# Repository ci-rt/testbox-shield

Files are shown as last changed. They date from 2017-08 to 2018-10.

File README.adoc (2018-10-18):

= TESTBOX
:toc:
:toclevels: 3

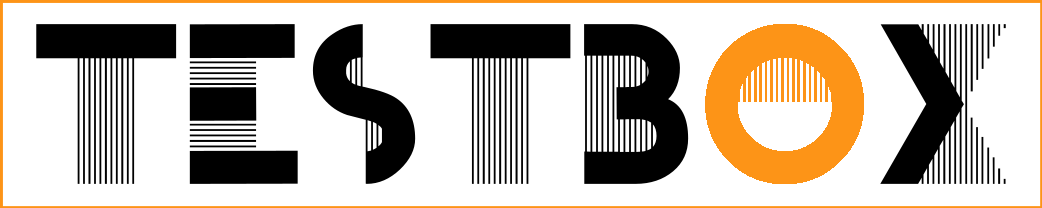
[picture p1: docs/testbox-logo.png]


This git repository hosts all related drawings, layouts and schematics
to build a TESTBOX test system.

But it doesn't include the project specific libraries. However they are
referenced as git submodules. To retrieve them use 'git submodule init' and
'git submodule update' before opening the project in kicad.

The project was verified to work with kicad version 5.

== preliminary remarks
One part of the Real Time Linux collaborative project is the continous
integration project https://ci-rt.linutronix.de/RT-Test/[CI-RT].

One part of the testsuite performs different tests on the devices under test
(DUT). To ease the hardware integration of the DUT to the test infrastructure
the DUT need to comply with some
https://ci-rt.linutronix.de/download/system-requirements.pdf[hardware
requirements].

It turned out that some DUTs need special hardware extensions to meet the
test infrastructure hardware requirements. Furthermore the wish for hardware
assisted tests grow up.

The idea of a standardized adaption system was born: the TESTBOX.

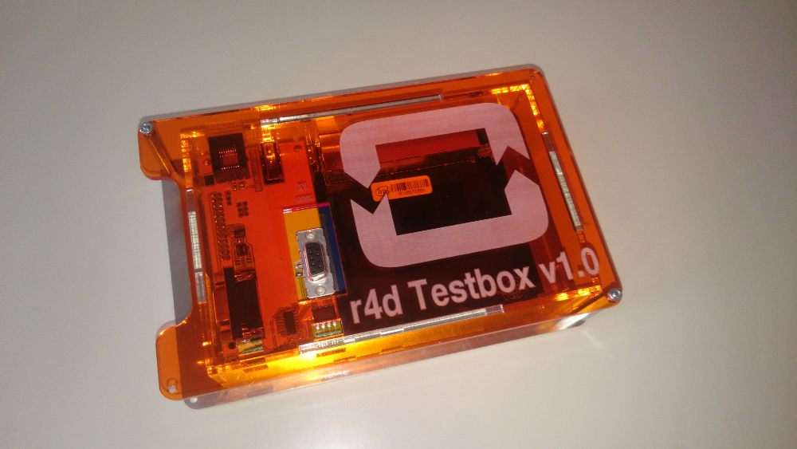
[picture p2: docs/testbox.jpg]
picture of the testbox


== hardware
The TESTBOX is based on the http://www.banana-pi.org/r1.html[Banana Pi R1
router board]. This board includes several physical interfaces:

 * 5-port Ethernet Switch
 * CAN
 * GPIOs
 * I2C
 * RS232
 * SPI
 * USB

The board is supported by the mainline
https://git.kernel.org/pub/scm/linux/kernel/git/stable/linux-stable.git/tree/arch/arm/boot/dts/sun7i-a20-lamobo-r1.dts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[Linux Kernel].
Since most interfaces are routed to pinheaders and lack of a physical adaption
a board shield was developed and is now available in version 2.

http://kicad-pcb.org[KiCAD] is used to create all schematics and the layout.

=== shield
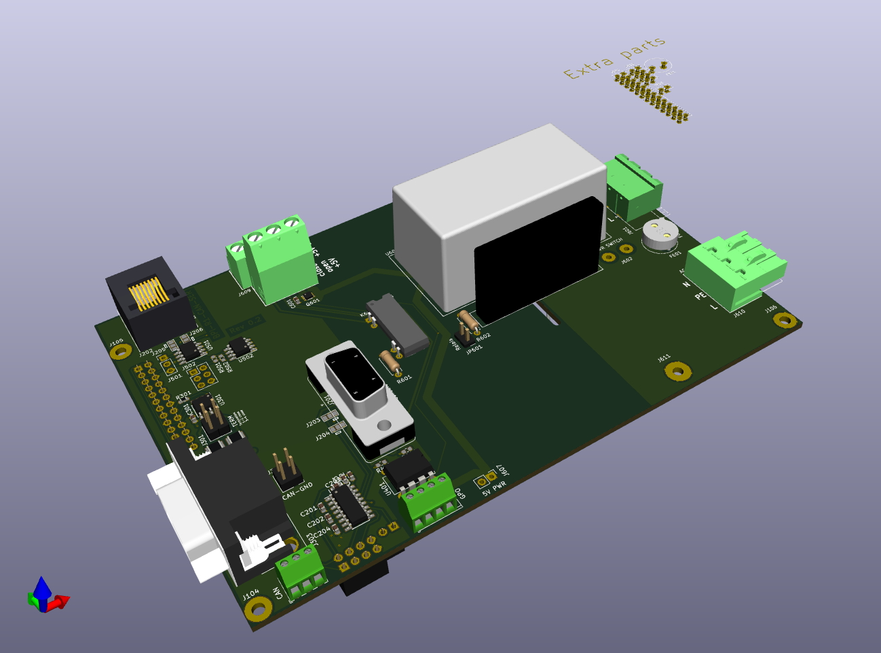
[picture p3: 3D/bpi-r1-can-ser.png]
picture of shield


Changes in version 2 of the shield:

 * 5V DC Powersupply added
 * 240V AC Powerswitch added
 * relay added
 * serial EEPROM added
 * secure store for private keys added (ATECC)
 * minor fixes

==== 3D model
A VRML model of the shield is also link:3D/bpi-r1-can-ser.wrl[available].

==== schematic
The complete schematic is available as
link:schematic/bpi-r1-can-ser.pdf[PDF].

===== overview
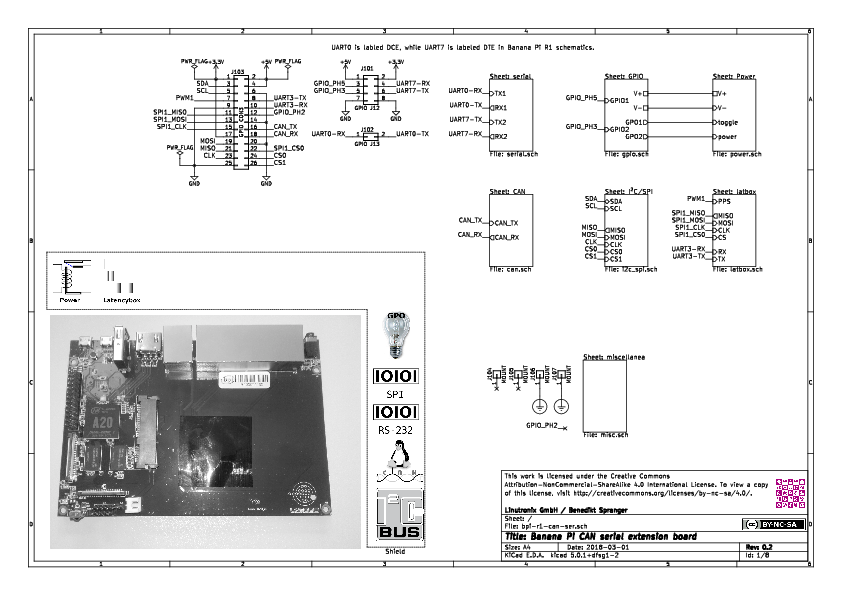
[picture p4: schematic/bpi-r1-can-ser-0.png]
schematic overview


===== serial ports
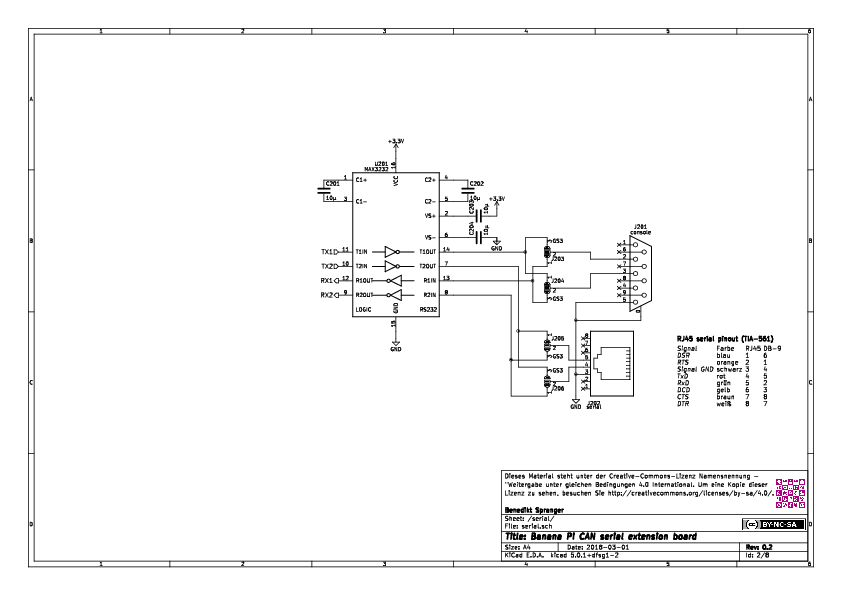
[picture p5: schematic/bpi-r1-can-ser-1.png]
serial port schematic


===== CAN interface
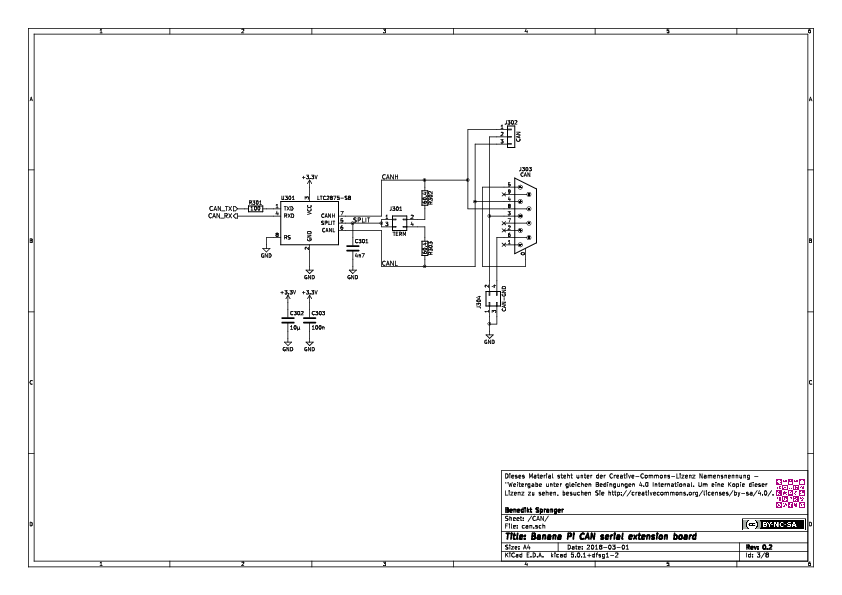
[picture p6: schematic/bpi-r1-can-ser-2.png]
CAN interface schematic


===== general purpose output
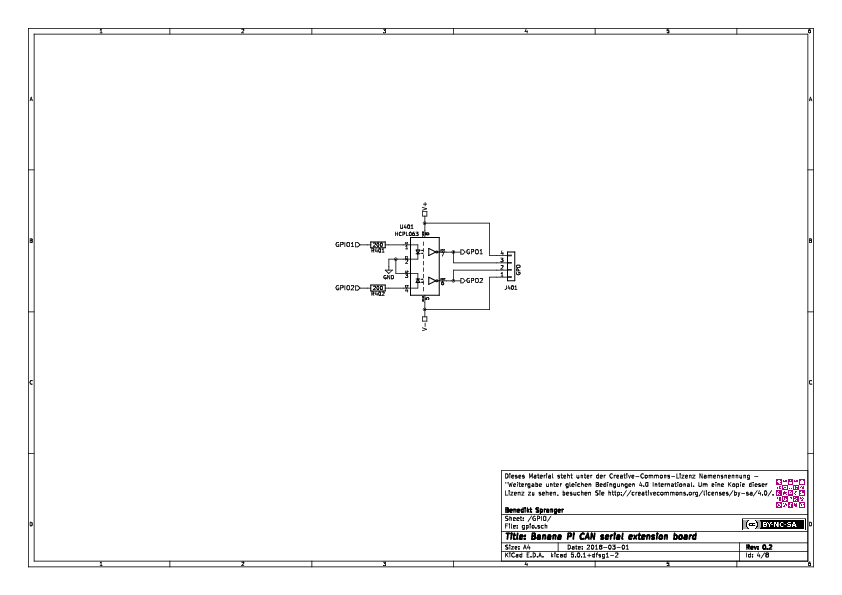
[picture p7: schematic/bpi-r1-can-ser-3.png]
GPO schematic


===== I2C / SPI
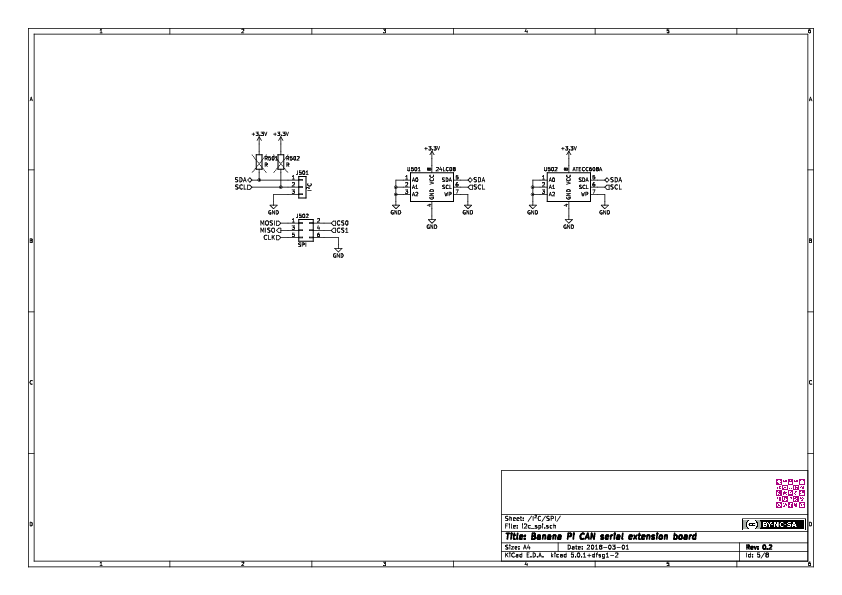
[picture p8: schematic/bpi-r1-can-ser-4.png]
I2C and SPI schematic


===== Power
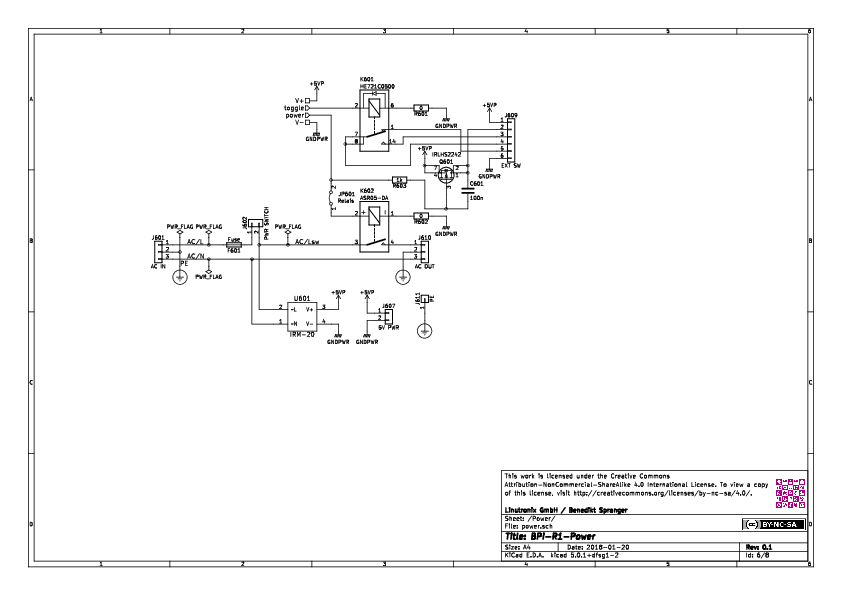
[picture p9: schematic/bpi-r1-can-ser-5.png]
I2C and SPI schematic


===== latbox (not implemented)
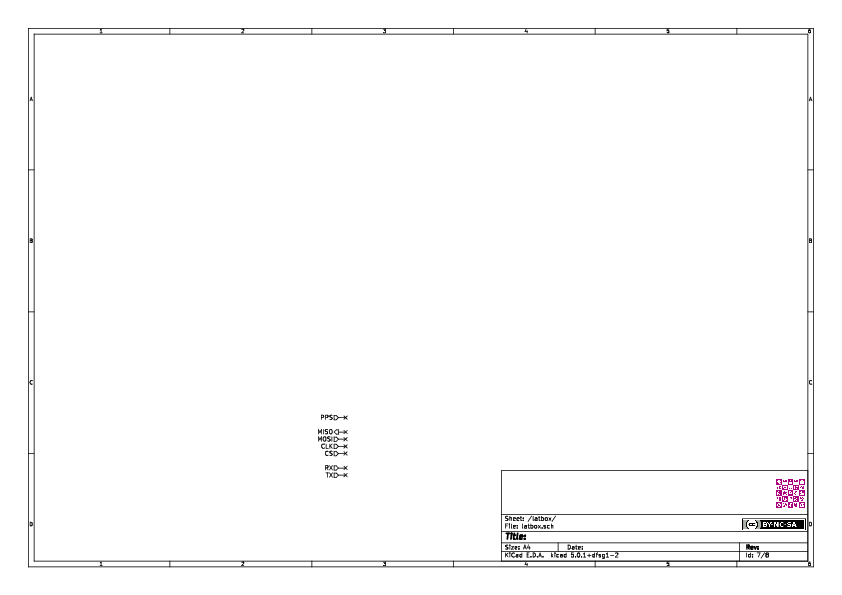
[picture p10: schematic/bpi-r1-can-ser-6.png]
I2C and SPI schematic


===== miscellanea
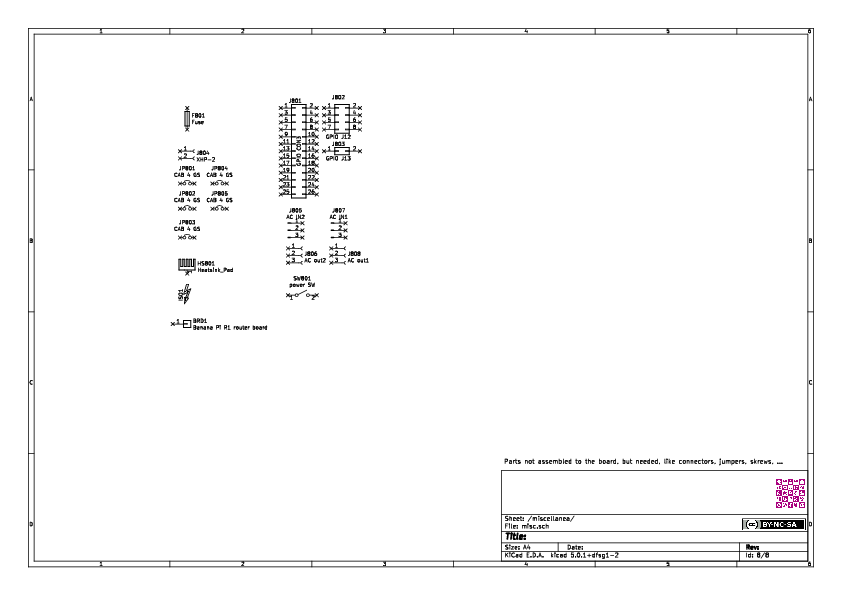
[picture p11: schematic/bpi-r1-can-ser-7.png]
I2C and SPI schematic


==== gerber
===== PCB edges and cuts
edges and cuts

===== top copper layer
PCB top layer

===== top silk screen
PCB top silk screen

===== bottom copper layer
PCB bottom copper layer

===== bottom silk screen
PCB bottom silk screen

==== Errata
===== TIA-561 serial port
The pinout of the RJ-45 connector was mixed up (off by one)

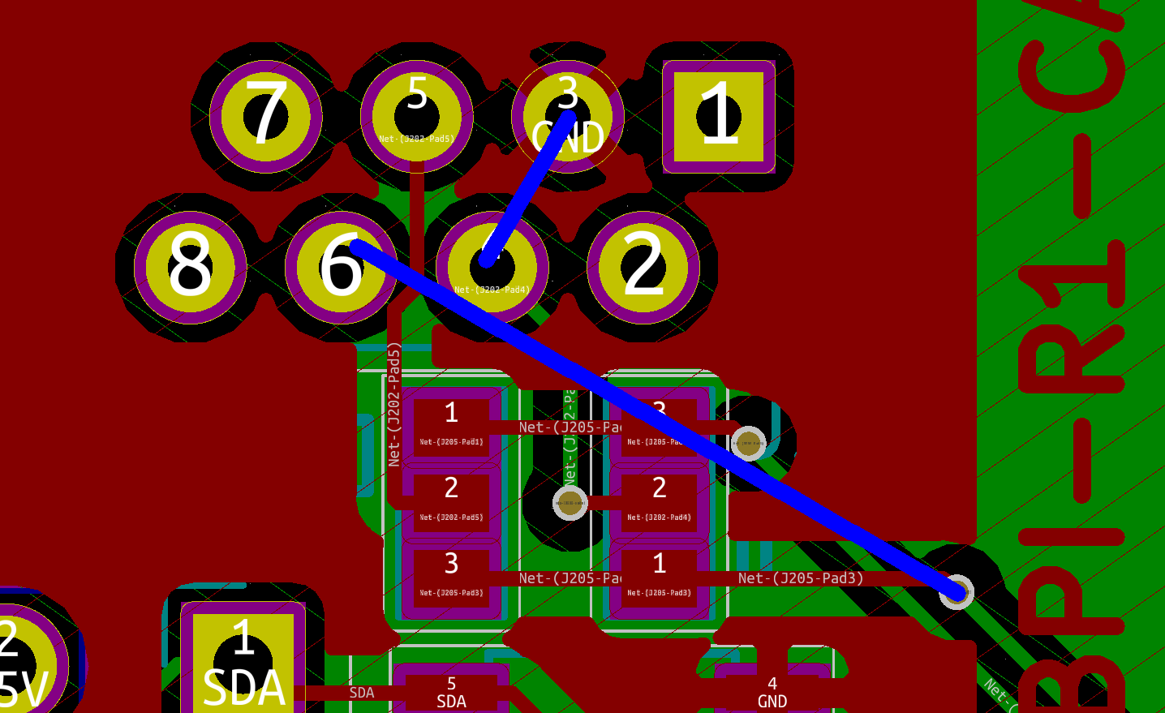
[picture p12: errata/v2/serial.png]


===== GPO
The optocoupler is open collector and not TTL. Add 100 Ohm pullups.

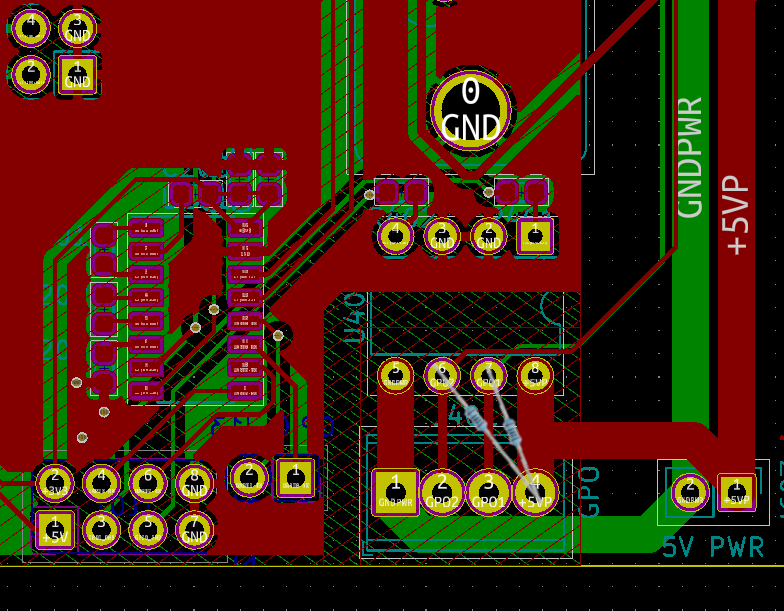
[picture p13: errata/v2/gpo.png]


== software
To create the root file system of the TESTBOX http://elbe-rfs.org/[E.L.B.E.]
is used. E.L.B.E. provides a reproducable way to create
http://debian.org[Debian-based] root file systems.

=== E.L.B.E. root file system
The receipe to build a root file system for the TESTBOX can be found under
https://github.com/ci-rt/testbox-rfs[].

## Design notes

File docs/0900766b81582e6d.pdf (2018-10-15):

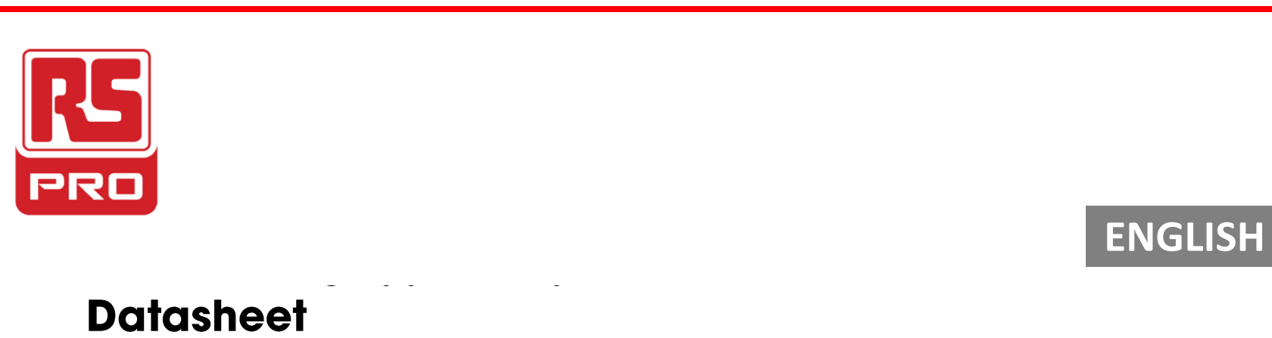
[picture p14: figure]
EN ENGLISH

RS Stock number 785-0827

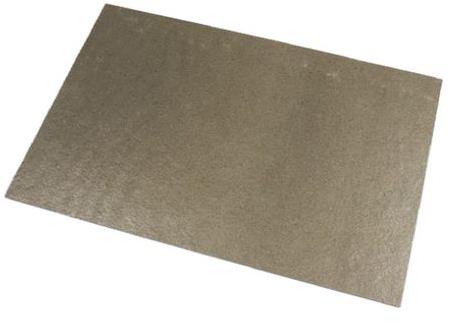
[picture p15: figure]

RS, Professionally Approved Products, gives you professional quality parts across all products categories. Our range has been testified by engineers as giving comparable quality to that of the leading brands without paying a premium price.

Description
Mica is a laminate designed for providing outstanding electrical insulation at high temperatures. It is environmentally safe and non-toxic, certified by UL-94V-0 (E67143M) and conforming to IEC 371-3-3

Applications
A special low smoke and blister free grade. It fully resists the extreme high temperature cycles and can be easily cut or punched.

Availability
Various sheet sizes, 0.1 – 1.5mm thick

Storage
Unlimited shelf life in a dry place at room temperature

RS, Professionally Approved Products, gives you professional quality parts across all products categories. Our range has been testified by engineers as giving comparable quality to that of the leading brands without paying a premium price.

## ENGLISH

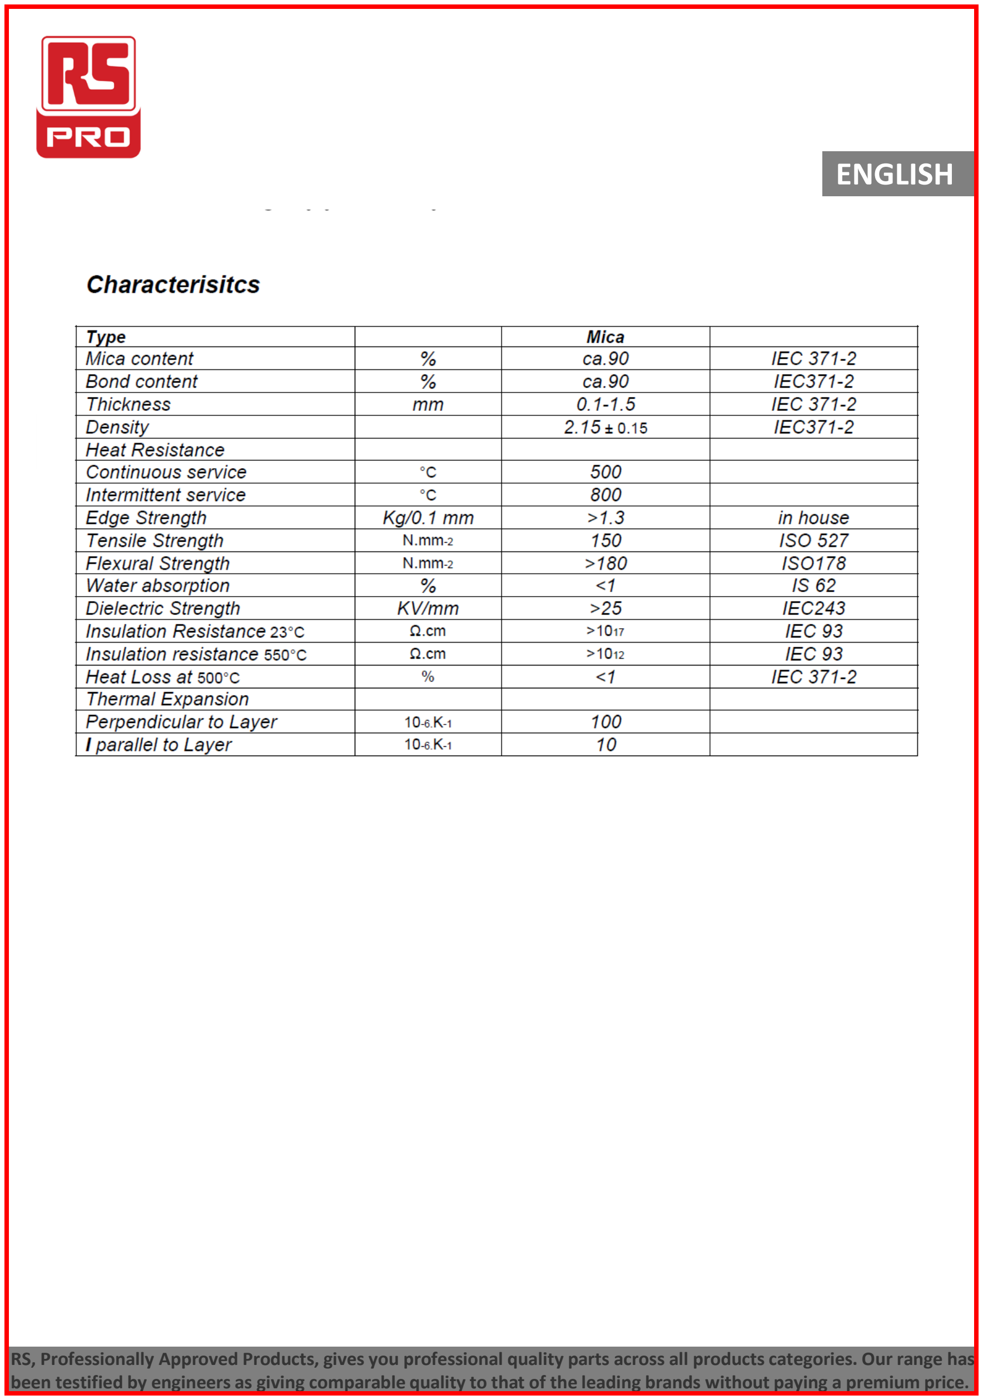
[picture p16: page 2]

EN

RS, Professionally Approved Products, gives you professional quality parts across all products categories. Our range has
been testified by engineers as giving comparable quality to that of the leading brands without paying a premium price.
RS, Professionally Approved Products, gives you professional quality parts across all products categories. Our range has been testified by engineers as giving comparable quality to that of the leading brands without paying a premium price.

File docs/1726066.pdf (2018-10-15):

https://www.phoenixcontact.com/gb/products/1726066

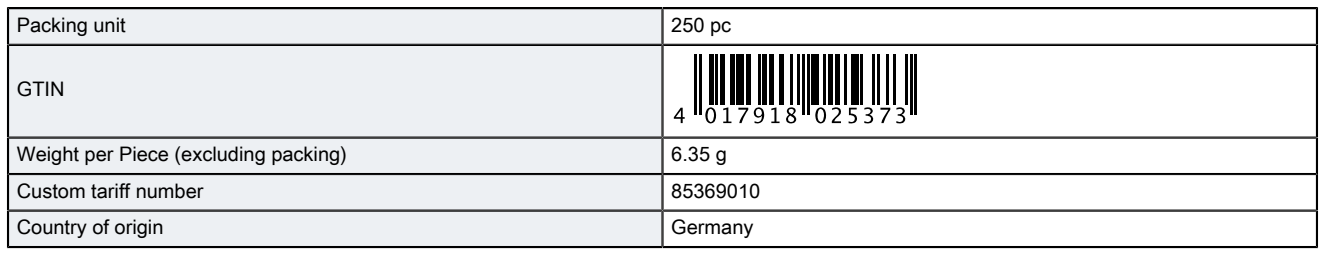
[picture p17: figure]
Packing unit; GTIN; Weight per Piece (excluding packing); Custom tariff number; Country of origin; Germany

19/01/2016 Page 1 / 6

PCB terminal block - MKKDSN 1,5/ 3-5,08 - 1726066 (https://www.phoenixcontact.com/gb/products/1726066)

Please be informed that the data shown in this PDF Document is generated from our Online Catalog. Please find the complete data in the user's documentation. Our General Terms of Use for Downloads are valid
(http://phoenixcontact.com/download)

PCB terminal block, Nominal current: 13.5 A, Nom. voltage: 400 V, Pitch: 5.08 mm, Number of positions: 3, Connection method: Screw connection with tension sleeve, Mounting: Wave soldering, Conductor/PCB connection direction: 0 °, Color: green, The article can be aligned to create different nos. of positions!

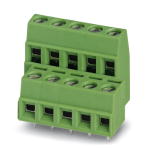
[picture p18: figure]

The illustration shows a 5-position version

### Why buy this product

Offset levels for optimum access to the terminal points Conductor cross sections up to 1.5 mm²
5.0 or 5.08 mm pitch
Compact housing dimensions and low design height Double-level type with high packing and connection density

## Key Commercial Data

## Technical data

### Dimensions

Length | 18.3 mm
Pitch | 5.08 mm
Dimension a | 10.16 mm
Constructional height | 20 mm
Length of the solder pin | 3.5 mm
Pin dimensions | 0,5 x 1 mm
Hole diameter | 1.3 mm

### General

Range of articles | MKKDSN 1,5

19/01/2016 Page 2 / 6

PCB terminal block - MKKDSN 1,5/ 3-5,08 - 1726066 (https://www.phoenixcontact.com/gb/products/1726066)

## Technical data

### General

Insulating material group | I
Rated surge voltage (III/3) | 4 kV
Rated surge voltage (III/2) | 4 kV
Rated surge voltage (II/2) | 4 kV
Rated voltage (III/3) | 250 V
Rated voltage (III/2) | 400 V
Rated voltage (II/2) | 630 V
Connection in acc. with standard | EN-VDE
Nominal current IN | 13.5 A
Nominal cross section | 1.5 mm²
Maximum load current | 13.5 A
Insulating material | PA
Solder pin surface | Sn
Flammability rating according to UL 94 | V0
Internal cylindrical gage | A1
Stripping length | 6 mm
Number of positions | 3
Screw thread | M3
Tightening torque, min | 0.5 Nm
Tightening torque max | 0.6 Nm

### Connection data

Conductor cross section solid min. | 0.14 mm²
Conductor cross section solid max. | 1.5 mm²
Conductor cross section flexible min. | 0.14 mm²
Conductor cross section flexible max. | 1.5 mm²
Conductor cross section flexible, with ferrule without plastic sleeve min. | 0.25 mm²
Conductor cross section flexible, with ferrule without plastic sleeve max. | 1 mm²
Conductor cross section flexible, with ferrule with plastic sleeve min. | 0.25 mm²
Conductor cross section flexible, with ferrule with plastic sleeve max. | 1 mm²
Conductor cross section AWG min. | 26
Conductor cross section AWG max. | 16
2 conductors with same cross section, solid min. | 0.14 mm²
2 conductors with same cross section, solid max. | 0.75 mm²
2 conductors with same cross section, stranded min. | 0.14 mm²
2 conductors with same cross section, stranded max. | 0.75 mm²
2 conductors with same cross section, stranded, ferrules without plastic sleeve, min. | 0.25 mm²
2 conductors with same cross section, stranded, ferrules without plastic sleeve, max. | 0.5 mm²
2 conductors with same cross section, stranded, TWIN ferrules with plastic sleeve, min. | 0.5 mm²

19/01/2016 Page 3 / 6

PCB terminal block - MKKDSN 1,5/ 3-5,08 - 1726066 (https://www.phoenixcontact.com/gb/products/1726066)

## Technical data

### Connection data

2 conductors with same cross section, stranded, TWIN ferrules with
plastic sleeve, max. | 0.5 mm²

### Standards and Regulations

Connection in acc. with standard | EN-VDE
| CSA
Flammability rating according to UL 94 | V0

## Classifications

### eCl@ss

eCl@ss 4.0 | 27141109
eCl@ss 4.1 | 27141109
eCl@ss 5.0 | 27141190
eCl@ss 5.1 | 27141190
eCl@ss 6.0 | 27261101
eCl@ss 7.0 | 27440401
eCl@ss 8.0 | 27440401

### ETIM

ETIM 3.0 | EC001121
ETIM 4.0 | EC002643
ETIM 5.0 | EC002643

### UNSPSC

UNSPSC 6.01 | 30211801
UNSPSC 7.0901 | 39121432
UNSPSC 11 | 39121432
UNSPSC 12.01 | 39121432
UNSPSC 13.2 | 39121432

## Approvals

### Approvals

Approvals

CSA / UL Recognized / SEV / cUL Recognized / CCA / IECEE CB Scheme / SEV / EAC / cULus Recognized

Ex Approvals

19/01/2016 Page 4 / 6

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

## Approvals

Approvals submitted

### Approval details

CSA
| B | D
mm²/AWG/kcmil | 28-14 | 28-14
Nominal current IN | 10 A | 10 A
Nominal voltage UN | 150 V | 300 V

UL Recognized
| B | D
mm²/AWG/kcmil | 30-14 | 30-14
Nominal current IN | 10 A | 10 A
Nominal voltage UN | 300 V | 300 V

SEV

mm²/AWG/kcmil | 1.5
Nominal current IN | 13.5 A
Nominal voltage UN | 250 V

cUL Recognized
| B | D
mm²/AWG/kcmil | 30-14 | 30-14
Nominal current IN | 10 A | 10 A
Nominal voltage UN | 300 V | 300 V

CCA

IECEE CB Scheme

19/01/2016 Page 5 / 6

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

## Approvals

SEV

mm²/AWG/kcmil | 1.5
Nominal current IN | 13.5 A
Nominal voltage UN | 250 V

EAC

cULus Recognized

## Accessories

### Accessories Bridge

Insertion bridge - EBP 2- 5 - 1733169 (https://www.phoenixcontact.com/gb/products/1733169)

Insertion bridge, fully insulated, for connectors with 5.0 or 5.08 mm pitch, no. of positions: 2

Insertion bridge - EBP 3- 5 - 1733172 (https://www.phoenixcontact.com/gb/products/1733172)

Insertion bridge, fully insulated, for connectors with 5.0 or 5.08 mm pitch, no. of positions: 3

### Labeled terminal marker

Marker card - SK 5,08/3,8:FORTL.ZAHLEN - 0804293 (https://www.phoenixcontact.com/gb/products/0804293)

Marker card, Card, white, labeled, Horizontal: Consecutive numbers 1 - 10, 11 - 20, etc. up to 91 - (99)100, Mounting type: Adhesive, for terminal block width: 5.08 mm, Lettering field: 5.08 x 3.8 mm

### Screwdriver tools

19/01/2016 Page 6 / 6

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

## Accessories

Screwdriver - SZS 0,6X3,5 - 1205053 (https://www.phoenixcontact.com/gb/products/1205053)

Actuation tool, for ST terminal blocks, insulated, also suitable for use as a bladed screwdriver, size: 0.6 x 3.5 x 100 mm, 2-component grip, with non-slip grip

### Terminal marking

Marker card - SK 5,08/3,8:UNBEDRUCKT - 0805412 (https://www.phoenixcontact.com/gb/products/0805412)

Marker card, Card, white, unlabeled, can be labeled with: Marker pen, Mounting type: Adhesive, for terminal block width: 5.08 mm, Lettering field: 5.08 x 3.8 mm

## Drawings

Drilling diagram 4,05 | 1,3

a 10,16

5,08 | 2,54

Dimensional drawing 19,1

4,05 ¹⁰ 3,5

18,3

a

10,16 | 2,54 | 5,08
a+5,08 | 2,54

Phoenix Contact 2016 © - all rights reserved http://www.phoenixcontact.com

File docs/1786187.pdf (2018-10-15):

https://www.phoenixcontact.com/us/produkte/1786187

Nov 13, 2013 1 / 7

Printed-circuit board connector - IC 2,5/ 3-ST-5,08 - 1786187 (https://www.phoenixcontact.com/de/produkte/1786187)

Please be informed that the data shown in this PDF Document is generated from our Online Catalog. Please find the complete data in the user's documentation. Our General Terms of Use for Downloads are valid
(http://download.phoenixcontact.com)

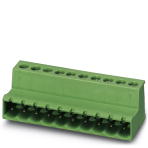
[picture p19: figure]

The figure shows a 10-position version of the product

Plug component, Nominal current: 12 A, Rated voltage (III/2): 320 V, Number of positions: 3, Pitch: 5.08 mm, Connection method: Screw connection, Color: green, Contact surface: Tin

### Product Features

Can be combined with inverted base strips and plugs for shock-proof applications Plug with inverted contact system (pin contact)

## Key commercial data

package_quantity | 50
GTIN | 4017918042332

## Technical data

### Dimensions

Pitch | 5.08 mm
Dimension a | 10.16 mm

### General

Range of articles | IC 2,5/..-ST
Insulating material group | I
Rated surge voltage (III/3) | 4 kV
Rated surge voltage (III/2) | 4 kV
Rated surge voltage (II/2) | 4 kV
Rated voltage (III/3) | 250 V
Rated voltage (III/2) | 320 V
Rated voltage (II/2) | 630 V
Connection in acc. with standard | EN-VDE
Nominal current IN | 12 A
Nominal cross section | 2.5 mm²
Maximum load current | 12 A
Insulating material | PA
Inflammability class according to UL 94 | V0
Internal cylindrical gage | A3
Stripping length | 7 mm
Number of positions | 3

Nov 13, 2013 2 / 7

Printed-circuit board connector - IC 2,5/ 3-ST-5,08 - 1786187 (https://www.phoenixcontact.com/de/produkte/1786187)

## Technical data

### General

Screw thread | M3
Tightening torque, min | 0.5 Nm
Tightening torque max | 0.6 Nm

### Connection data

Conductor cross section solid min. | 0.2 mm²
Conductor cross section solid max. | 2.5 mm²
Conductor cross section stranded min. | 0.2 mm²
Conductor cross section stranded max. | 2.5 mm²
Conductor cross section stranded, with ferrule without plastic sleeve min. | 0.25 mm²
Conductor cross section stranded, with ferrule without plastic sleeve max. | 2.5 mm²
Conductor cross section stranded, with ferrule with plastic sleeve min. | 0.25 mm²
Conductor cross section stranded, with ferrule with plastic sleeve max. | 2.5 mm²
Conductor cross section AWG/kcmil min. | 24
Conductor cross section AWG/kcmil max | 12
2 conductors with same cross section, solid min. | 0.2 mm²
2 conductors with same cross section, solid max. | 1 mm²
2 conductors with same cross section, stranded min. | 0.2 mm²
2 conductors with same cross section, stranded max. | 1.5 mm²
2 conductors with same cross section, stranded, ferrules without plastic sleeve, min. | 0.25 mm²
2 conductors with same cross section, stranded, ferrules without plastic sleeve, max. | 1 mm²
2 conductors with same cross section, stranded, TWIN ferrules with plastic sleeve, min. | 0.5 mm²
2 conductors with same cross section, stranded, TWIN ferrules with plastic sleeve, max. | 1.5 mm²
Minimum AWG according to UL/CUL | 30
Maximum AWG according to UL/CUL | 12

## classifications

### eCl@ss

eCl@ss 4.0 | 272607xx
eCl@ss 4.1 | 27260701
eCl@ss 5.0 | 27260701
eCl@ss 5.1 | 27260701
eCl@ss 6.0 | 27260704
eCl@ss 7.0 | 27440402
eCl@ss 8.0 | 27440402

Nov 13, 2013 3 / 7

Printed-circuit board connector - IC 2,5/ 3-ST-5,08 - 1786187 (https://www.phoenixcontact.com/de/produkte/1786187)

## classifications

### ETIM

ETIM 3.0 | EC001121
ETIM 4.0 | EC002638
ETIM 5.0 | EC002638

### UNSPSC

UNSPSC 6.01 | 30211810
UNSPSC 7.0901 | 39121409
UNSPSC 11 | 39121409
UNSPSC 12.01 | 39121409
UNSPSC 13.2 | 39121409

## approvals

CSA / UL Recognized / VDE Gutachten mit Fertigungsüberwachung / cUL Recognized / GOST / IECEE CB Scheme / GOST / CCA / cULus Recognized /

### Approval details

CSA
Usegroups | B | D
Nominal voltage UN | 300 V | 300 V
Nominal current IN | 10 A | 10 A
mm²/AWG/kcmil | 28-12 | 28-12

UL Recognized
Usegroups | B | D
Nominal voltage UN | 250 V | 300 V
Nominal current IN | 12 A | 10 A
mm²/AWG/kcmil | 30-12 | 30-12

VDE Gutachten mit Fertigungsüberwachung

Nominal voltage UN | 250 V
Nominal current IN | 12 A
mm²/AWG/kcmil | 0.2-2.5

Nov 13, 2013 4 / 7

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

## approvals

cUL Recognized
Usegroups | B | D
Nominal voltage UN | 250 V | 300 V
Nominal current IN | 12 A | 10 A
mm²/AWG/kcmil | 30-12 | 30-12

GOST

IECEE CB Scheme

Nominal voltage UN | 250 V
Nominal current IN | 12 A
mm²/AWG/kcmil | 0.2-2.5

CCA

Nominal voltage UN | 250 V
Nominal current IN | 12 A
mm²/AWG/kcmil | 0.2-2.5

cULus Recognized

## accessories

### Filler plug

MSTB-BL - 1755477 (https://www.phoenixcontact.com/de/produkte/1755477)

Nov 13, 2013 5 / 7

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

## accessories

### Bridge

EBP 2- 5 - 1733169 (https://www.phoenixcontact.com/de/produkte/1733169)

### Screwdriver tools

SZS 0,6X3,5 - 1205053 (https://www.phoenixcontact.com/de/produkte/1205053)

### Coding element

CR-MSTB - 1734401 (https://www.phoenixcontact.com/de/produkte/1734401)

### Labeled terminal marker

SK 5,08/3,8:FORTL.ZAHLEN - 0804293 (https://www.phoenixcontact.com/de/produkte/0804293)

### Cable housing

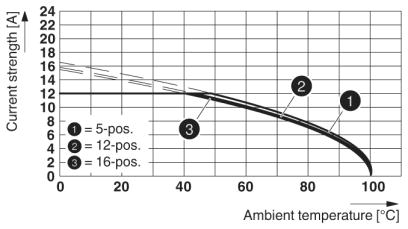
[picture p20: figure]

Nov 13, 2013 6 / 7

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

## accessories

KGG-MSTB 2,5/ 2 - 1803934 (https://www.phoenixcontact.com/de/produkte/1803934)

KGS-MSTB 2,5/ 8 - 1783779 (https://www.phoenixcontact.com/de/produkte/1783779)

## Drawings

Diagram

Type: (U)MSTBVK 2,5/...-ST-5,08 with IC 2,5/...-ST-5,08

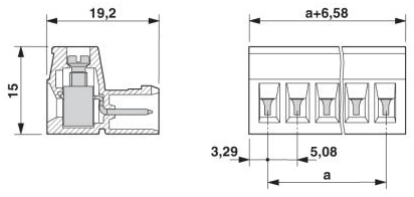
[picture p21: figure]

Nov 13, 2013 7 / 7

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

Dimensioned drawing

© Phoenix Contact 2013 - all rights reserved http://www.phoenixcontact.com

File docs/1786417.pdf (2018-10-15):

https://www.phoenixcontact.com/us/produkte/1786417

Nov 13, 2013 1 / 6

Base strip - IC 2,5/ 3-G-5,08 - 1786417 (https://www.phoenixcontact.com/de/produkte/1786417)

Please be informed that the data shown in this PDF Document is generated from our Online Catalog. Please find the complete data in the user's documentation. Our General Terms of Use for Downloads are valid
(http://download.phoenixcontact.com)

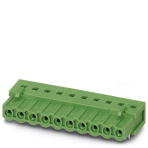
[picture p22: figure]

The figure shows a 10-position version of the product

Header, Nominal current: 12 A, Rated voltage (III/2): 320 V, Number of positions: 3, Pitch: 5.08 mm, Color: green, Contact surface: Tin, Assembly: Soldering

### Product Features

Combination with MSTB 2,5 headers for primary/secondary/PCB connection Pairs of guide rails can be used as a 90° board-to-board connection
Use in shock-proof applications
Clear separation of PCB inputs/outputs

## Key commercial data

package_quantity | 50
GTIN | 4017918042561

## Technical data

### Dimensions

Length | 19 mm
Pitch | 5.08 mm
Dimension a | 10.16 mm
Pin dimensions | 1,2 x 0,5
Hole diameter | 1.4 mm

### General

Range of articles | IC 2,5/..-G
Insulating material group | I
Rated surge voltage (III/3) | 4 kV
Rated surge voltage (III/2) | 4 kV
Rated surge voltage (II/2) | 4 kV
Rated voltage (III/3) | 320 V
Rated voltage (III/2) | 320 V
Rated voltage (II/2) | 630 V
Connection in acc. with standard | EN-VDE
Nominal current IN | 12 A
Maximum load current | 12 A
Insulating material | PA

Nov 13, 2013 2 / 6

Base strip - IC 2,5/ 3-G-5,08 - 1786417 (https://www.phoenixcontact.com/de/produkte/1786417)

## Technical data

### General

Inflammability class according to UL 94 | V0
Color | green
Number of positions | 3

## classifications

### eCl@ss

eCl@ss 4.0 | 272607xx
eCl@ss 4.1 | 27260701
eCl@ss 5.0 | 27260701
eCl@ss 5.1 | 27260701
eCl@ss 6.0 | 27260704
eCl@ss 7.0 | 27440402
eCl@ss 8.0 | 27440402

### ETIM

ETIM 3.0 | EC001121
ETIM 4.0 | EC002637
ETIM 5.0 | EC002637

### UNSPSC

UNSPSC 6.01 | 30211810
UNSPSC 7.0901 | 39121409
UNSPSC 11 | 39121409
UNSPSC 12.01 | 39121409
UNSPSC 13.2 | 39121409

## approvals

CSA / UL Recognized / VDE Gutachten mit Fertigungsüberwachung / cUL Recognized / GOST / IECEE CB Scheme / GOST / CCA / cULus Recognized /

### Approval details

CSA
Usegroups | B | D
Nominal voltage UN | 300 V | 300 V
Nominal current IN | 10 A | 10 A
mm²/AWG/kcmil

Nov 13, 2013 3 / 6

Base strip - IC 2,5/ 3-G-5,08 - 1786417 (https://www.phoenixcontact.com/de/produkte/1786417)

## approvals

UL Recognized
Usegroups | B | D
Nominal voltage UN | 250 V | 300 V
Nominal current IN | 12 A | 10 A
mm²/AWG/kcmil

VDE Gutachten mit Fertigungsüberwachung

Nominal voltage UN | 250 V
Nominal current IN | 12 A
mm²/AWG/kcmil

cUL Recognized
Usegroups | B | D
Nominal voltage UN | 250 V | 300 V
Nominal current IN | 12 A | 10 A
mm²/AWG/kcmil

GOST

IECEE CB Scheme

Nominal voltage UN | 250 V
Nominal current IN | 12 A
mm²/AWG/kcmil

CCA

Nominal voltage UN | 250 V

Nov 13, 2013 4 / 6

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

## approvals

Nominal current IN | 12 A
mm²/AWG/kcmil

cULus Recognized

## accessories

### Test plug terminal block

MPS-MT - 0201744 (https://www.phoenixcontact.com/de/produkte/0201744)

RPS - 0201647 (https://www.phoenixcontact.com/de/produkte/0201647)

### Coding element

CP-MSTB - 1734634 (https://www.phoenixcontact.com/de/produkte/1734634)

## Drawings

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

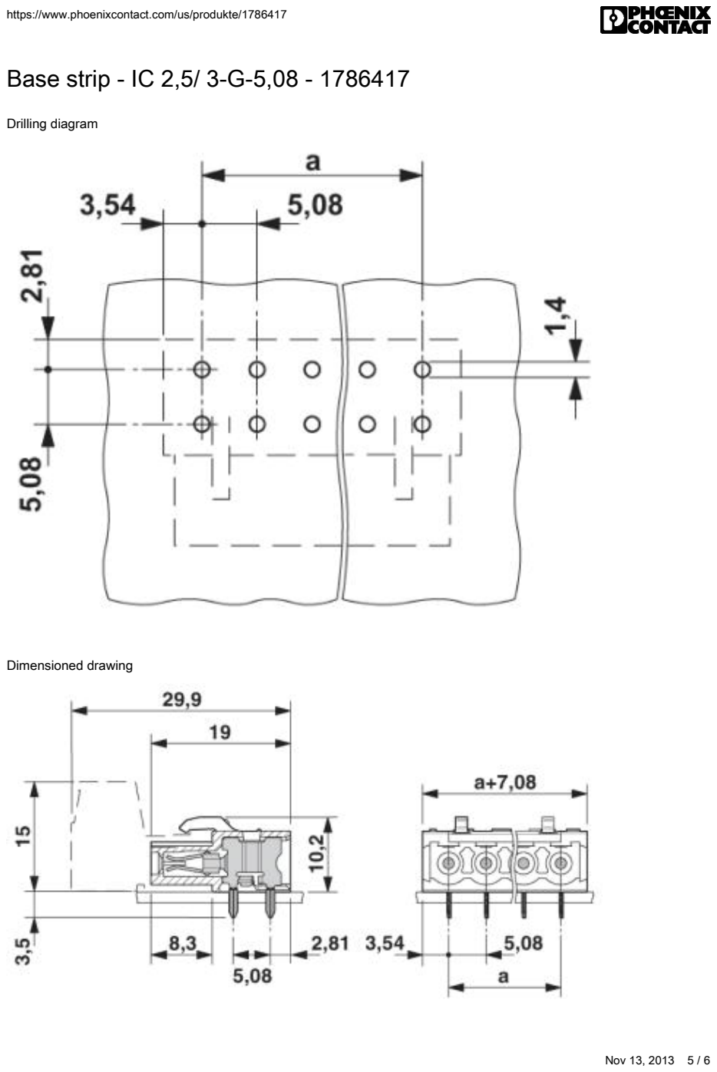
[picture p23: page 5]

Nov 13, 2013 5 / 6

Drilling diagram

Dimensioned drawing

Nov 13, 2013 6 / 6

© Phoenix Contact 2013 - all rights reserved http://www.phoenixcontact.com

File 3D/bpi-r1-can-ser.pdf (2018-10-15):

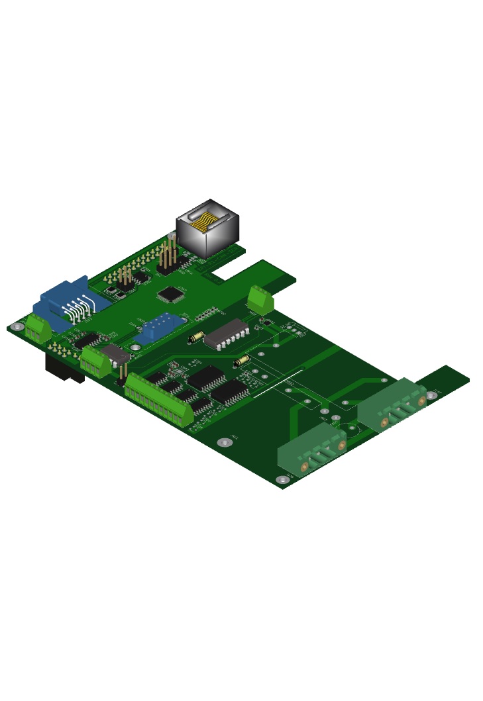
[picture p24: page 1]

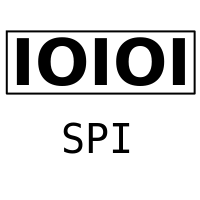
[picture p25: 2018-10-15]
docs/SPI.png

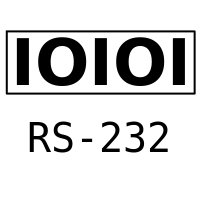
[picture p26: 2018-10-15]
docs/rs232.png

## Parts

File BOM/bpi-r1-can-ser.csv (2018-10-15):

Source: | /home/bene/work/projects/bpi-r1-can-ser/bpi-r1-can-ser.sch
Date: | Di 14 Aug 2018 19:02:29 CEST
Tool: | Eeschema 5.0.0+dfsg1-1
Generator: | /usr/share/kicad/plugins/bom_csv_grouped_by_value.py
Component Count: | 73
Individual Components:
Item | Qty | Reference(s) | Value | LibPart | Footprint | Datasheet | Critical | Description | ManuPart# | Manufacture | PackageID | Source | SupplLink | SupplPart# | assemble
 |  | BRD1 | Banana Pi R1 router board | conn_generic:Conn_01x01 |  | docs/BPI-R1USERMANUAL.pdf | N | Banana Pi Router, 2x 1 GHz, 1 GB, Wi-Fi, 4x 1 Gbit |  |  |  | Reichelt | https://www.reichelt.de/banana-pi-router-2x-1-ghz-1-gb-wi-fi-4x-1-gbit-banana-pi-r1-p150228.html | BANANA PI R1 | EXT
 |  | C201 | 10µ | device:C | Capacitor_SMD:C_0603_1608Metric | docs/GRM188R6YA106MA73#.pdf | N | CAP CER 10UF 35V X5R 0603 | GRM188R6YA106MA73D | Murata Electronics North America | 0603 | Digikey | https://www.digikey.de/product-detail/de/murata-electronics-north-america/GRM188R6YA106MA73D/490-13248-1-ND/5877456 | 490-13248-1-ND | Y
 |  | C202 | 10µ | device:C | Capacitor_SMD:C_0603_1608Metric | docs/GRM188R6YA106MA73#.pdf | N | CAP CER 10UF 35V X5R 0603 | GRM188R6YA106MA73D | Murata Electronics North America | 0603 | Digikey | https://www.digikey.de/product-detail/de/murata-electronics-north-america/GRM188R6YA106MA73D/490-13248-1-ND/5877456 | 490-13248-1-ND | Y
 |  | C203 | 10µ | device:C | Capacitor_SMD:C_0603_1608Metric | docs/GRM188R6YA106MA73#.pdf | N | CAP CER 10UF 35V X5R 0603 | GRM188R6YA106MA73D | Murata Electronics North America | 0603 | Digikey | https://www.digikey.de/product-detail/de/murata-electronics-north-america/GRM188R6YA106MA73D/490-13248-1-ND/5877456 | 490-13248-1-ND | Y
 |  | C204 | 10µ | device:C | Capacitor_SMD:C_0603_1608Metric | docs/GRM188R6YA106MA73#.pdf | N | CAP CER 10UF 35V X5R 0603 | GRM188R6YA106MA73D | Murata Electronics North America | 0603 | Digikey | https://www.digikey.de/product-detail/de/murata-electronics-north-america/GRM188R6YA106MA73D/490-13248-1-ND/5877456 | 490-13248-1-ND | Y
 |  | C301 | 4n7 | device:C | Capacitor_SMD:C_0603_1608Metric | docs/S_CL10B472KB8NNNC.pdf | N | CAP CER 4700PF 50V X7R 0603 | CL10B472KB8NNNC | Samsung Electro-Mechanics America, Inc. | 0603 | Digikey | https://www.digikey.de/product-detail/de/samsung-electro-mechanics-america-inc/CL10B472KB8NNNC/1276-1098-1-ND/3889184 | 1276-1098-1-ND | Y
 |  | C302 | 10µ | device:C | Capacitor_SMD:C_0603_1608Metric | docs/GRM188R6YA106MA73#.pdf | N | CAP CER 10UF 35V X5R 0603 | GRM188R6YA106MA73D | Murata Electronics North America | 0603 | Digikey | https://www.digikey.de/product-detail/de/murata-electronics-north-america/GRM188R6YA106MA73D/490-13248-1-ND/5877456 | 490-13248-1-ND | Y
 |  | C303 | 100n | device:C | Capacitor_SMD:C_0603_1608Metric | docs/C_CL10F104ZO8NNNC.pdf | N | CAP CER 0.1UF 16V Y5V 0603 | CL10F104ZO8NNNC | Samsung Electro-Mechanics America, Inc. | 0603 | Digikey | https://www.digikey.de/product-detail/de/samsung-electro-mechanics-america-inc/CL10F104ZO8NNNC/1276-1258-1-ND/3889344 | 1276-1258-1-ND | Y
 |  | C601 | 100n | device:C | Capacitor_SMD:C_0603_1608Metric | docs/C_CL10F104ZO8NNNC.pdf | N | CAP CER 0.1UF 16V Y5V 0603 | CL10F104ZO8NNNC | Samsung Electro-Mechanics America, Inc. | 603 | Digikey | https://www.digikey.de/product-detail/de/samsung-electro-mechanics-america-inc/CL10F104ZO8NNNC/1276-1258-1-ND/3889344 | 1276-1258-1-ND | Y
 |  | F601 | Fuse | device:Fuse | Fuse:Fuseholder_TR5_Littlefuse_No560_No460 | docs/typ_FMS__250V_.pdf | N | FUSE HOLDER RADIAL 250V 5A PCB | 0031.7601 | SCHURTER | TR5 | TME | https://www.tme.eu/de/details/0031.7601/sicherungsdosen-pcb/schurter/ | 0031.7601 | Y
 |  | F801 | Fuse | device:Fuse | littelfuse_370:fuse_littelfuse_370 | docs/Littelfuse_Fuse_370-3.pdf | N | FUSE BOARD MOUNT 5A 250VAC RAD | 37015000430 | Littelfuse Inc. | TR5 | TME | https://www.tme.eu/de/details/37015000430/flinke-sicherungen-tr5/littelfuse/ | 37015000430 | EXT
 |  | HS801 | Heatsink_Pad | Mechanical:Heatsink_Pad |  | docs/Kerafol_Datenblaetter_86_200_03-18.pdf | N | SOFTTHERM® Films | 86/200 | KERAFOL Keramische Folien GmbH |  | Conrad | https://www.conrad.de/de/waermeleitfolie-5-mm-3-wmk-l-x-b-50-mm-x-50-mm-kerafol-86300-189042.html | 189042 - 62 | EXT
 |  | ISO1 | SYM_Flash_Small | Graphic:SYM_Flash_Small |  | docs/0900766b81582e6d.pdf | N | isolation film | 785-0827 | RS components |  | RS | https://de.rs-online.com/web/p/elektrisch-chemisch-isolierende-folien/7850827/ | 785-0827 | EXT
 |  | J101 | GPIO J12 | conn_generic:Conn_02x04_Odd_Even | Connector_PinSocket_2.54mm:PinSocket_2x04_P2.54mm_Vertical | docs/DS1023.pdf | N | CONN HEADER FMALE 8PS .1" DL TIN | DS1023-2*4S01 | CONNFLY |  | TME | http://www.tme.eu/de/details/zl262-8dg/stiftleisten-und-buchsen/connfly/ds1023-2_13s01/ | ZL262-8DG | Y
 |  | J102 | GPIO J13 | conn_generic:Conn_02x01 | Connector_PinSocket_2.54mm:PinSocket_2x01_P2.54mm_Vertical | docs/DS1023.pdf | N | CONN HEADER FEMALE 2POS .1" TIN | DS1023-1*2S01 | CONNFLY |  | TME | http://www.tme.eu/de/details/zl262-2sg/stiftleisten-und-buchsen/connfly/ds1023-1_2s01/ | ZL262-2SG | Y
 |  | J103 | GPIO CON3 | conn_generic:Conn_02x13_Odd_Even | Connector_PinSocket_2.54mm:PinSocket_2x13_P2.54mm_Vertical | docs/DS1023.pdf | N | CONN HEADER FMAL 26PS .1" DL TIN | DS1023-2*13S01 | CONNFLY |  | TME | http://www.tme.eu/de/details/zl262-26dg/stiftleisten-und-buchsen/connfly/ds1023-2_13s01/ | ZL262-26DG | Y
 |  | J104 | MOUNT | conn_generic:Conn_01x01 | MountingHole:MountingHole_2.7mm_M2.5_Pad |  | N |  |  |  |  |  |  |  | N
 |  | J105 | MOUNT | conn_generic:Conn_01x01 | MountingHole:MountingHole_2.7mm_M2.5_Pad |  | N |  |  |  |  |  |  |  | N
 |  | J106 | MOUNT | conn_generic:Conn_01x01 | MountingHole:MountingHole_2.7mm_M2.5_Pad |  | N |  |  |  |  |  |  |  | N
 |  | J107 | MOUNT | conn_generic:Conn_01x01 | MountingHole:MountingHole_2.7mm_M2.5_Pad |  | N |  |  |  |  |  |  |  | N
 |  | J201 | console | conn:DB9_Female_MountingHoles | Connector_Dsub:DSUB-9_Female_Vertical_P2.77x2.84mm_MountingHoles | docs/DS1034.pdf | N | CONN D-SUB RCPT 9POS VERT SOLDER | DS1034-09FUNSISS | CONNFLY |  | TME | http://www.tme.eu/de/details/df09pp/d-sub-steckverbinder/connfly/ds1034-09funsiss/ | DF09PP | Y
 |  | J202 | serial | conn:RJ45 | Connector_RJ:RJ45_Amphenol_54602-x08_Horizontal | docs/c-bmj-0102.pdf | N | CONN MOD JACK 8P8C R/A UNSHLD | 955012881 | Molex |  | TME | http://www.tme.eu/de/details/mx-95501-2881/rj-steckverbinder/molex/955012881/ | MX-95501-2881 | Y
 |  | J203 | GS3 | jumper:SolderJumper_3_Bridged12 | Connectors:GS3 |  | N |  |  |  |  |  |  |  | N
 |  | J204 | GS3 | Jumper:SolderJumper_3_Bridged12 | Connectors:GS3 |  | N |  |  |  |  |  |  |  | N
 |  | J205 | GS3 | Jumper:SolderJumper_3_Bridged12 | Connectors:GS3 |  | N |  |  |  |  |  |  |  | N
 |  | J206 | GS3 | Jumper:SolderJumper_3_Bridged12 | Connectors:GS3 |  | N |  |  |  |  |  |  |  | N
 |  | J301 | TERM | conn_generic:Conn_02x02_Odd_Even | Connector_PinHeader_2.54mm:PinHeader_2x02_P2.54mm_Vertical | docs/DS1021.pdf | N | CONN HEADER 4POS .100 STR TIN | DS1021-2*2SF1-1 | CONNFLY |  | TME | http://www.tme.eu/de/details/zl202-4g/stiftleisten-und-buchsen/connfly/ds1021-2_2sf1-1/ | ZL202-4G | Y
 |  | J302 | CAN | conn_generic:Conn_01x03 | TerminalBlock_Phoenix:TerminalBlock_Phoenix_MPT-0,5-3-2.54_1x03_P2.54mm_Horizontal | docs/1725669.pdf | N | CONN TERM BLOCK 2.54MM 3POS | 1725669 | Phoenix Contact |  | TME | http://www.tme.eu/de/details/mpt0.5_3-2.54/klemmleisten-fuer-pcb/phoenix-contact/mpt-05-3-254-1725669/ | MPT0.5/3-2.54 | Y
 |  | J303 | CAN | conn:DB9_Male_MountingHoles | Connector_Dsub:DSUB-9_Male_Horizontal_P2.77x2.84mm_EdgePinOffset4.94mm_Housed_MountingHolesOffset7.48mm | docs/DS1037.pdf | N | CONN D-SUB RCPT 9POS R/A SOLDER | DS1037-09MNAKT74 | CONNFLY |  | TME | https://www.tme.eu/de/details/dhp8-09m/d-sub-steckverbinder/connfly/ds1037-09mnakt74/ | DHP8-09M | Y
 |  | J304 | CAN-GND | conn_generic:Conn_02x02_Odd_Even | Connector_PinHeader_2.54mm:PinHeader_2x02_P2.54mm_Vertical | docs/DS1021.pdf | N | CONN HEADER 4POS .100 STR TIN | DS1021-2*2SF1-1 | CONNFLY |  | TME | http://www.tme.eu/de/details/zl202-4g/stiftleisten-und-buchsen/connfly/ds1021-2_2sf1-1/ | ZL202-4G | Y
 |  | J401 | GPO | conn_generic:Conn_01x04 | TerminalBlock_Phoenix:TerminalBlock_Phoenix_MPT-0,5-4-2.54_1x04_P2.54mm_Horizontal | docs/1725672.pdf | N | CONN TERM BLOCK 2.54MM 4POS | 1725672 | Phoenix Contact |  | TME | http://www.tme.eu/de/details/mpt0.5_4-2.54/klemmleisten-fuer-pcb/phoenix-contact/mpt-05-4-254-1725672/ | MPT0.5/4-2.54 | Y
 |  | J501 | I²C | conn_generic:Conn_01x03 | Connector_PinHeader_2.54mm:PinHeader_1x03_P2.54mm_Vertical |  | N |  |  |  |  |  |  |  | N
 |  | J502 | SPI | conn_generic:Conn_02x03_Odd_Even | Connector_PinHeader_2.54mm:PinHeader_2x03_P2.54mm_Vertical |  | N |  |  |  |  |  |  |  | N
 |  | J601 | AC IN | conn_generic:Conn_01x03 | Connector_Phoenix_MSTB:PhoenixContact_MSTB_2,5_3-GF_1x03_P5.00mm_Horizontal_ThreadedFlange | docs/1757255.pdf | N | TERM BLOCK HDR 3POS 90DEG 5.08MM | 1757255 | Phoenix Contact |  | TME | https://www.tme.eu/de/details/mstba2.5_3g5.08/trennbare-klemmleisten/phoenix-contact/mstba-25-3-g-508-1757255/ | MSTBA2.5/3G5.08 | Y
 |  | J602 | PWR SWITCH | conn_generic:Conn_01x02 | AC-wire:ACWirePad_2x_1-5mmDrill |  | N |  |  |  |  |  |  |  | N
 |  | J607 | 5V PWR | conn_generic:Conn_01x02 | Connector_PinHeader_2.54mm:PinHeader_1x02_P2.54mm_Vertical |  | N |  |  |  |  |  |  |  | N
 |  | J609 | EXT SW | conn_generic:Conn_01x06 | Connector_Phoenix_misc:PhoenixContact_MKKDSN_1,5_3-GF-5,08_2x03_P5.08mm_Horizontal | docs/1726066.pdf | N | CONN TERM BLOCK 2.54MM 3POS | 1726066 | Phoenix Contact |  | TME | https://www.tme.eu/de/details/mkkdsn-3-5.08/klemmleisten-fuer-pcb/phoenix-contact/mkkdsn-15-3-508-1726066/ | MKKDSN-3-5.08 | Y
 |  | J610 | AC OUT | conn_generic:Conn_01x03 | Connector_Phoenix_misc:PhoenixContact_IC_2,5_3-G-5,08_03_P5.08mm_Horizontal | docs/1786417.pdf | N | TERM BLOCK HDR 3POS 90DEG 5.08MM | 1786417 | Phoenix Contact |  | TME | https://www.conrad.de/de/phoenix-contact-buchsengehaeuse-kabel-ic-polzahl-gesamt-3-rastermass-508-mm-1786417-50-st-569638.html | 569638 - 62 | Y
 |  | J611 | PE | conn_generic:Conn_01x01 | Wire_Pads:SolderWirePad_single_2-5mmDrill |  | N |  |  |  |  |  |  |  | N
 |  | J801 | GPIO CON3 | conn_generic:Conn_02x13_Odd_Even | Connector_PinSocket_2.54mm:PinSocket_2x13_P2.54mm_Vertical | docs/DS1023.pdf | N | CONN HEADER FMAL 26PS .1" DL TIN | DS1023-2*13S01 | CONNFLY |  | TME | http://www.tme.eu/de/details/zl262-26dg/stiftleisten-und-buchsen/connfly/ds1023-2_13s01/ | ZL262-26DG | EXT
 |  | J802 | GPIO J12 | conn_generic:Conn_02x04_Odd_Even | Connector_PinSocket_2.54mm:PinSocket_2x04_P2.54mm_Vertical | docs/DS1023.pdf | N | CONN HEADER FMALE 8PS .1" DL TIN | DS1023-2*4S01 | CONNFLY |  | TME | http://www.tme.eu/de/details/zl262-8dg/stiftleisten-und-buchsen/connfly/ds1023-2_13s01/ | ZL262-8DG | EXT
 |  | J803 | GPIO J13 | conn_generic:Conn_02x01 | Connector_PinSocket_2.54mm:PinSocket_2x01_P2.54mm_Vertical | docs/DS1023.pdf | EXT | CONN HEADER FEMALE 2POS .1" TIN | DS1023-1*2S01 | CONNFLY |  | TME | http://www.tme.eu/de/details/zl262-2sg/stiftleisten-und-buchsen/connfly/ds1023-1_2s01/ | ZL262-2SG | Y
 |  | J804 | XHP-2 | conn:Conn_01x02_Female |  |  | N | 10 cm cable to JST XHP-2 | XHP-2 | JST |  | akkuplus | https://akkuplus.de/JST-XHP-2-Stecker-mit-Ableiter-ca-10cm |  | EXT
 |  | J805 | AC IN2 | conn:Conn_01x03_Male |  | docs/TME-IEC-C-X.pdf | N | AC supply; socket; male; 10A; 250VAC; IEC 60320; C14 (E) | IEC-C-1 | Adam Tech |  | TME | https://www.tme.eu/de/details/iec-c-1/iec-60320-anschluesse/adam-tech/ | IEC-C-1 | EXT
 |  | J806 | AC out2 | conn:Conn_01x03_Female |  | docs/TME-IEC-D-X.pdf | N | AC supply; socket; female; 10A; 250VAC; IEC 60320 | IEC-D-1 | Adam Tech |  | TME | https://www.tme.eu/gb/details/iec-d-1/iec-60320-connectors/adam-tech/ | IEC-D-1 | EXT
 |  | J807 | AC IN1 | conn:Conn_01x03_Male |  | docs/1786187.pdf | N | Printed-circuit board connector - IC 2,5/ 3-ST-5,08 - 1786187 | 1786187 | Phoenix Contact |  | Conrad | https://www.conrad.de/de/phoenix-contact-stiftgehaeuse-kabel-ic-polzahl-gesamt-3-rastermass-508-mm-1786187-50-st-566649.html | 1786187 | EXT
 |  | J808 | AC out1 | conn:Conn_01x03_Female |  | docs/1757022.pdf | N | Plug component, Screw connection with tension sleeve | MSTB 2,5/ 3-ST-5,08 – 1757022 | Phoenix Contact |  | TME | https://www.tme.eu/de/details/mstb2.5_3-st-5.08/trennbare-klemmleisten/phoenix-contact/mstb-25-3-st-508-_-1757022/ | MSTB2.5/3-ST-5.08 | EXT
 |  | JP601 | Relais | jumper:Jumper_2_Bridged | Connector_PinHeader_2.54mm:PinHeader_1x02_P2.54mm_Vertical | docs/DS1021.pdf | N | CONN HEADER 2POS .100 STR TIN | DS1021-1*2SF1-1B | CONNFLY |  | TME | https://www.tme.eu/en/details/zl201-02g/pin-headers/connfly/ds1021-1_2sf1-1b/ | DS1021-1*2SF1-1B | Y
 |  | JP801 | CAB 4 GS | device:Jumper_NC_Small |  |  | N | CONN JUMPER SHORTING .100" | CAB 4 GS | Fischer Elektronik |  | TME | https://www.tme.eu/de/details/cab4gs/stiftleisten-und-buchsen/fischer-elektronik/cab-4-gs/ | CAB4GS | EXT
 |  | JP802 | CAB 4 GS | device:Jumper_NC_Small |  |  | N | CONN JUMPER SHORTING .100" | CAB 4 GS | Fischer Elektronik |  | TME | https://www.tme.eu/de/details/cab4gs/stiftleisten-und-buchsen/fischer-elektronik/cab-4-gs/ | CAB4GS | EXT
 |  | JP803 | CAB 4 GS | device:Jumper_NC_Small |  |  | N | CONN JUMPER SHORTING .100" | CAB 4 GS | Fischer Elektronik |  | TME | https://www.tme.eu/de/details/cab4gs/stiftleisten-und-buchsen/fischer-elektronik/cab-4-gs/ | CAB4GS | EXT
 |  | JP804 | CAB 4 GS | device:Jumper_NC_Small |  |  | N | CONN JUMPER SHORTING .100" | CAB 4 GS | Fischer Elektronik |  | TME | https://www.tme.eu/de/details/cab4gs/stiftleisten-und-buchsen/fischer-elektronik/cab-4-gs/ | CAB4GS | EXT
 |  | JP805 | CAB 4 GS | device:Jumper_NC_Small |  |  | N | CONN JUMPER SHORTING .100" | CAB 4 GS | Fischer Elektronik |  | TME | https://www.tme.eu/de/details/cab4gs/stiftleisten-und-buchsen/fischer-elektronik/cab-4-gs/ | CAB4GS | EXT
 |  | K601 | HE721C0500 | he700:HE7xxCxxxx | he700:HE700 | docs/Littelfuse_Reed_Relays_HE700.pdf | N | RELAY REED SPDT 250MA 5V | HE721C0500 | LITTELFUSE |  | TME | https://www.tme.eu/de/details/he721c0500/elektromagnetische-reed-relais/littelfuse/ | HE721C0500 | Y
 |  | K602 | ASR05-DA | asr:ASRxx-xx-PCB | ASR-PCB:ASRxx-xx-PCB | docs/Anly_Electronics-ASR-05DA-datasheet.pdf | N | RELAY SSR 32VDC 1PH 280V 5A | ASR-05DA | ANLY ELECTRONICS |  | TME | https://www.tme.eu/de/details/asr-05da/ssr-einphasen-relais/anly-electronics/ | ASR-05DA | Y
 |  | Q601 | IRLHS2242 | q_pmos_pqfn:Q_PMOS_PQFN | PQFN:PQFN-6-2EP_2x2mm_Pitch0.65mm | docs/irlhs2242pbf.pdf | N | MOSFET P-CH 20V 15A 2X2 PQFN | IRLHS2242TRPBF | Infineon Technologies | 6-PQFN (2x2) | Digikey | https://www.digikey.de/product-detail/de/infineon-technologies/IRLHS2242TRPBF/IRLHS2242TRPBFCT-ND/2639603 | IRLHS2242TRPBFCT-ND | Y
 |  | R301 | 100 | device:R | Resistor_SMD:R_0603_1608Metric | docs/PYu-RC_Group_51_RoHS_L_7.pdf | N | RES SMD 100 OHM 1% 1/10W 0603 | RC0603FR-07100RL | Yageo | 0603 | Digikey | https://www.digikey.de/product-detail/de/yageo/RC0603FR-07100RL/311-100HRCT-ND/729835 | 311-100HRCT-ND | Y
 |  | R302 | 60.4 | device:R | Resistor_SMD:R_1210_3225Metric | docs/AOA0000C298.pdf | N | RES SMD 60.4 OHM 1% 1/2W 1210 | ERJ-14NF60R4U | Panasonic Electronic Components | 1210 | Digikey | https://www.digikey.de/product-detail/de/panasonic-electronic-components/ERJ-14NF60R4U/P60.4AACT-ND/384851 | P60.4AACT-ND | Y
 |  | R303 | 60.4 | device:R | Resistor_SMD:R_1210_3225Metric | docs/AOA0000C298.pdf | N | RES SMD 60.4 OHM 1% 1/2W 1210 | ERJ-14NF60R4U | Panasonic Electronic Components | 1210 | Digikey | https://www.digikey.de/product-detail/de/panasonic-electronic-components/ERJ-14NF60R4U/P60.4AACT-ND/384851 | P60.4AACT-ND | Y
 |  | R401 | 200 | device:R | Resistor_SMD:R_0603_1608Metric | docs/SEI-RMCF_RMCP.pdf | N | RES SMD 200 OHM 1% 1/10W 0603 | RMCF0603FT200R | Stackpole Electronics Inc. | 0603 | Digikey | https://www.digikey.de/product-detail/de/stackpole-electronics-inc/RMCF0603FT200R/RMCF0603FT200RCT-ND/1942972 | RMCF0603FT200RCT-ND | Y
 |  | R402 | 100 | device:R | Resistor_SMD:R_0603_1608Metric | docs/PYu-RC_Group_51_RoHS_L_7.pdf | N | RES SMD 100 OHM 1% 1/10W 0603 | RC0603FR-07100RL | Yageo | 0603 | Digikey | https://www.digikey.de/product-detail/de/yageo/RC0603FR-07100RL/311-100HRCT-ND/729835 | 311-100HRCT-ND | Y
 |  | R501 | R | device:R | Resistor_SMD:R_0603_1608Metric |  |  | do not assemble |  |  | 0603 |  |  |  | N
 |  | R502 | R | device:R | Resistor_SMD:R_0603_1608Metric |  |  | do not assemble |  |  | 0603 |  |  |  | N
 |  | R601 | 0 | device:R | Resistor_THT:R_Axial_DIN0207_L6.3mm_D2.5mm_P7.62mm_Horizontal |  | N |  |  |  |  |  |  |  | N
 |  | R602 | 0 | device:R | Resistor_THT:R_Axial_DIN0207_L6.3mm_D2.5mm_P7.62mm_Horizontal |  | N |  |  |  |  |  |  |  | N
 |  | R603 | 1k | device:R | Resistor_SMD:R_0603_1608Metric | docs/SEI-RMCF_RMCP.pdf | N | RES 1K OHM 1% 1/10W 0603 | RMCF0603FT1K00 | Stackpole Electronics Inc. | 603 | Digikey | https://www.digikey.de/product-detail/de/stackpole-electronics-inc/RMCF0603FT1K00/RMCF0603FT1K00CT-ND/1942996 | RMCF0603FT1K00CT-ND | Y
 |  | SW801 | power SW | Switch:SW_SPST |  | docs/Rocker_8600_8650_series-DTE.pdf | N | ROCKER; SPST; Positions:2; OFF-ON; 10A/250VAC; 10A/28VDC; black | H8600VBBB076W | Bulgin |  | TME | https://www.tme.eu/de/details/ae-h8600vbacn/wippschalter/bulgin/h8600vbbb076w/ | AE-H8600VBACN | EXT
 |  | U201 | MAX3232 | interface_uart:MAX3232 | Package_SO:SOIC-16_3.9x9.9mm_P1.27mm | docs/max3232e.pdf | N | IC RS232 3V5.5V 15KVESD 16-SOIC | MAX3232ECDR | Texas Instruments | 16-SOIC | Digikey | https://www.digikey.de/product-detail/de/texas-instruments/MAX3232ECDR/296-19851-1-ND/1120592 | 296-19851-1-ND | Y
 |  | U301 | LTC2875-S8 | interface_CAN_LIN:LTC2875-S8 | Package_SO:SOIC-8_3.9x4.9mm_P1.27mm | docs/2875f.pdf | N | IC TXRX CAN 4MBPS 8SO | LTC2875IS8#PBF | Linear Technology | 8-SO | Digikey | https://www.digikey.de/products/de?keywords=LTC2875IS8%23PBF | LTC2875IS8#PBF-ND | Y
 |  | U401 | HCPL063 | isolator:HCPL-063A | Package_DIP:DIP-8_W7.62mm | docs/6N137.pdf | N | OPTOISO 2.5KV 2CH OPEN COLL 8DIP | HCPL2631 | ON SEMICONDUCTOR (FAIRCHILD) | 8DIP | TME | http://www.tme.eu/de/details/hcpl2631/optokoppler-digitalausgang/on-semiconductor-fairchild/ | HCPL2631 | Y
 |  | U501 | 24LC08 | memory_EEPROM:24LC08 | Package_SO:SOIC-8_3.9x4.9mm_P1.27mm | docs/21710K.pdf | N | IC EEPROM 8K I2C 400KHZ 8SOIC | 24LC08BT-I/SN | Microchip Technology | 8-SOIC | Digikey | https://www.digikey.de/product-detail/de/microchip-technology/24LC08BT-I-SN/24LC08BT-I-SNCT-ND/5011021 | 24LC08BT-I/SNCT-ND | Y
 |  | U502 | ATECC608A | memory_EEPROM:24LC08 | Package_SO:SOIC-8_3.9x4.9mm_P1.27mm | docs/40001977A.pdf | N | IC AUTHENTICATION CHIP 8SOIC | ATECC608A-SSHDA-T | Microchip Technology | 8-SOIC | Digikey | https://www.digikey.de/product-detail/de/microchip-technology/ATECC608A-SSHDA-T/ATECC608A-SSHDA-TCT-ND/7928238 | ATECC608A-SSHDA-TCT-ND | Y
 |  | U601 | IRM-20 | meanwell:IRM-20 | Meanwell:IRM-20 | docs/IRM-20-EN.pdf | N | AC/DC CONVERTER 5V 20W | IRM-20-5 | MEAN WELL |  | TME | https://www.tme.eu/en/details/irm-20-5/built-in-power-supplies/mean-well/ | IRM-20-5 | Y
Collated Components:
Item | Qty | Reference(s) | Value | LibPart | Footprint | Datasheet | Critical | Description | ManuPart# | Manufacture | PackageID | Source | SupplLink | SupplPart# | assemble
1 | 1 | BRD1 | Banana Pi R1 router board | conn_generic:Conn_01x01 |  | docs/BPI-R1USERMANUAL.pdf | N | Banana Pi Router, 2x 1 GHz, 1 GB, Wi-Fi, 4x 1 Gbit |  |  |  | Reichelt | https://www.reichelt.de/banana-pi-router-2x-1-ghz-1-gb-wi-fi-4x-1-gbit-banana-pi-r1-p150228.html | BANANA PI R1 | EXT
2 | 5 | C201, C202, C203, C204, C302 | 10µ | device:C | Capacitor_SMD:C_0603_1608Metric | docs/GRM188R6YA106MA73#.pdf | N | CAP CER 10UF 35V X5R 0603 | GRM188R6YA106MA73D | Murata Electronics North America | 0603 | Digikey | https://www.digikey.de/product-detail/de/murata-electronics-north-america/GRM188R6YA106MA73D/490-13248-1-ND/5877456 | 490-13248-1-ND | Y
3 | 1 | C301 | 4n7 | device:C | Capacitor_SMD:C_0603_1608Metric | docs/S_CL10B472KB8NNNC.pdf | N | CAP CER 4700PF 50V X7R 0603 | CL10B472KB8NNNC | Samsung Electro-Mechanics America, Inc. | 0603 | Digikey | https://www.digikey.de/product-detail/de/samsung-electro-mechanics-america-inc/CL10B472KB8NNNC/1276-1098-1-ND/3889184 | 1276-1098-1-ND | Y
4 | 2 | C303, C601 | 100n | device:C | Capacitor_SMD:C_0603_1608Metric | docs/C_CL10F104ZO8NNNC.pdf | N | CAP CER 0.1UF 16V Y5V 0603 | CL10F104ZO8NNNC | Samsung Electro-Mechanics America, Inc. | 0603 | Digikey | https://www.digikey.de/product-detail/de/samsung-electro-mechanics-america-inc/CL10F104ZO8NNNC/1276-1258-1-ND/3889344 | 1276-1258-1-ND | Y
5 | 1 | F601 | Fuse | device:Fuse | Fuse:Fuseholder_TR5_Littlefuse_No560_No460 | docs/typ_FMS__250V_.pdf | N | FUSE HOLDER RADIAL 250V 5A PCB | 0031.7601 | SCHURTER | TR5 | TME | https://www.tme.eu/de/details/0031.7601/sicherungsdosen-pcb/schurter/ | 0031.7601 | Y
6 | 1 | F801 | Fuse | device:Fuse | littelfuse_370:fuse_littelfuse_370 | docs/Littelfuse_Fuse_370-3.pdf | N | FUSE BOARD MOUNT 5A 250VAC RAD | 37015000430 | Littelfuse Inc. | TR5 | TME | https://www.tme.eu/de/details/37015000430/flinke-sicherungen-tr5/littelfuse/ | 37015000430 | EXT
7 | 1 | HS801 | Heatsink_Pad | Mechanical:Heatsink_Pad |  | docs/Kerafol_Datenblaetter_86_200_03-18.pdf | N | SOFTTHERM® Films | 86/200 | KERAFOL Keramische Folien GmbH |  | Conrad | https://www.conrad.de/de/waermeleitfolie-5-mm-3-wmk-l-x-b-50-mm-x-50-mm-kerafol-86300-189042.html | 189042 - 62 | EXT
8 | 1 | ISO1 | SYM_Flash_Small | Graphic:SYM_Flash_Small |  | docs/0900766b81582e6d.pdf | N | isolation film | 785-0827 | RS components |  | RS | https://de.rs-online.com/web/p/elektrisch-chemisch-isolierende-folien/7850827/ | 785-0827 | EXT
9 | 2 | J101, J802 | GPIO J12 | conn_generic:Conn_02x04_Odd_Even | Connector_PinSocket_2.54mm:PinSocket_2x04_P2.54mm_Vertical | docs/DS1023.pdf | N | CONN HEADER FMALE 8PS .1" DL TIN | DS1023-2*4S01 | CONNFLY |  | TME | http://www.tme.eu/de/details/zl262-8dg/stiftleisten-und-buchsen/connfly/ds1023-2_13s01/ | ZL262-8DG | Y
10 | 2 | J102, J803 | GPIO J13 | conn_generic:Conn_02x01 | Connector_PinSocket_2.54mm:PinSocket_2x01_P2.54mm_Vertical | docs/DS1023.pdf | N | CONN HEADER FEMALE 2POS .1" TIN | DS1023-1*2S01 | CONNFLY |  | TME | http://www.tme.eu/de/details/zl262-2sg/stiftleisten-und-buchsen/connfly/ds1023-1_2s01/ | ZL262-2SG | Y
11 | 2 | J103, J801 | GPIO CON3 | conn_generic:Conn_02x13_Odd_Even | Connector_PinSocket_2.54mm:PinSocket_2x13_P2.54mm_Vertical | docs/DS1023.pdf | N | CONN HEADER FMAL 26PS .1" DL TIN | DS1023-2*13S01 | CONNFLY |  | TME | http://www.tme.eu/de/details/zl262-26dg/stiftleisten-und-buchsen/connfly/ds1023-2_13s01/ | ZL262-26DG | Y
12 | 4 | J104, J105, J106, J107 | MOUNT | conn_generic:Conn_01x01 | MountingHole:MountingHole_2.7mm_M2.5_Pad |  | N |  |  |  |  |  |  |  | N
13 | 1 | J201 | console | conn:DB9_Female_MountingHoles | Connector_Dsub:DSUB-9_Female_Vertical_P2.77x2.84mm_MountingHoles | docs/DS1034.pdf | N | CONN D-SUB RCPT 9POS VERT SOLDER | DS1034-09FUNSISS | CONNFLY |  | TME | http://www.tme.eu/de/details/df09pp/d-sub-steckverbinder/connfly/ds1034-09funsiss/ | DF09PP | Y
14 | 1 | J202 | serial | conn:RJ45 | Connector_RJ:RJ45_Amphenol_54602-x08_Horizontal | docs/c-bmj-0102.pdf | N | CONN MOD JACK 8P8C R/A UNSHLD | 955012881 | Molex |  | TME | http://www.tme.eu/de/details/mx-95501-2881/rj-steckverbinder/molex/955012881/ | MX-95501-2881 | Y
15 | 4 | J203, J204, J205, J206 | GS3 | Jumper:SolderJumper_3_Bridged12 | Connectors:GS3 |  | N |  |  |  |  |  |  |  | N
16 | 1 | J301 | TERM | conn_generic:Conn_02x02_Odd_Even | Connector_PinHeader_2.54mm:PinHeader_2x02_P2.54mm_Vertical | docs/DS1021.pdf | N | CONN HEADER 4POS .100 STR TIN | DS1021-2*2SF1-1 | CONNFLY |  | TME | http://www.tme.eu/de/details/zl202-4g/stiftleisten-und-buchsen/connfly/ds1021-2_2sf1-1/ | ZL202-4G | Y
17 | 1 | J302 | CAN | conn_generic:Conn_01x03 | TerminalBlock_Phoenix:TerminalBlock_Phoenix_MPT-0,5-3-2.54_1x03_P2.54mm_Horizontal | docs/1725669.pdf | N | CONN TERM BLOCK 2.54MM 3POS | 1725669 | Phoenix Contact |  | TME | http://www.tme.eu/de/details/mpt0.5_3-2.54/klemmleisten-fuer-pcb/phoenix-contact/mpt-05-3-254-1725669/ | MPT0.5/3-2.54 | Y
18 | 1 | J303 | CAN | conn:DB9_Male_MountingHoles | Connector_Dsub:DSUB-9_Male_Horizontal_P2.77x2.84mm_EdgePinOffset4.94mm_Housed_MountingHolesOffset7.48mm | docs/DS1037.pdf | N | CONN D-SUB RCPT 9POS R/A SOLDER | DS1037-09MNAKT74 | CONNFLY |  | TME | https://www.tme.eu/de/details/dhp8-09m/d-sub-steckverbinder/connfly/ds1037-09mnakt74/ | DHP8-09M | Y
19 | 1 | J304 | CAN-GND | conn_generic:Conn_02x02_Odd_Even | Connector_PinHeader_2.54mm:PinHeader_2x02_P2.54mm_Vertical | docs/DS1021.pdf | N | CONN HEADER 4POS .100 STR TIN | DS1021-2*2SF1-1 | CONNFLY |  | TME | http://www.tme.eu/de/details/zl202-4g/stiftleisten-und-buchsen/connfly/ds1021-2_2sf1-1/ | ZL202-4G | Y
20 | 1 | J401 | GPO | conn_generic:Conn_01x04 | TerminalBlock_Phoenix:TerminalBlock_Phoenix_MPT-0,5-4-2.54_1x04_P2.54mm_Horizontal | docs/1725672.pdf | N | CONN TERM BLOCK 2.54MM 4POS | 1725672 | Phoenix Contact |  | TME | http://www.tme.eu/de/details/mpt0.5_4-2.54/klemmleisten-fuer-pcb/phoenix-contact/mpt-05-4-254-1725672/ | MPT0.5/4-2.54 | Y
21 | 1 | J501 | I²C | conn_generic:Conn_01x03 | Connector_PinHeader_2.54mm:PinHeader_1x03_P2.54mm_Vertical |  | N |  |  |  |  |  |  |  | N
22 | 1 | J502 | SPI | conn_generic:Conn_02x03_Odd_Even | Connector_PinHeader_2.54mm:PinHeader_2x03_P2.54mm_Vertical |  | N |  |  |  |  |  |  |  | N
23 | 1 | J601 | AC IN | conn_generic:Conn_01x03 | Connector_Phoenix_MSTB:PhoenixContact_MSTB_2,5_3-GF_1x03_P5.00mm_Horizontal_ThreadedFlange | docs/1757255.pdf | N | TERM BLOCK HDR 3POS 90DEG 5.08MM | 1757255 | Phoenix Contact |  | TME | https://www.tme.eu/de/details/mstba2.5_3g5.08/trennbare-klemmleisten/phoenix-contact/mstba-25-3-g-508-1757255/ | MSTBA2.5/3G5.08 | Y
24 | 1 | J602 | PWR SWITCH | conn_generic:Conn_01x02 | AC-wire:ACWirePad_2x_1-5mmDrill |  | N |  |  |  |  |  |  |  | N
25 | 1 | J607 | 5V PWR | conn_generic:Conn_01x02 | Connector_PinHeader_2.54mm:PinHeader_1x02_P2.54mm_Vertical |  | N |  |  |  |  |  |  |  | N
26 | 1 | J609 | EXT SW | conn_generic:Conn_01x06 | Connector_Phoenix_misc:PhoenixContact_MKKDSN_1,5_3-GF-5,08_2x03_P5.08mm_Horizontal | docs/1726066.pdf | N | CONN TERM BLOCK 2.54MM 3POS | 1726066 | Phoenix Contact |  | TME | https://www.tme.eu/de/details/mkkdsn-3-5.08/klemmleisten-fuer-pcb/phoenix-contact/mkkdsn-15-3-508-1726066/ | MKKDSN-3-5.08 | Y
27 | 1 | J610 | AC OUT | conn_generic:Conn_01x03 | Connector_Phoenix_misc:PhoenixContact_IC_2,5_3-G-5,08_03_P5.08mm_Horizontal | docs/1786417.pdf | N | TERM BLOCK HDR 3POS 90DEG 5.08MM | 1786417 | Phoenix Contact |  | TME | https://www.conrad.de/de/phoenix-contact-buchsengehaeuse-kabel-ic-polzahl-gesamt-3-rastermass-508-mm-1786417-50-st-569638.html | 569638 - 62 | Y
28 | 1 | J611 | PE | conn_generic:Conn_01x01 | Wire_Pads:SolderWirePad_single_2-5mmDrill |  | N |  |  |  |  |  |  |  | N
29 | 1 | J804 | XHP-2 | conn:Conn_01x02_Female |  |  | N | 10 cm cable to JST XHP-2 | XHP-2 | JST |  | akkuplus | https://akkuplus.de/JST-XHP-2-Stecker-mit-Ableiter-ca-10cm |  | EXT
30 | 1 | J805 | AC IN2 | conn:Conn_01x03_Male |  | docs/TME-IEC-C-X.pdf | N | AC supply; socket; male; 10A; 250VAC; IEC 60320; C14 (E) | IEC-C-1 | Adam Tech |  | TME | https://www.tme.eu/de/details/iec-c-1/iec-60320-anschluesse/adam-tech/ | IEC-C-1 | EXT
31 | 1 | J806 | AC out2 | conn:Conn_01x03_Female |  | docs/TME-IEC-D-X.pdf | N | AC supply; socket; female; 10A; 250VAC; IEC 60320 | IEC-D-1 | Adam Tech |  | TME | https://www.tme.eu/gb/details/iec-d-1/iec-60320-connectors/adam-tech/ | IEC-D-1 | EXT
32 | 1 | J807 | AC IN1 | conn:Conn_01x03_Male |  | docs/1786187.pdf | N | Printed-circuit board connector - IC 2,5/ 3-ST-5,08 - 1786187 | 1786187 | Phoenix Contact |  | Conrad | https://www.conrad.de/de/phoenix-contact-stiftgehaeuse-kabel-ic-polzahl-gesamt-3-rastermass-508-mm-1786187-50-st-566649.html | 1786187 | EXT
33 | 1 | J808 | AC out1 | conn:Conn_01x03_Female |  | docs/1757022.pdf | N | Plug component, Screw connection with tension sleeve | MSTB 2,5/ 3-ST-5,08 – 1757022 | Phoenix Contact |  | TME | https://www.tme.eu/de/details/mstb2.5_3-st-5.08/trennbare-klemmleisten/phoenix-contact/mstb-25-3-st-508-_-1757022/ | MSTB2.5/3-ST-5.08 | EXT
34 | 1 | JP601 | Relais | jumper:Jumper_2_Bridged | Connector_PinHeader_2.54mm:PinHeader_1x02_P2.54mm_Vertical | docs/DS1021.pdf | N | CONN HEADER 2POS .100 STR TIN | DS1021-1*2SF1-1B | CONNFLY |  | TME | https://www.tme.eu/en/details/zl201-02g/pin-headers/connfly/ds1021-1_2sf1-1b/ | DS1021-1*2SF1-1B | Y
35 | 5 | JP801, JP802, JP803, JP804, JP805 | CAB 4 GS | device:Jumper_NC_Small |  |  | N | CONN JUMPER SHORTING .100" | CAB 4 GS | Fischer Elektronik |  | TME | https://www.tme.eu/de/details/cab4gs/stiftleisten-und-buchsen/fischer-elektronik/cab-4-gs/ | CAB4GS | EXT
36 | 1 | K601 | HE721C0500 | he700:HE7xxCxxxx | he700:HE700 | docs/Littelfuse_Reed_Relays_HE700.pdf | N | RELAY REED SPDT 250MA 5V | HE721C0500 | LITTELFUSE |  | TME | https://www.tme.eu/de/details/he721c0500/elektromagnetische-reed-relais/littelfuse/ | HE721C0500 | Y
37 | 1 | K602 | ASR05-DA | asr:ASRxx-xx-PCB | ASR-PCB:ASRxx-xx-PCB | docs/Anly_Electronics-ASR-05DA-datasheet.pdf | N | RELAY SSR 32VDC 1PH 280V 5A | ASR-05DA | ANLY ELECTRONICS |  | TME | https://www.tme.eu/de/details/asr-05da/ssr-einphasen-relais/anly-electronics/ | ASR-05DA | Y
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

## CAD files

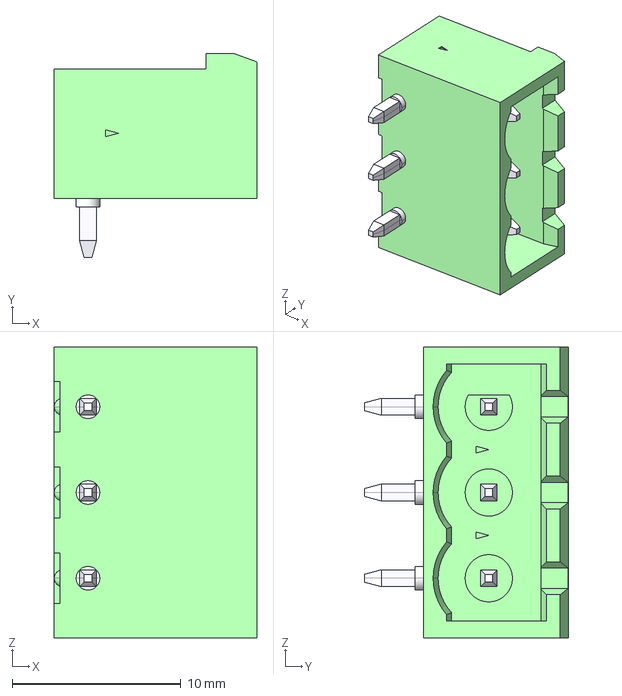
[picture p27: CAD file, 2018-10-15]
3D/shapes3D/pxc_1757255_08_MSTBA-2-5-3-G-5-08_3D.stp
12.0 x 12.1 x 17.2 mm

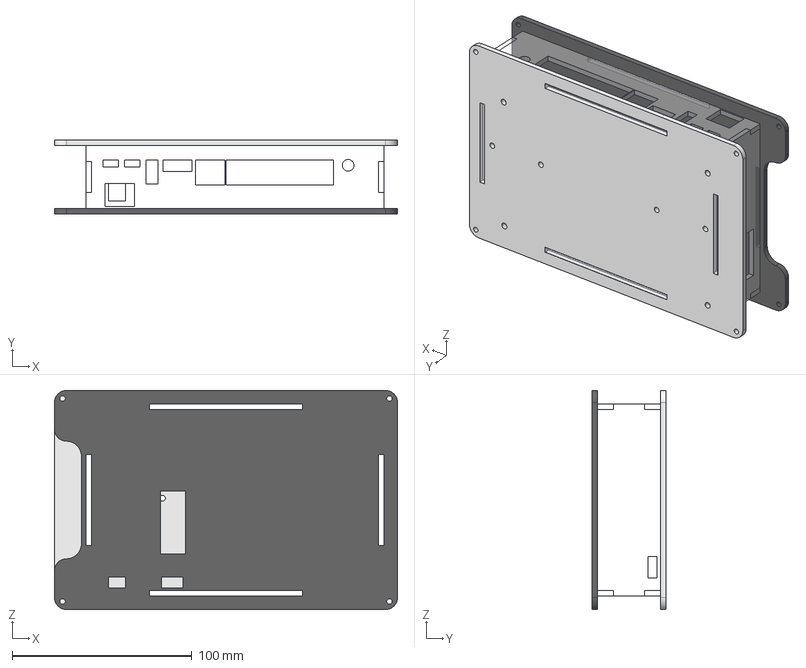
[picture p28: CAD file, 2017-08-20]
enclosure/enclosure.FCStd
191.0 x 41.0 x 122.0 mm
Back
Front
Bottom
Top
Left
Right

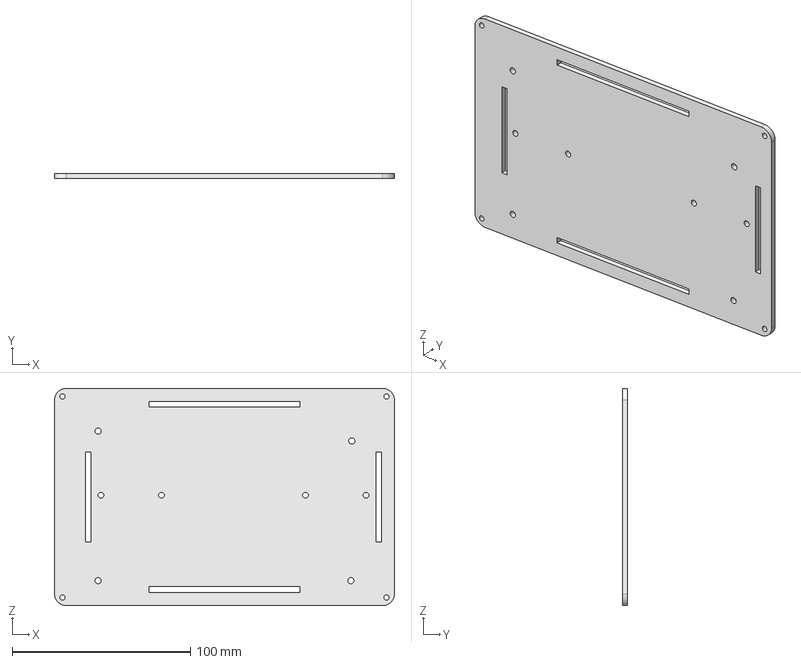
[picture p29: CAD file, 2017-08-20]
enclosure/export/bottom.stp
191.0 x 3.00 x 122.0 mm

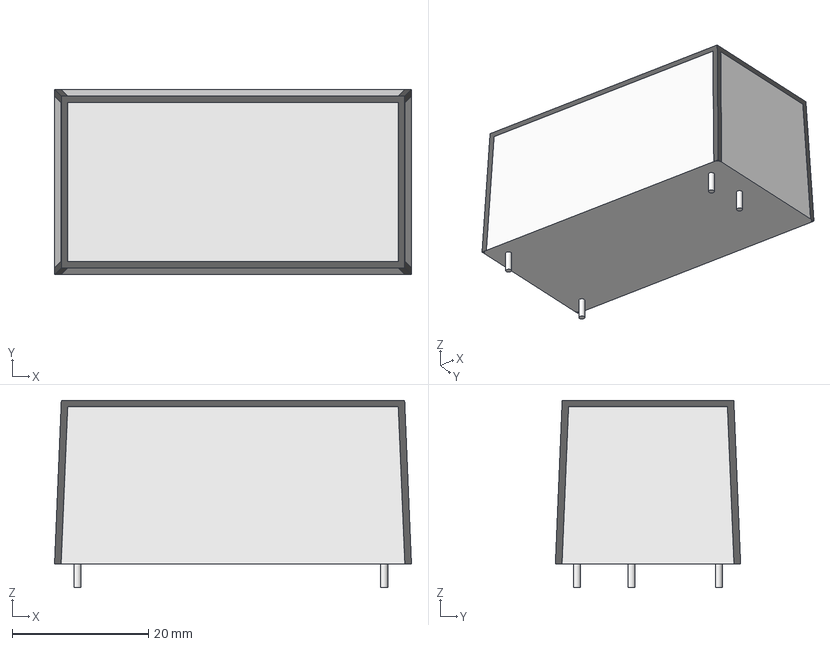
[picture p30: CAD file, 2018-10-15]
3D/shapes3D/IRM-20.FCStd
52.4 x 27.2 x 27.5 mm
Keil
IRM-20

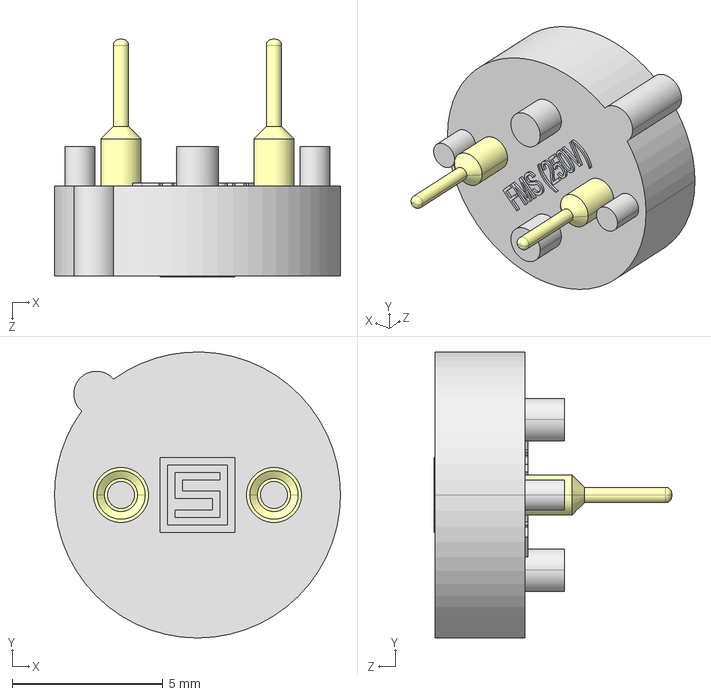
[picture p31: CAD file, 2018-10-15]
3D/shapes3D/FMS250V.STEP
9.50 x 9.50 x 7.89 mm

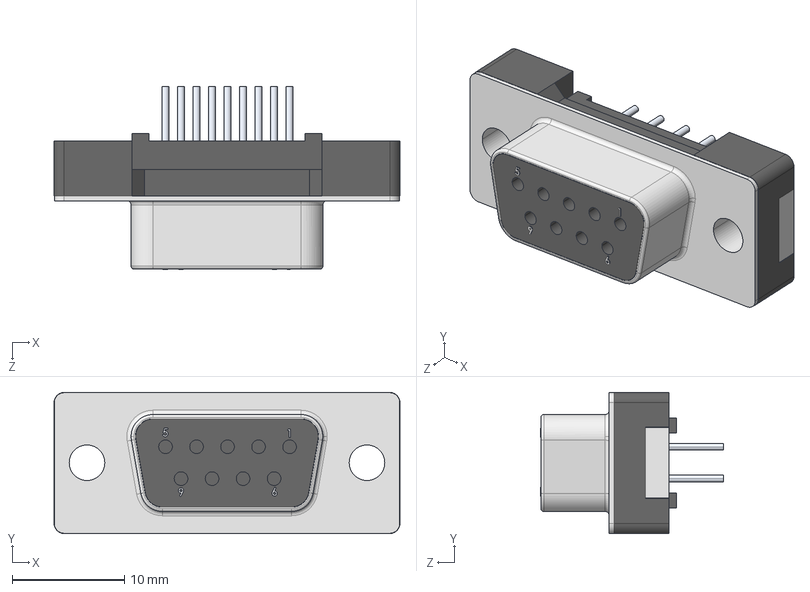
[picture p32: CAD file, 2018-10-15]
3D/shapes3D/191-009-213.STEP
30.9 x 12.6 x 16.4 mm

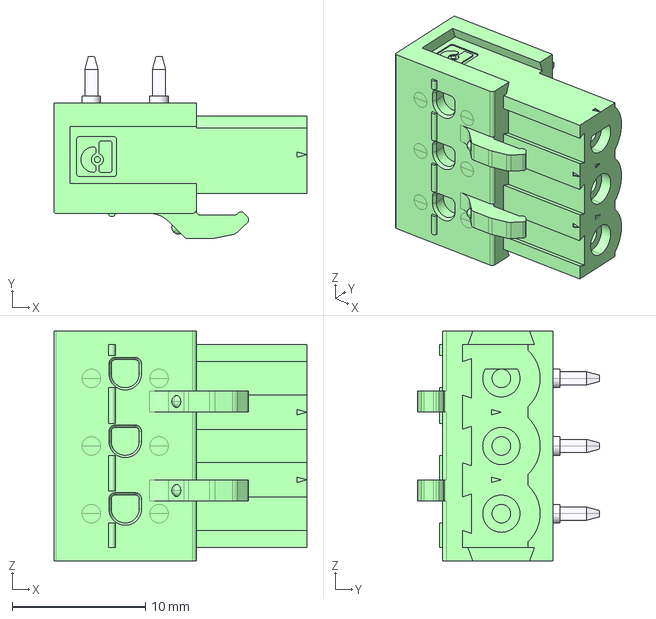
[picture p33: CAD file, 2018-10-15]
3D/shapes3D/pxc_1786417_03_IC-2-5-3-G-5-08_3D.stp
19.0 x 13.7 x 17.2 mm

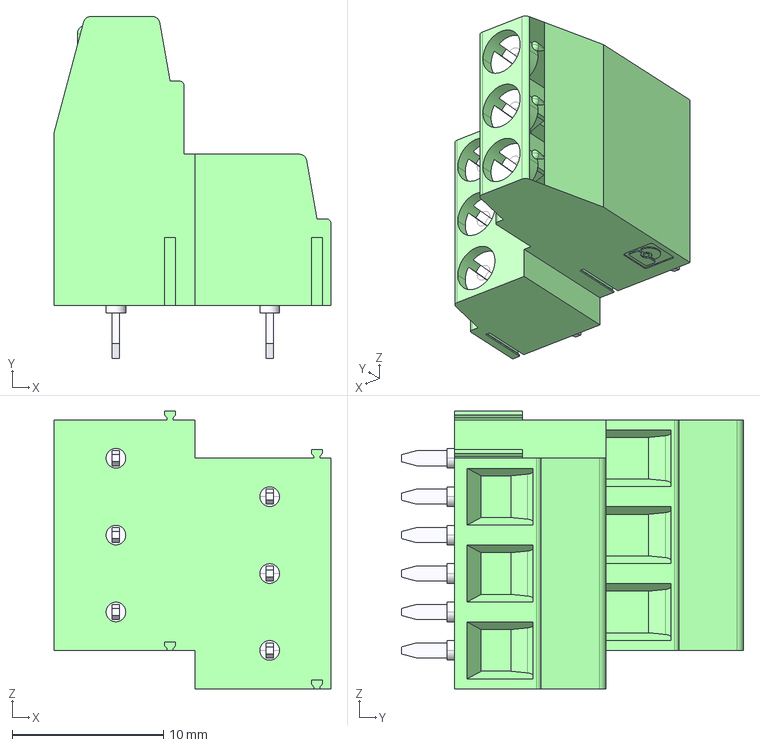
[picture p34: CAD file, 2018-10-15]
3D/shapes3D/pxc_1726066_06_MKKDSN-1-5-3-5-08_3D.stp
18.3 x 22.6 x 18.3 mm

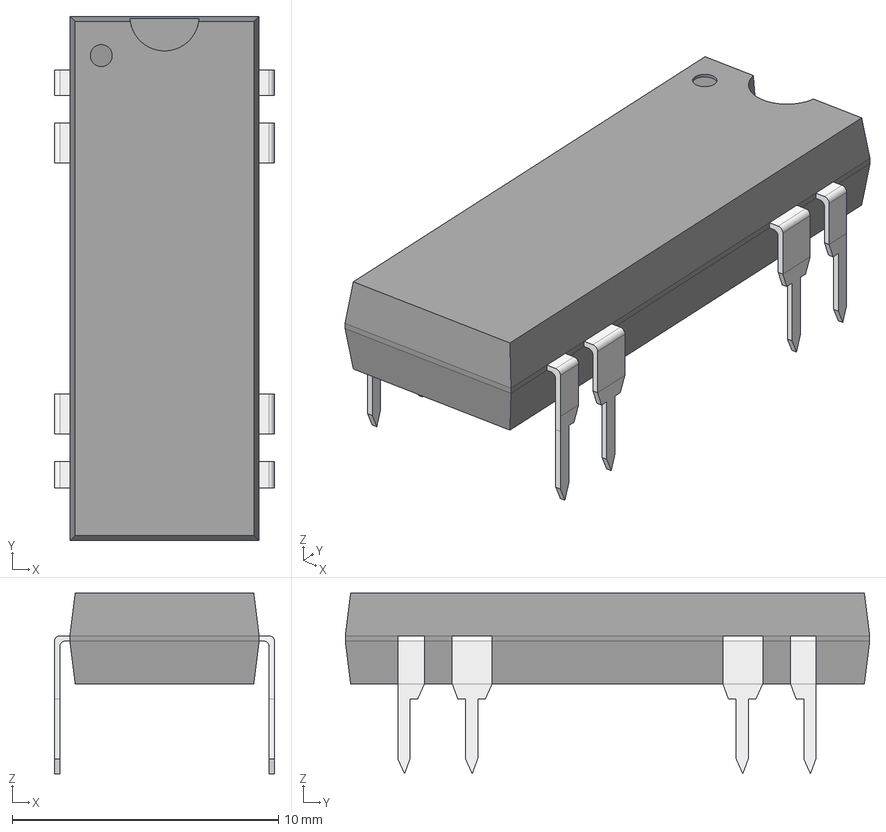
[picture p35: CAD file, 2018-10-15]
3D/shapes3D/he700.step
8.26 x 19.7 x 6.78 mm

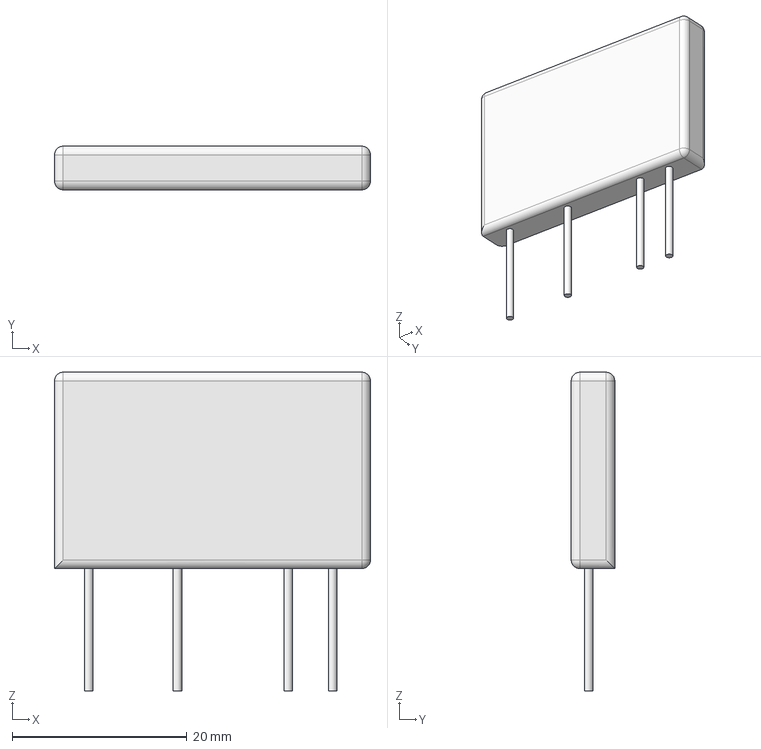
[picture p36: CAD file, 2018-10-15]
3D/shapes3D/ASR.FCStd
36.2 x 5.00 x 36.5 mm

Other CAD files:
3D/shapes3D/he700.fcstd

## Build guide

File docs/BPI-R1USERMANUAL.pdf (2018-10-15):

BPI-R1 User Manual

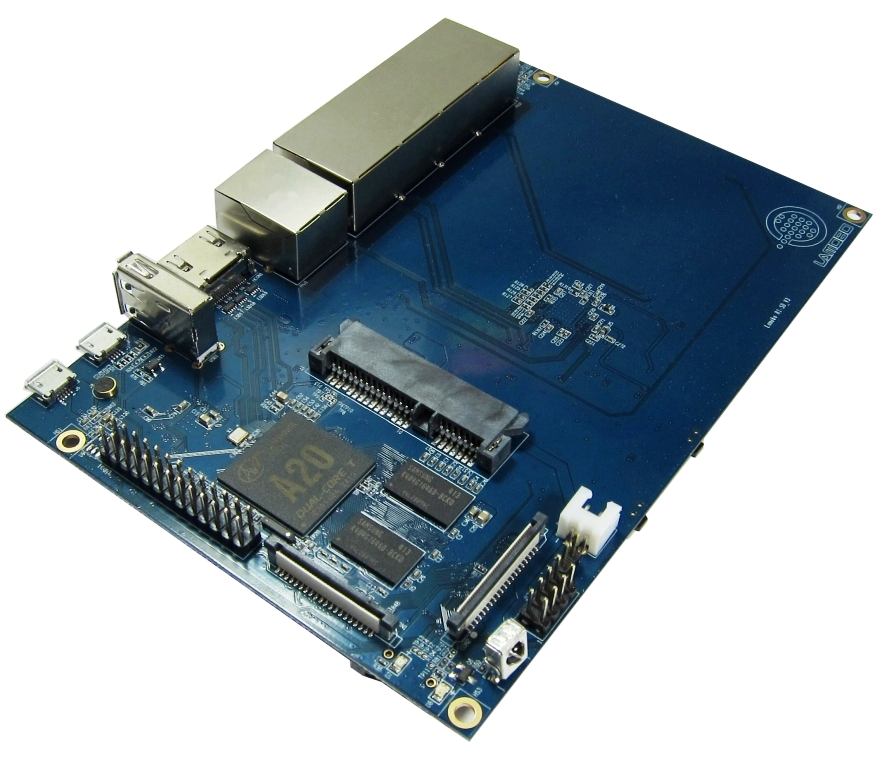
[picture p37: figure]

http://www.banana-pi.com | http://www.sinovoip.com.cn | 1

# SinoVoip Co.,Limited

# BPI-R1

# User Manual

BPI-R1 User Manual

The BPI- R1 is a 300Mbps Wireless N Router with both wired and wireless network

connections designed specifically for smart home networking use. With 2T2R MIMO

Technology and two detachable antennas, the R1 is the dual core Android 4.2 product which

more better than Linux product. It can run with Android 4.2.2 smoothly and with Gigabit

ethernet port, SATA Socket, it can easily run with the game and support 1080P high definition

video output.

Hardware specification

CPU | A20 ARM Cortex™-A7 Dual-Core
GPU | ARM Mali400MP2Complies with OpenGL ES 2.0/1.1
Memory (SDRAM) | 1GB DDR3 (shared with GPU)
Onboard Storage | Micro SD (Max. 64GB) card slot UP to 2T on 2.5 SATA disk
Onboard Network | 10/100/1000 Ethernet RJ45, WLAN @802.11b/g/n
Video Input | A CSI input connector allows for the connection of a designed camera module
Video Outputs | HDMI , LVDS/RGB
Audio Output Audio Input | 3.5 mm Jack and HDMI Microphone
Power Source | 5 volt via Micro USB(DC In Only)
USB 2.0 Ports | USB Host and Micro USB (OTG)
Buttons | Reset button: Next to Power button Power button: Next to Battery connector
GPIO(2X13) pin | GPIO,UART,I2C bus ,SPI bus with two chip selects, CAN bus,ADC,PWM,+3.3v,+5v,ground.
LED | Power Key & RJ45
Remote | IR
OS | Android 4.2, Linux

Interface definition

Product size | 148 mm × 100mm
Weight | 83g

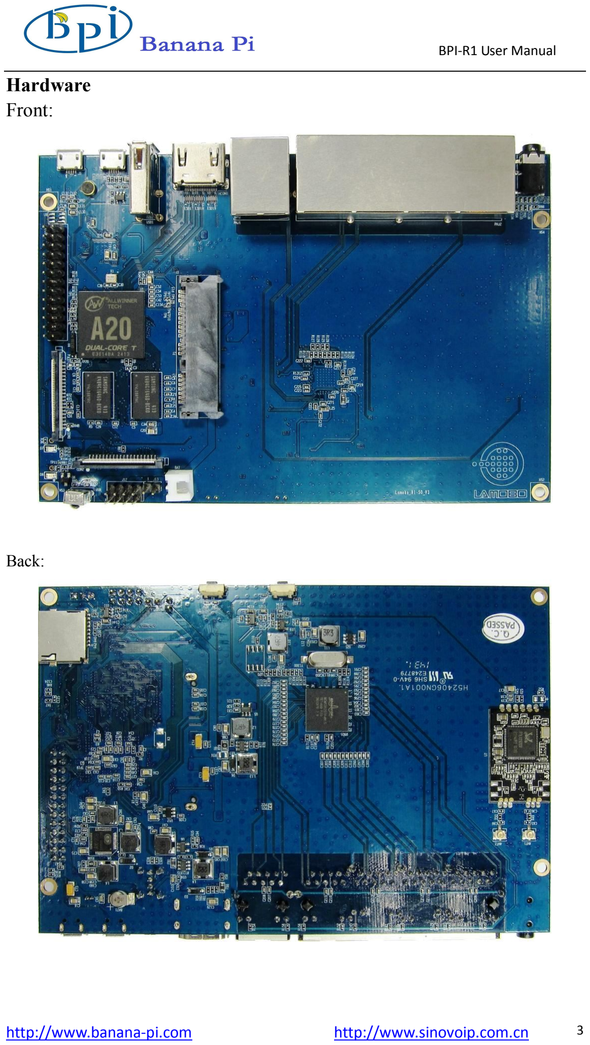
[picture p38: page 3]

BPI-R1 User Manual

Hardware
Front:

Back:

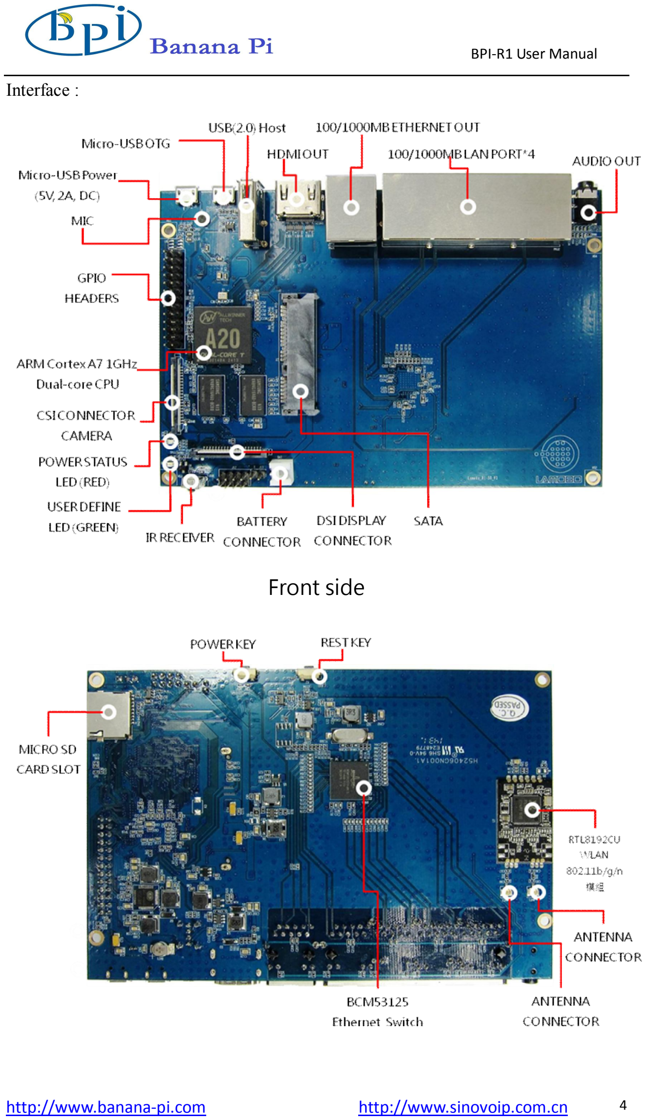
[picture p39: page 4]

BPI-R1 User Manual

Interface :

### Front side

### Back side

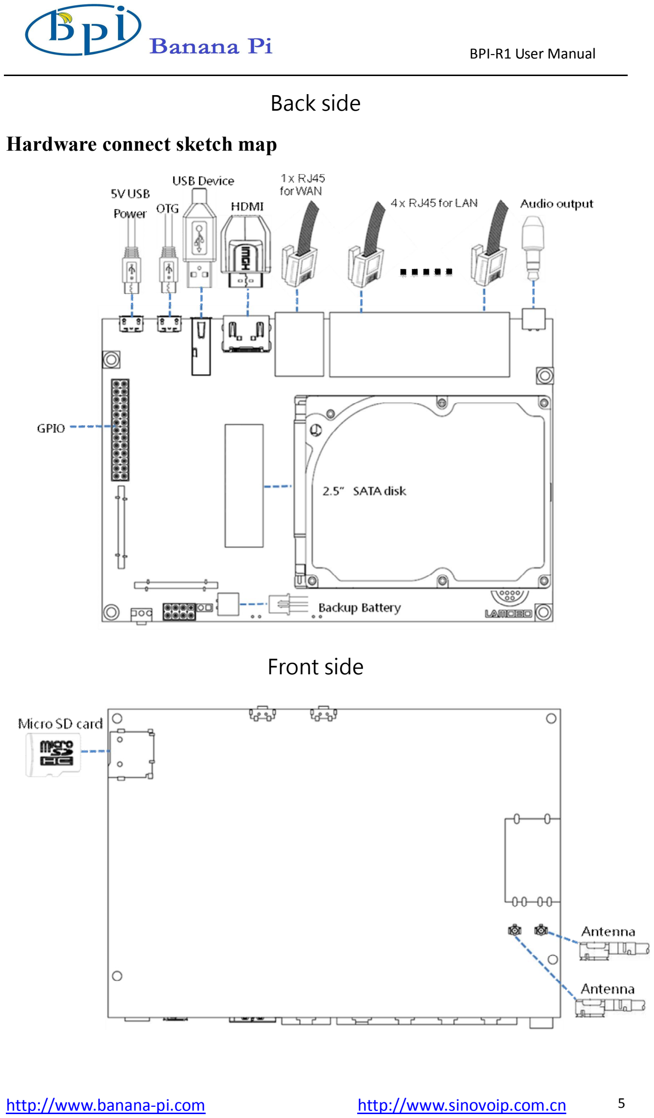
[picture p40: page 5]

BPI-R1 User Manual

Hardware connect sketch map

### Front side

BPI-R1 User Manual

### Back side

Use method

## Step 1: Get what you need

First time to enjoy your R1, you need at least the accessories in the table below.
No. | Item | Minimu recommended specification & notes

### 1 Micro SD card

- Minimum size 8Gb; class 10 (the class indicates how fast the card is).
- We recommend using branded SD cards as they are more reliable.

2

HDMI(Full sized)
to HDMI / DVI
lead
- HDMI to HDMI lead (for HD TVs and monitors with HDMI input).ORHDMI to DVI lead (for monitors with DVI input).

### 3 Mouse

- Any standard USB keyboard and mouse should work.
- Mice or Keyboards that take a lot of power from the USB ports, however, may need a powered USB hub. This may include some wireless devices.
4 | Ethernet cable | • | Networking is must of router.

5

Micro USB
power adapter
- A good quality, micro USB power supply that can provide at least 2A at 5V is essential.

6

Audio lead
(Optional)
- You can choose a 3.5mm jack audio lead to connect to audio port to get stereo audio.

7

Mobile Hard disk
(Optional)
- You can choose to connect a mobile hard disk to SATA port to store more files.
8 | Antenna
- You can choose two 2.4GHz WIFI antennas to connect to antenna ports to get advanced wireless performance.

BPI-R1 User Manual

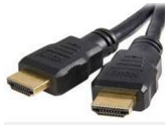
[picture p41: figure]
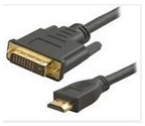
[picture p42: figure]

HDMI to HDMI lead | HDMI to DVI lead

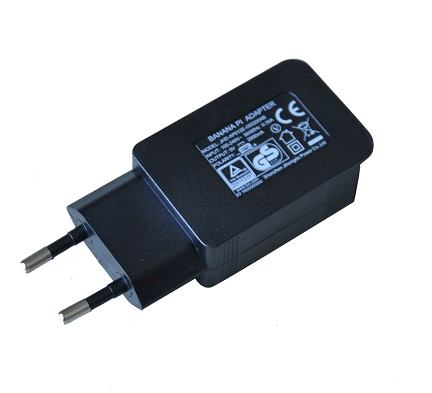
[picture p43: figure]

Micro SD card | Micro USB power adapter

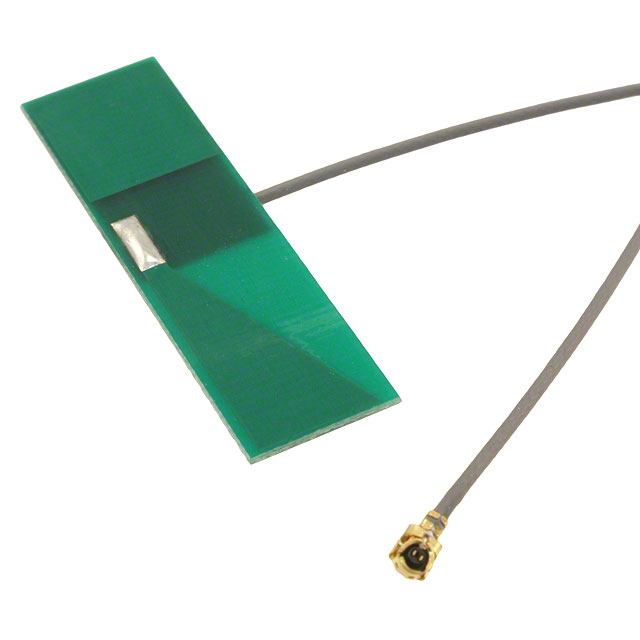
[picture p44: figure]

WiFi antenna

## Step 2:Download the relevant Image file:

Please visit our webmaster: http://www.bananapi.com to download image ,R1 all image can be downlad form this web.

## Step3: Prepare your Micro SD card for the R1

In order to enjoy your R1, you will need to install an Operating System (OS) onto an micro

SD card. Instructions below will teach you how to write an OS image to your SD card

under Windows.

BPI-R1 User Manual

1. Insert your micro SD card into your computer. The size of micro SD

should be larger than the OS image size, generally 8GB or greater.

2. Format the micro SD card.

Windows:

i. Download the a micro SD card format tool such as SD Formatter

from

https://www.sdcard.org/downloads/formatter_4/eula_windows/

ii. | Unzip the download file and run the setup.exe to install the tool
| on your machine.
iii. | In the "Options" menu, set "FORMAT TYPE" option to QUICK,
| "FORMAT SIZE ADJUSTMENT" option to "ON".

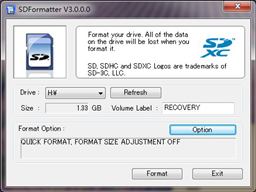
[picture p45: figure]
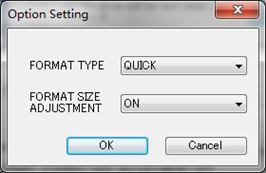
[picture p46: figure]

iv. | Check that the SD card you inserted matches the one selected
| by the Tool.
v. Click the “Format” button.
3. Download the OS image from Download district.

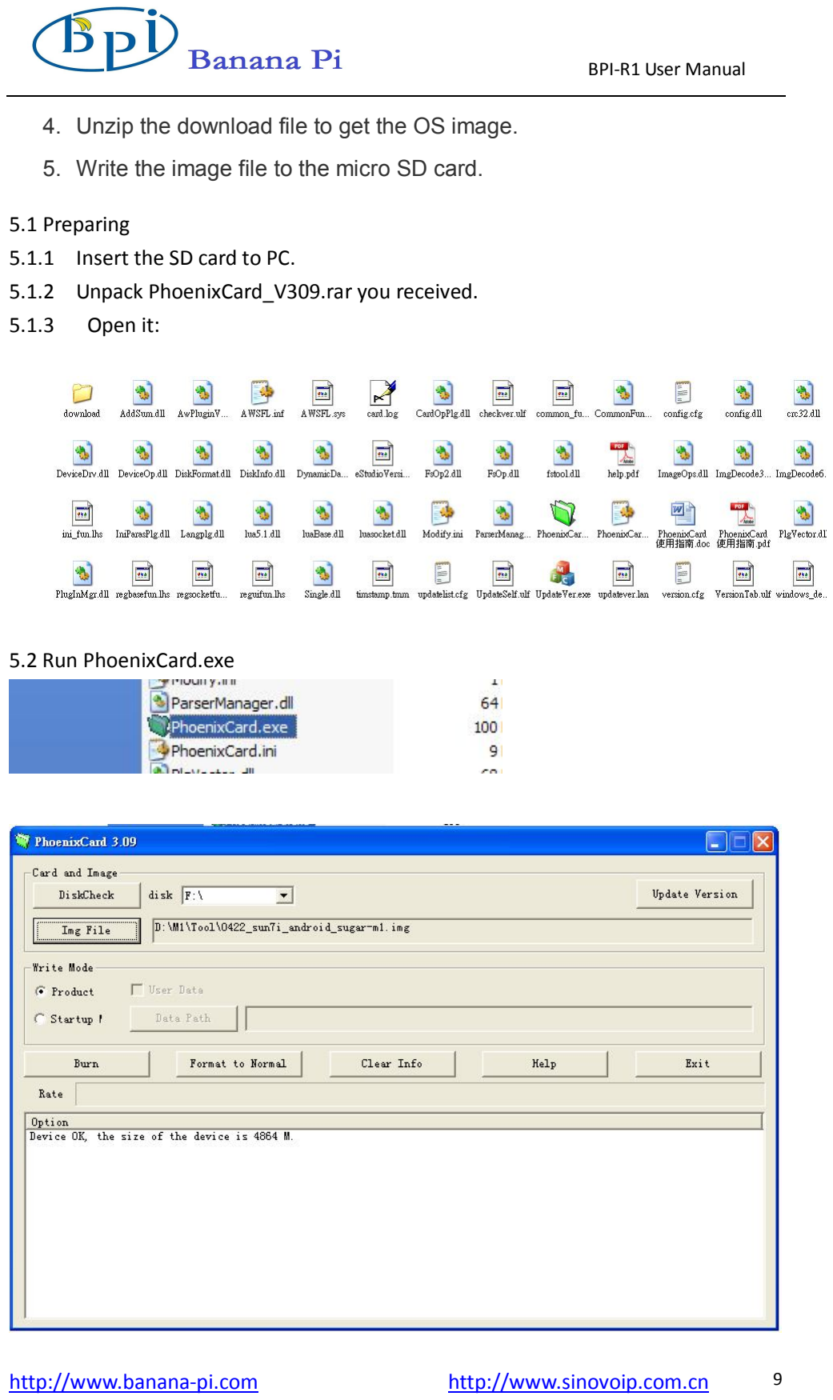
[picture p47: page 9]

BPI-R1 User Manual

4. Unzip the download file to get the OS image.
5. Write the image file to the micro SD card.

5.1 Preparing
5.1.1 Insert the SD card to PC.
5.1.2 Unpack PhoenixCard_V309.rar you received. 5.1.3 Open it:

5.2 Run PhoenixCard.exe

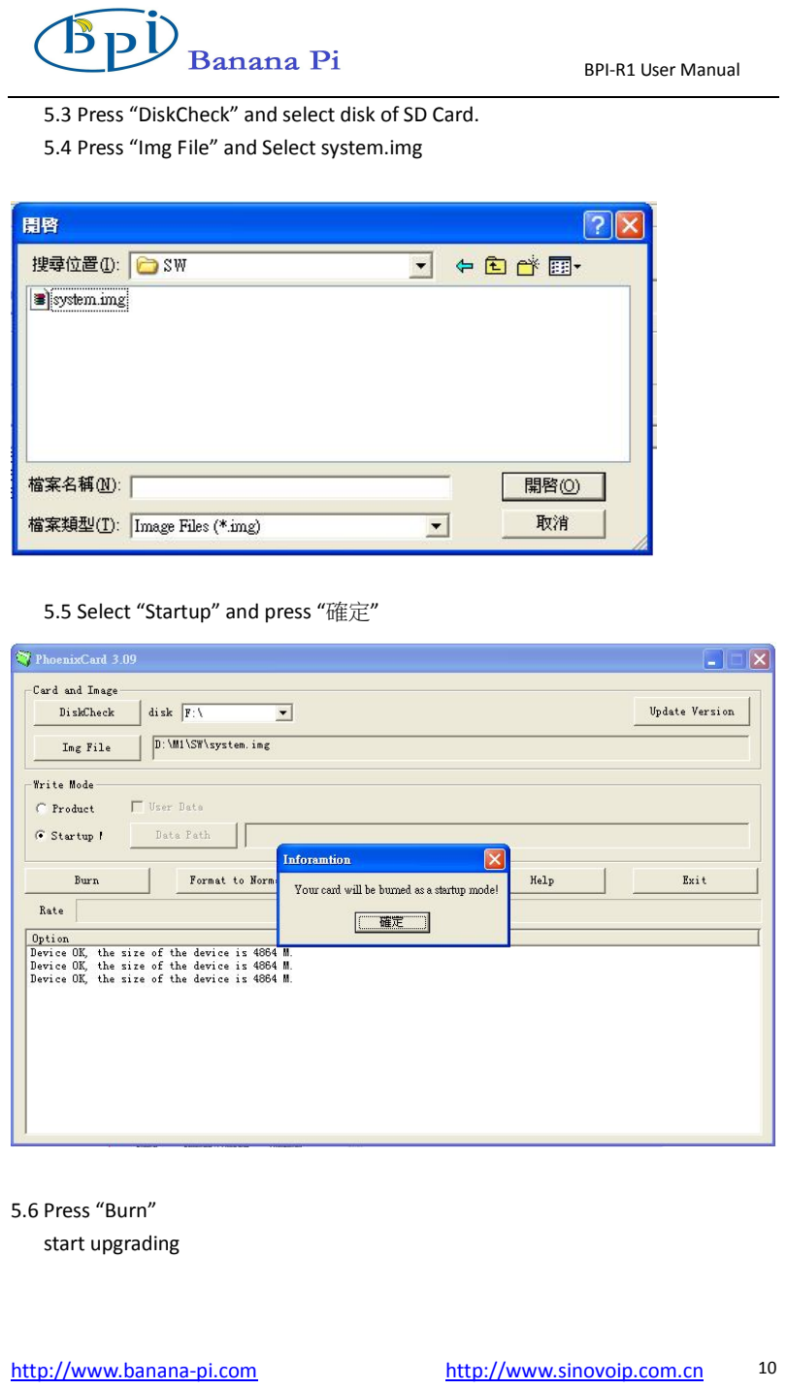
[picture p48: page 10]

BPI-R1 User Manual

5.3 Press “DiskCheck” and select disk of SD Card. 5.4 Press “Img File” and Select system.img

5.5 Select “Startup” and press “確定”

5.6 Press “Burn”
start upgrading

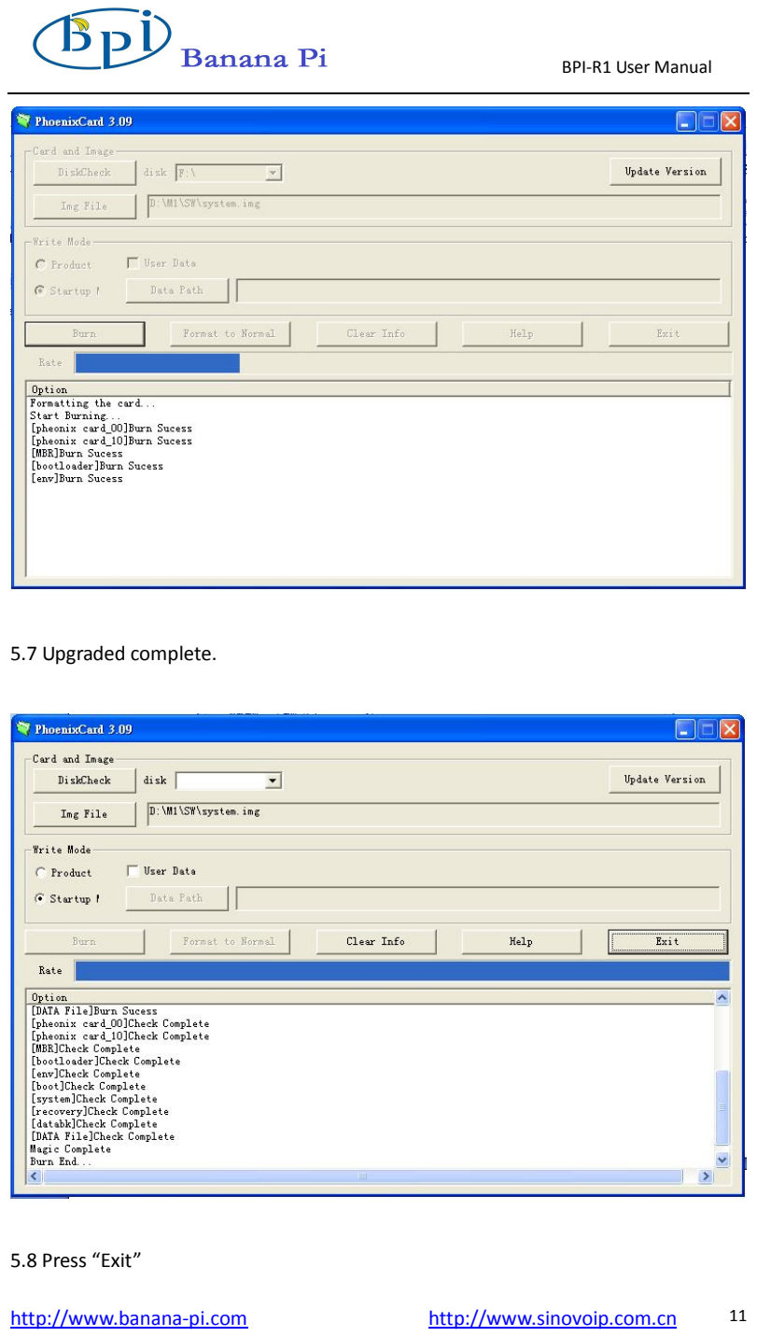
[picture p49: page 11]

BPI-R1 User Manual

5.7 Upgraded complete.

5.8 Press “Exit”

BPI-R1 User Manual

## Step4: Set up your R1

According to the set up diagram below, you can easily set up your R1.

1. Insert the written-image micro SD card that to the micro SD card slot on

the left side edge of the underside of the board.

2. The HDMI Type A (Full sized) port is between a USB port and a RJ45

port of the board. Just connect any HDMI cable from the board to your

TV or HDMI Monitor.

3. Plug a mouse into the USB slot.
4. Plug a Ethernet cable into the RJ45 slot.
5. Finally, at the very left of the bottom edge is the micro-usb power

connector. Plug in a regulated power supply that is rated at 5V ±2%

and at least 2A.

If all goes well, the R1 will boot in a few minutes. The screen will display

the OS GUI.

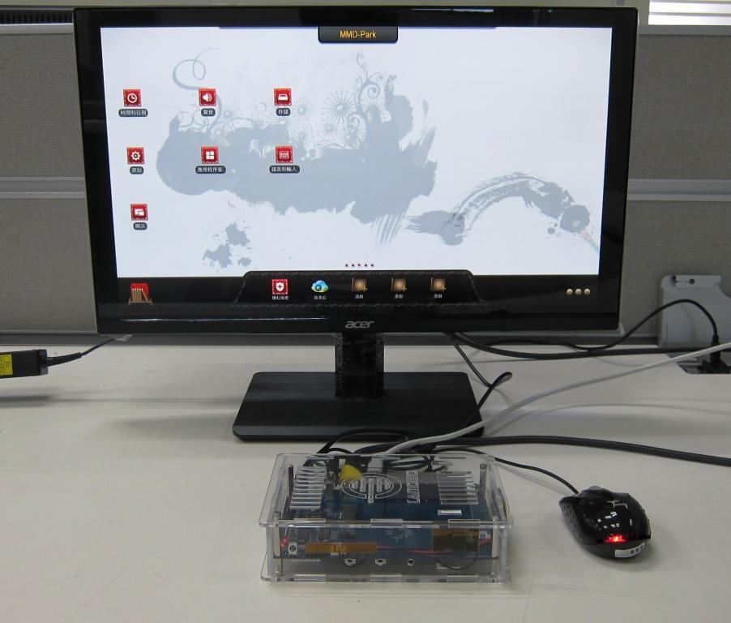
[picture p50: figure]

BPI-R1 User Manual

### Step5: Shut down your R1

This will shut down the PI safely, (just use the power key to turn off might damage the SD-cards file system). After that you can press the power key for 5 seconds to turn it off.

If all is well ,the splash screen show as below

Android system screen

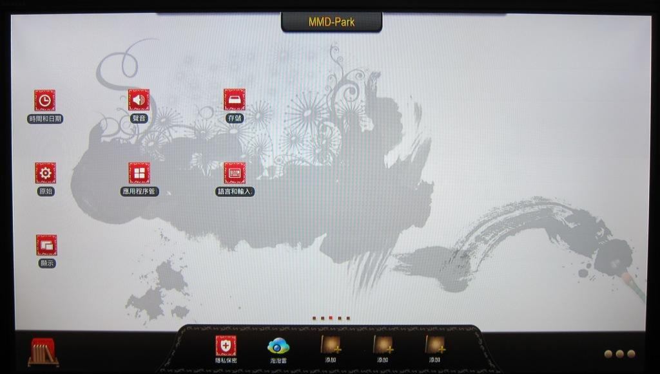
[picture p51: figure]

GPIO define
We can check R1 PIN definition in this thread, including CON1, CON2, CON3, J12 and J13.
J13 contains the default serial port UART0 (UART0-RX,UART0-TX). UATR0 is configured to be used for console input/output. Whilst this is useful if you want to login using the serial port. So it is the most common used PIN.
J12 also contains serial port.
CON3 contains CAN bus, SPI bus, PWM, serial port and etc. It can be configured to be used for kinds of peripherals.
CON1 is a CSI camera connector.
CON2 is a DSI display connector.
Pictures and tables below show the specific layout and definition of PIN.

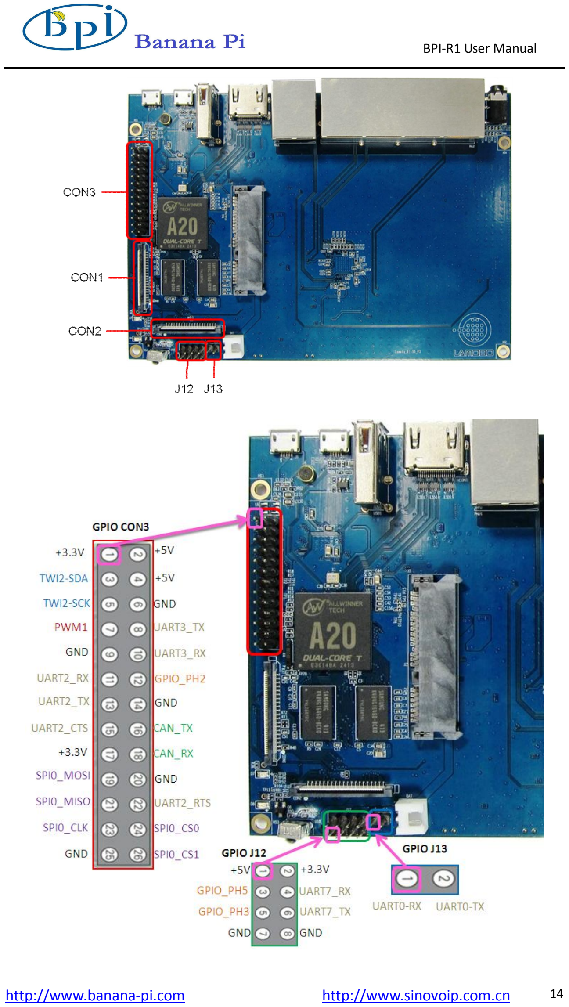
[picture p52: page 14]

BPI-R1 User Manual

BPI-R1 User Manual

# R1 PIN define

PIN | PIN define | GPIO
CON1-P01 | LINEINL
CON1-P02 | LINEINR
CON1-P37 | HPL
CON1-P36 | HPR
CON1-P07 | FMINL
CON1-P09 | FMINR
CON1-P04 | ADC_X1
CON1-P06 | ADC_X2
CON1-P08 | ADC_Y1
CON1-P10 | ADC_Y2
CON1-P13 | LRADC0
CON1-P15 | LRADC1
CON1-P33 | RESET#
CON1-P17 | CSI0-D0 | PE4
CON1-P19 | CSI0-D1 | PE5
CON1-P21 | CSI0-D2 | PE6
CON1-P23 | CSI0-D3 | PE7
CON1-P25 | CSI0-D4 | PE8
CON1-P27 | CSI0-D5 | PE9
CON1-P29 | CSI0-D6 | PE10
CON1-P31 | CSI0-D7 | PE11
CON1-P20 | CSI0-PCLK | PE0
CON1-P24 | CSI0-MCLK | PE1
CON1-P28 | CSI0-VSYNC | PE3
CON1-P30 | CSI0-HSYNC | PE2
CON1-P18 | CSI0-STBY-EN | PH19
CON1-P26 | CSI0-RESET# | PH14
CON1-P32 | CSI1-STBY-EN | PH18
CON1-P34 | CSI1-RESET# | PH13
CON1-P14 | TWI1-SDA | PB19
CON1-P16 | TWI1-SCK | PB18
CON1-P12 | CSI0-FLASH | PH17

BPI-R1 User Manual

CON1-P22 | CSI0-PWR-EN | PH16
CON1-P35 | CSI-IO0 | PH11
CON1-P38 | IPSOUT
CON1-P40 | IPSOUT
CON1-P05 | GND
CON1-P11 | GND
CON1-P39 | GND
CON1-P03 | VCC-CSI
CON2-P09 | LCD0-D00 | PD0
CON2-P11 | LCD0-D01 | PD1
CON2-P13 | LCD0-D02 | PD2
CON2-P15 | LCD0-D03 | PD3
CON2-P17 | LCD0-D04 | PD4
CON2-P19 | LCD0-D05 | PD5
CON2-P21 | LCD0-D06 | PD6
CON2-P23 | LCD0-D07 | PD7
CON2-P25 | LCD0-D08 | PD8
CON2-P27 | LCD0-D09 | PD9
CON2-P29 | LCD0-D10 | PD10
CON2-P31 | LCD0-D11 | PD11
CON2-P33 | LCD0-D12 | PD12
CON2-P35 | LCD0-D13 | PD13
CON2-P37 | LCD0-D14 | PD14
CON2-P39 | LCD0-D15 | PD15
CON2-P40 | LCD0-D16 | PD16
CON2-P38 | LCD0-D17 | PD17
CON2-P36 | LCD0-D18 | PD18
CON2-P34 | LCD0-D19 | PD19
CON2-P32 | LCD0-D20 | PD20
CON2-P30 | LCD0-D21 | PD21
CON2-P28 | LCD0-D22 | PD22
CON2-P26 | LCD0-D23 | PD23
CON2-P22 | LCD0-CLK | PD24
CON2-P20 | LCD0-CS | PH6
CON2-P18 | LCD0-HSYNC | PD26

BPI-R1 User Manual

CON2-P16 | LCD0-VSYNC | PD27
CON2-P14 | LCD0-DE | PD25
CON2-P12 | LCD0-IO2 | PH9
CON2-P10 | PWM0 | PB2
CON2-P08 | LCD0-IO1 | PH8
CON2-P06 | LCD0-IO0 | PH7
CON2-P04 | TWI3-SCK | PI0
CON2-P02 | TWI3-SDA | PI1
CON2-P01 | IPSOUT
CON2-P03 | IPSOUT
CON2-P05 | GND
CON2-P24 | GND
CON2-P07 | VCC-3V3
CON3-P18 | CAN_RX | PH21
CON3-P16 | CAN_TX | PH20
CON3-P23 | SPI0_CLK | PI11
CON3-P21 | SPI0_MISO | PI13
CON3-P19 | SPI0_MOSI | PI12
CON3-P24 | SPI0_CS0 | PI10
CON3-P26 | SPI0_CS1 | PI14
CON3-P05 | TWI2-SCK | PB20
CON3-P03 | TWI2-SDA | PB21
CON3-P15 | UART2_CTS | PI17
CON3-P22 | UART2_RTS | PI16
CON3-P11 | UART2_RX | PI19
CON3-P13 | UART2_TX | PI18
CON3-P10 | UART3_RX | PH1
CON3-P08 | UART3_TX | PH0
CON3-P12 | PH2 | PH2
CON3-P07 | PWM1 | PI3
CON3-P01 | VCC-3V3
CON3-P17 | VCC-3V3
CON3-P02 | VCC-5V
CON3-P04 | VCC-5V
CON3-P09 | GND

BPI-R1 User Manual

CON3-P25 | GND
CON3-P06 | GND
CON3-P14 | GND
CON3-P20 | GND
J12-P03 | PH5 | PH5
J12-P05 | PH3 | PH3
J12-P04 | UART7_RX | PI21
J12-P06 | UART7_TX | PI20
J12-P01 | VCC-5V
J12-P02 | VCC-3V3
J12-P07 | GND
J12-P08 | GND
J13-P01 | UART0-RX | PB23
J13-P02 | UART0-TX | PB22

R1 UART define

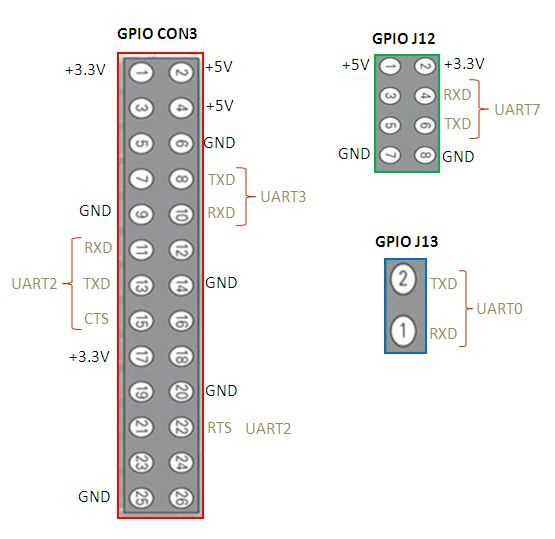
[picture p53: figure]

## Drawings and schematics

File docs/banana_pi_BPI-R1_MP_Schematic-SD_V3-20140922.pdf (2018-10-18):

# BLOCK

## SDIO2.0

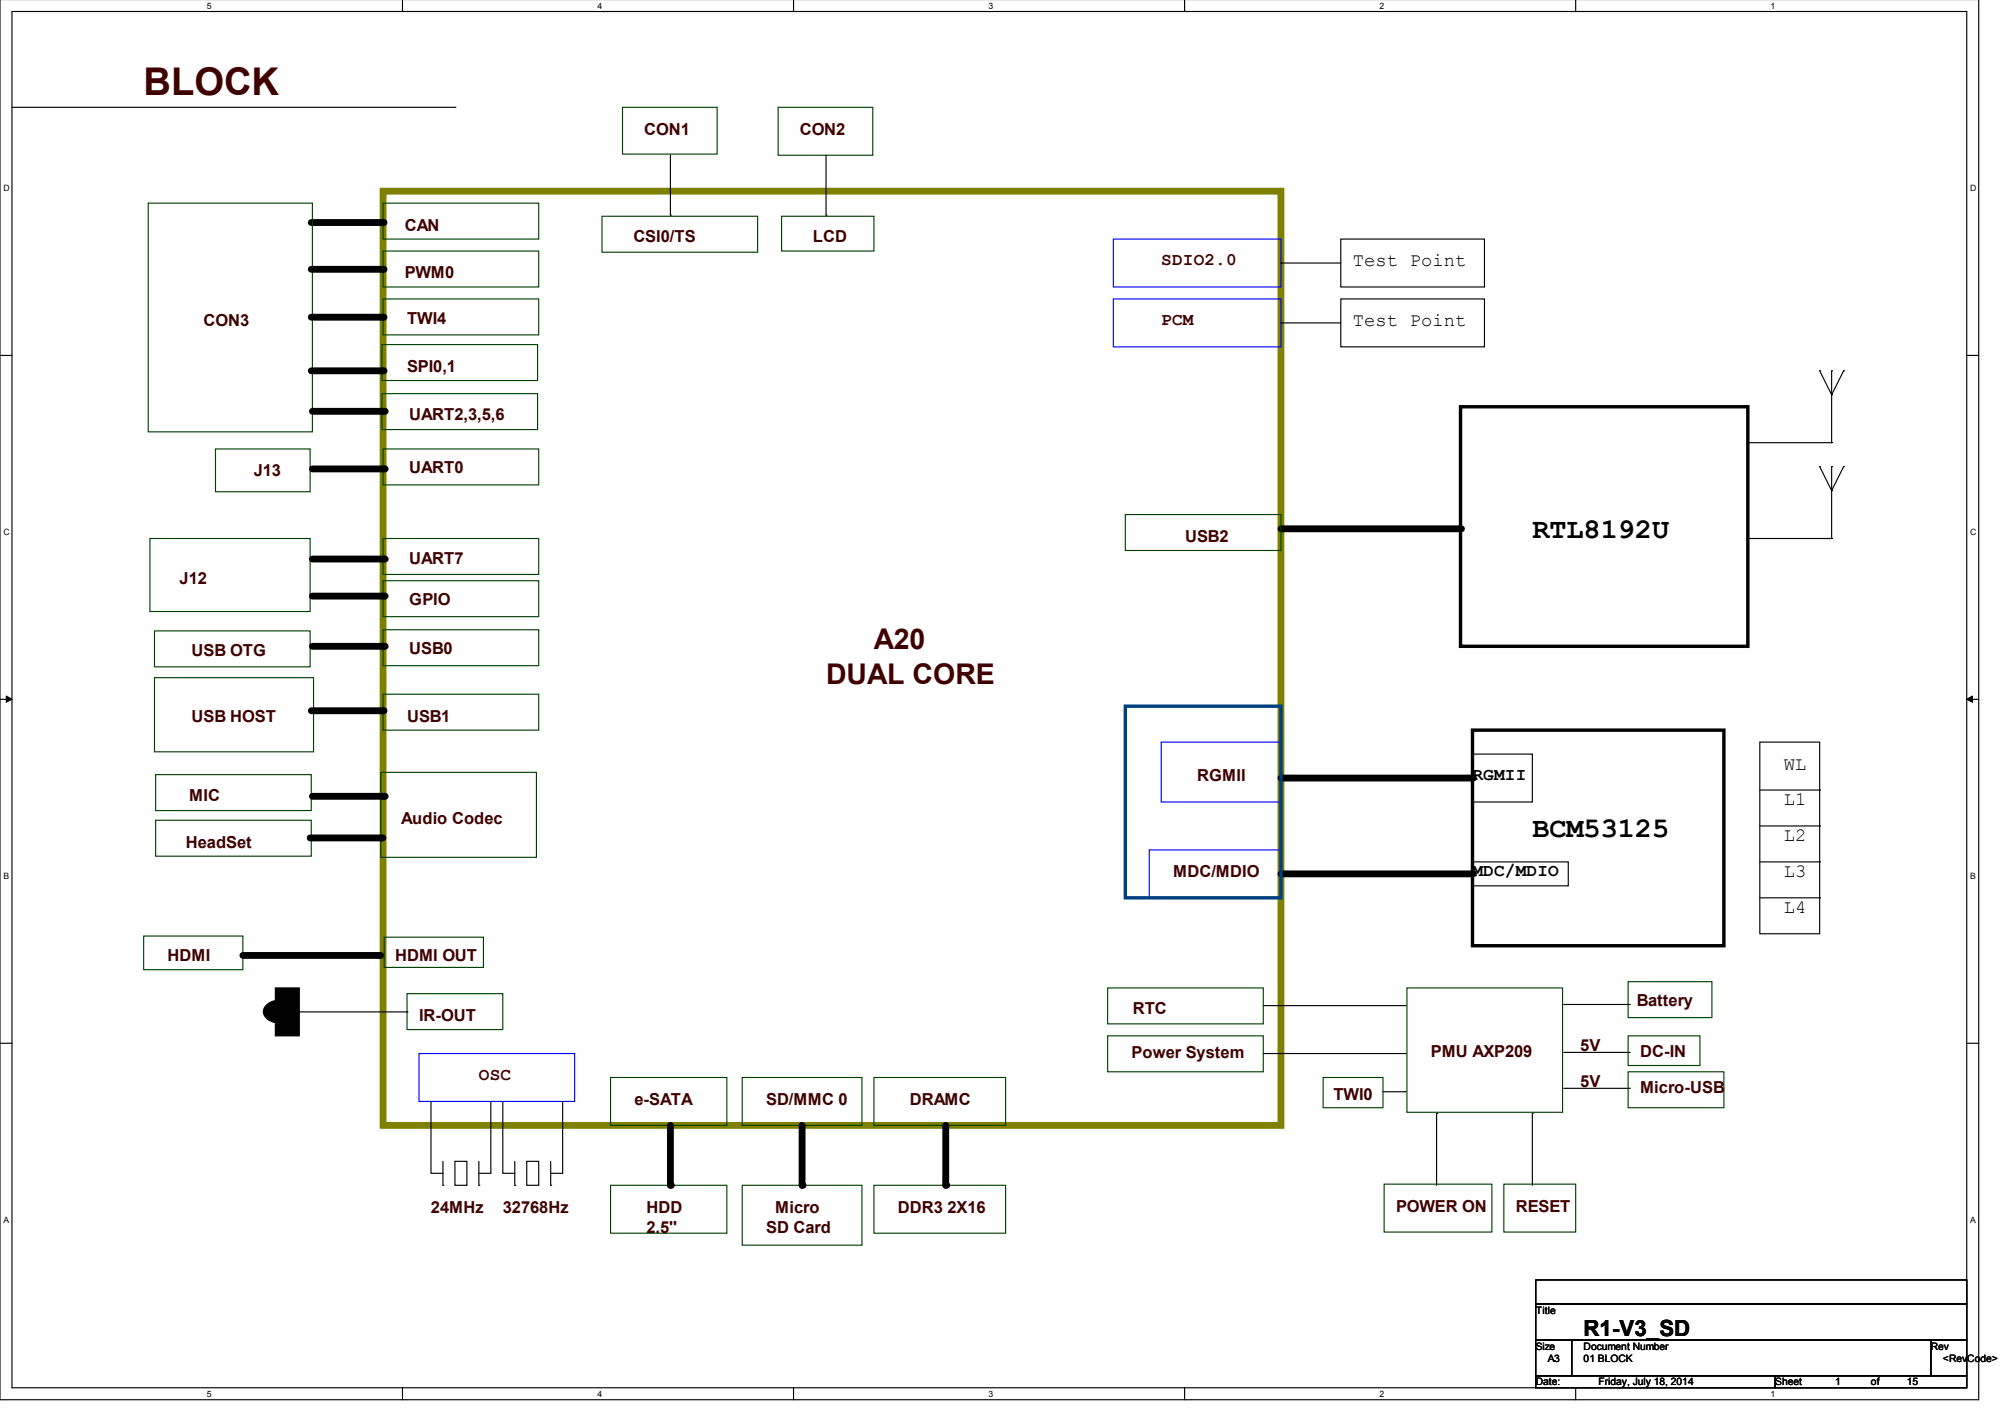
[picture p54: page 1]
RGMII; A20 DUAL CORE; MDC/MDIO; RTL8192U; BCM53125; 24MHz; OSC; Micro; DDR3 2X16; SD Card; HDD 2.5''; e-SATA; SD/MMC 0; DRAMC; TWI0; POWER ON; RESET; 5V Power System; PMU AXP209; HDMI; HDMI OUT; USB2; Audio Codec; MIC; USB0; HeadSet; USB1; CAN; PWM0; UART0; UART7; GPIO; USB HOST; USB OTG; CON3; UART2,3,5,6; TWI4; SPI0,1; CSI0/TS; LCD; CON1; CON2; Micro-USB; Test Point; PCM; Title; Size; Document Number; Rev; Date:; Sheet; 01 BLOCK; <RevCode>; Friday, July 18, 2014

Battery RTC IR-OUT

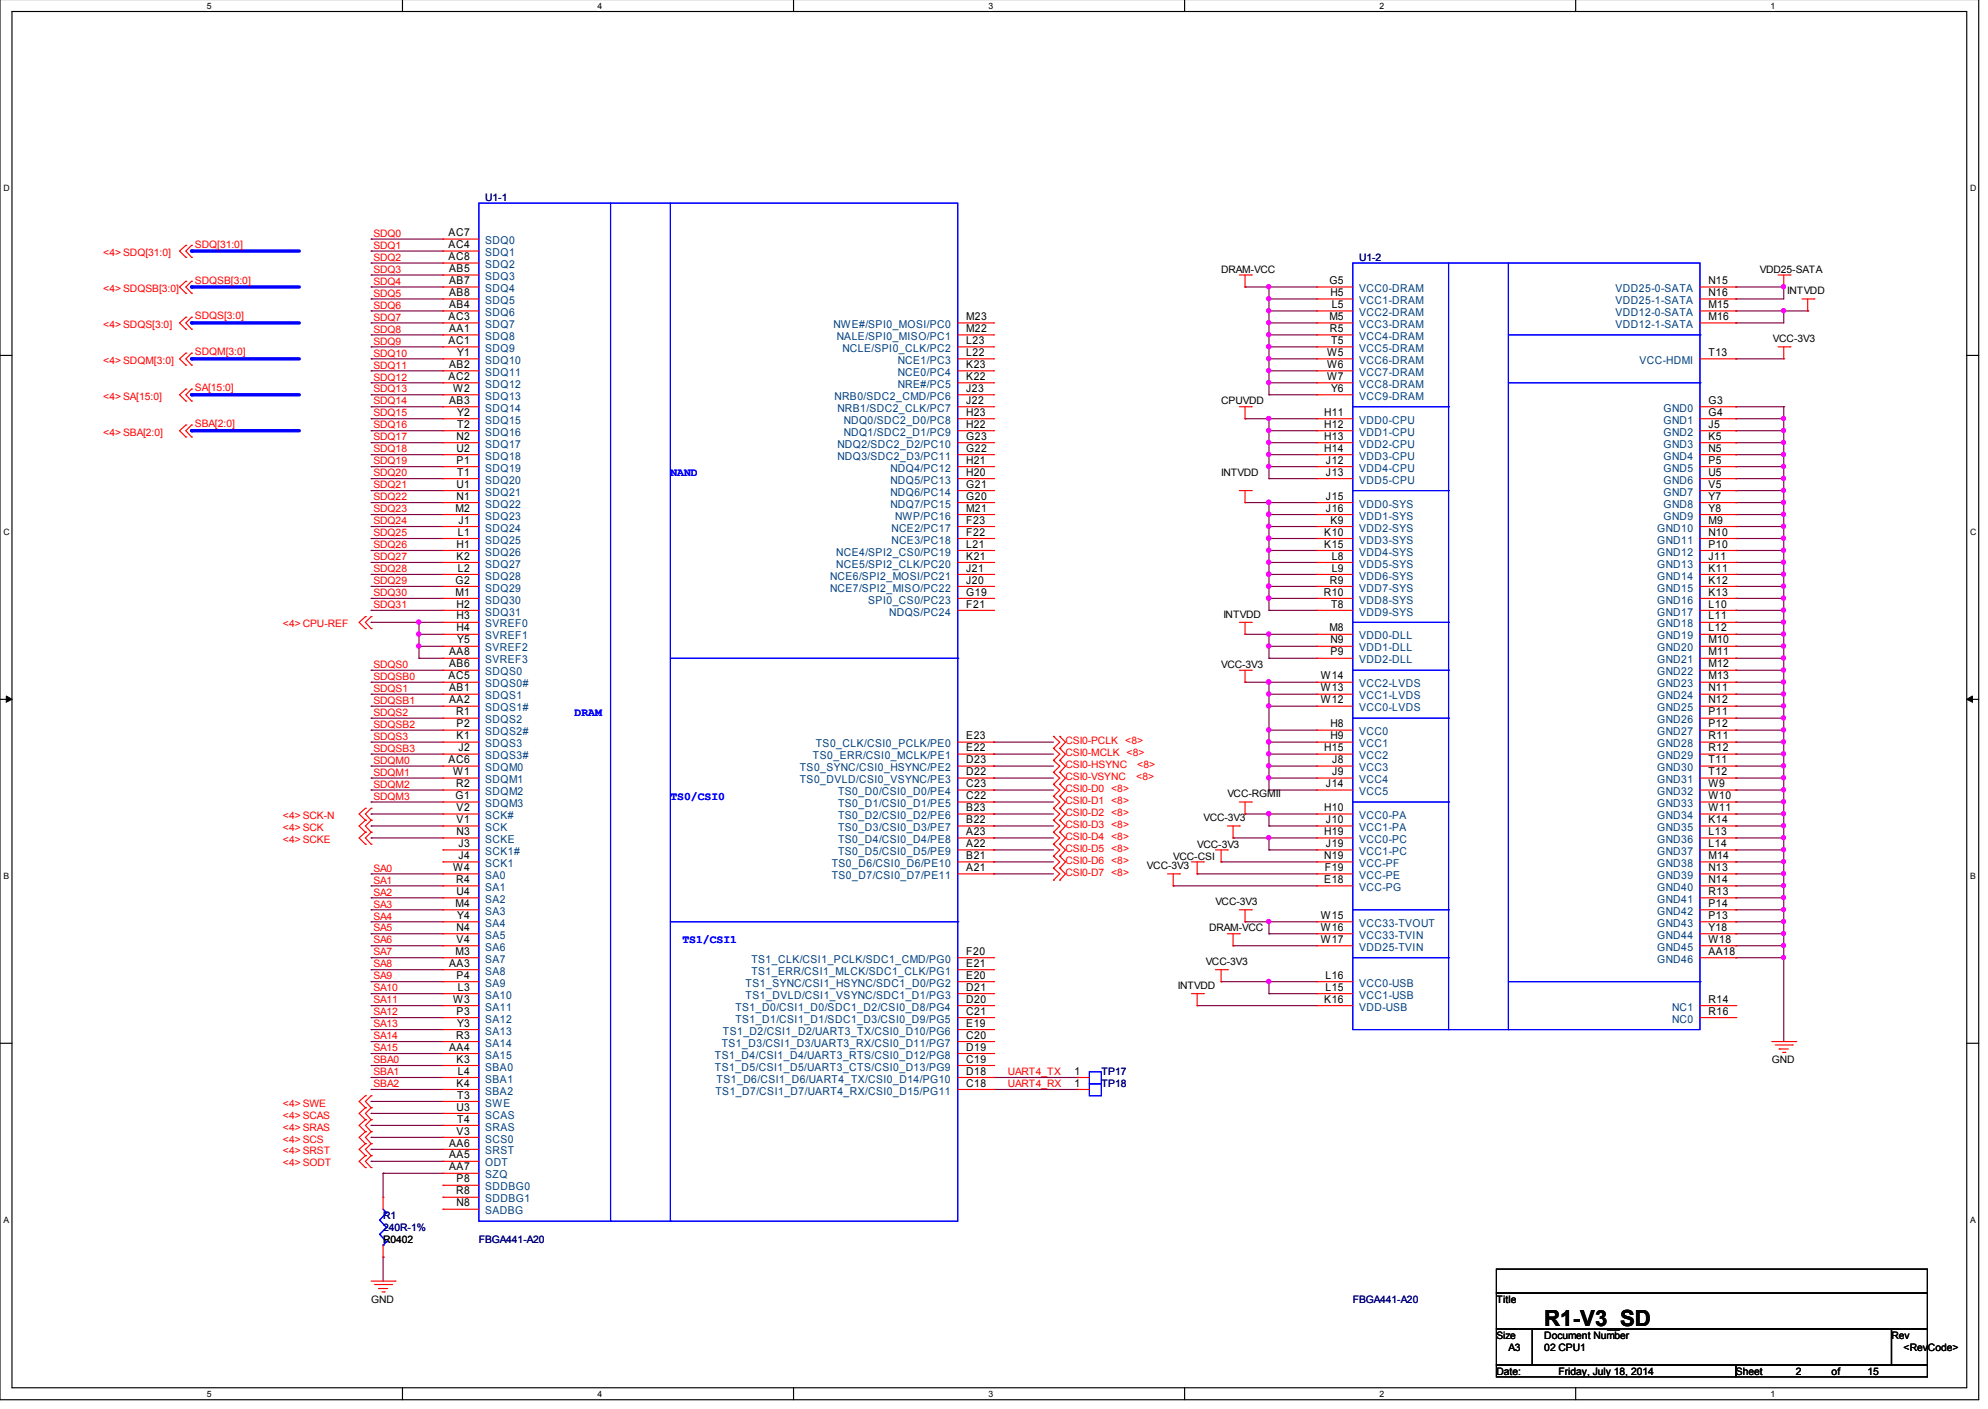
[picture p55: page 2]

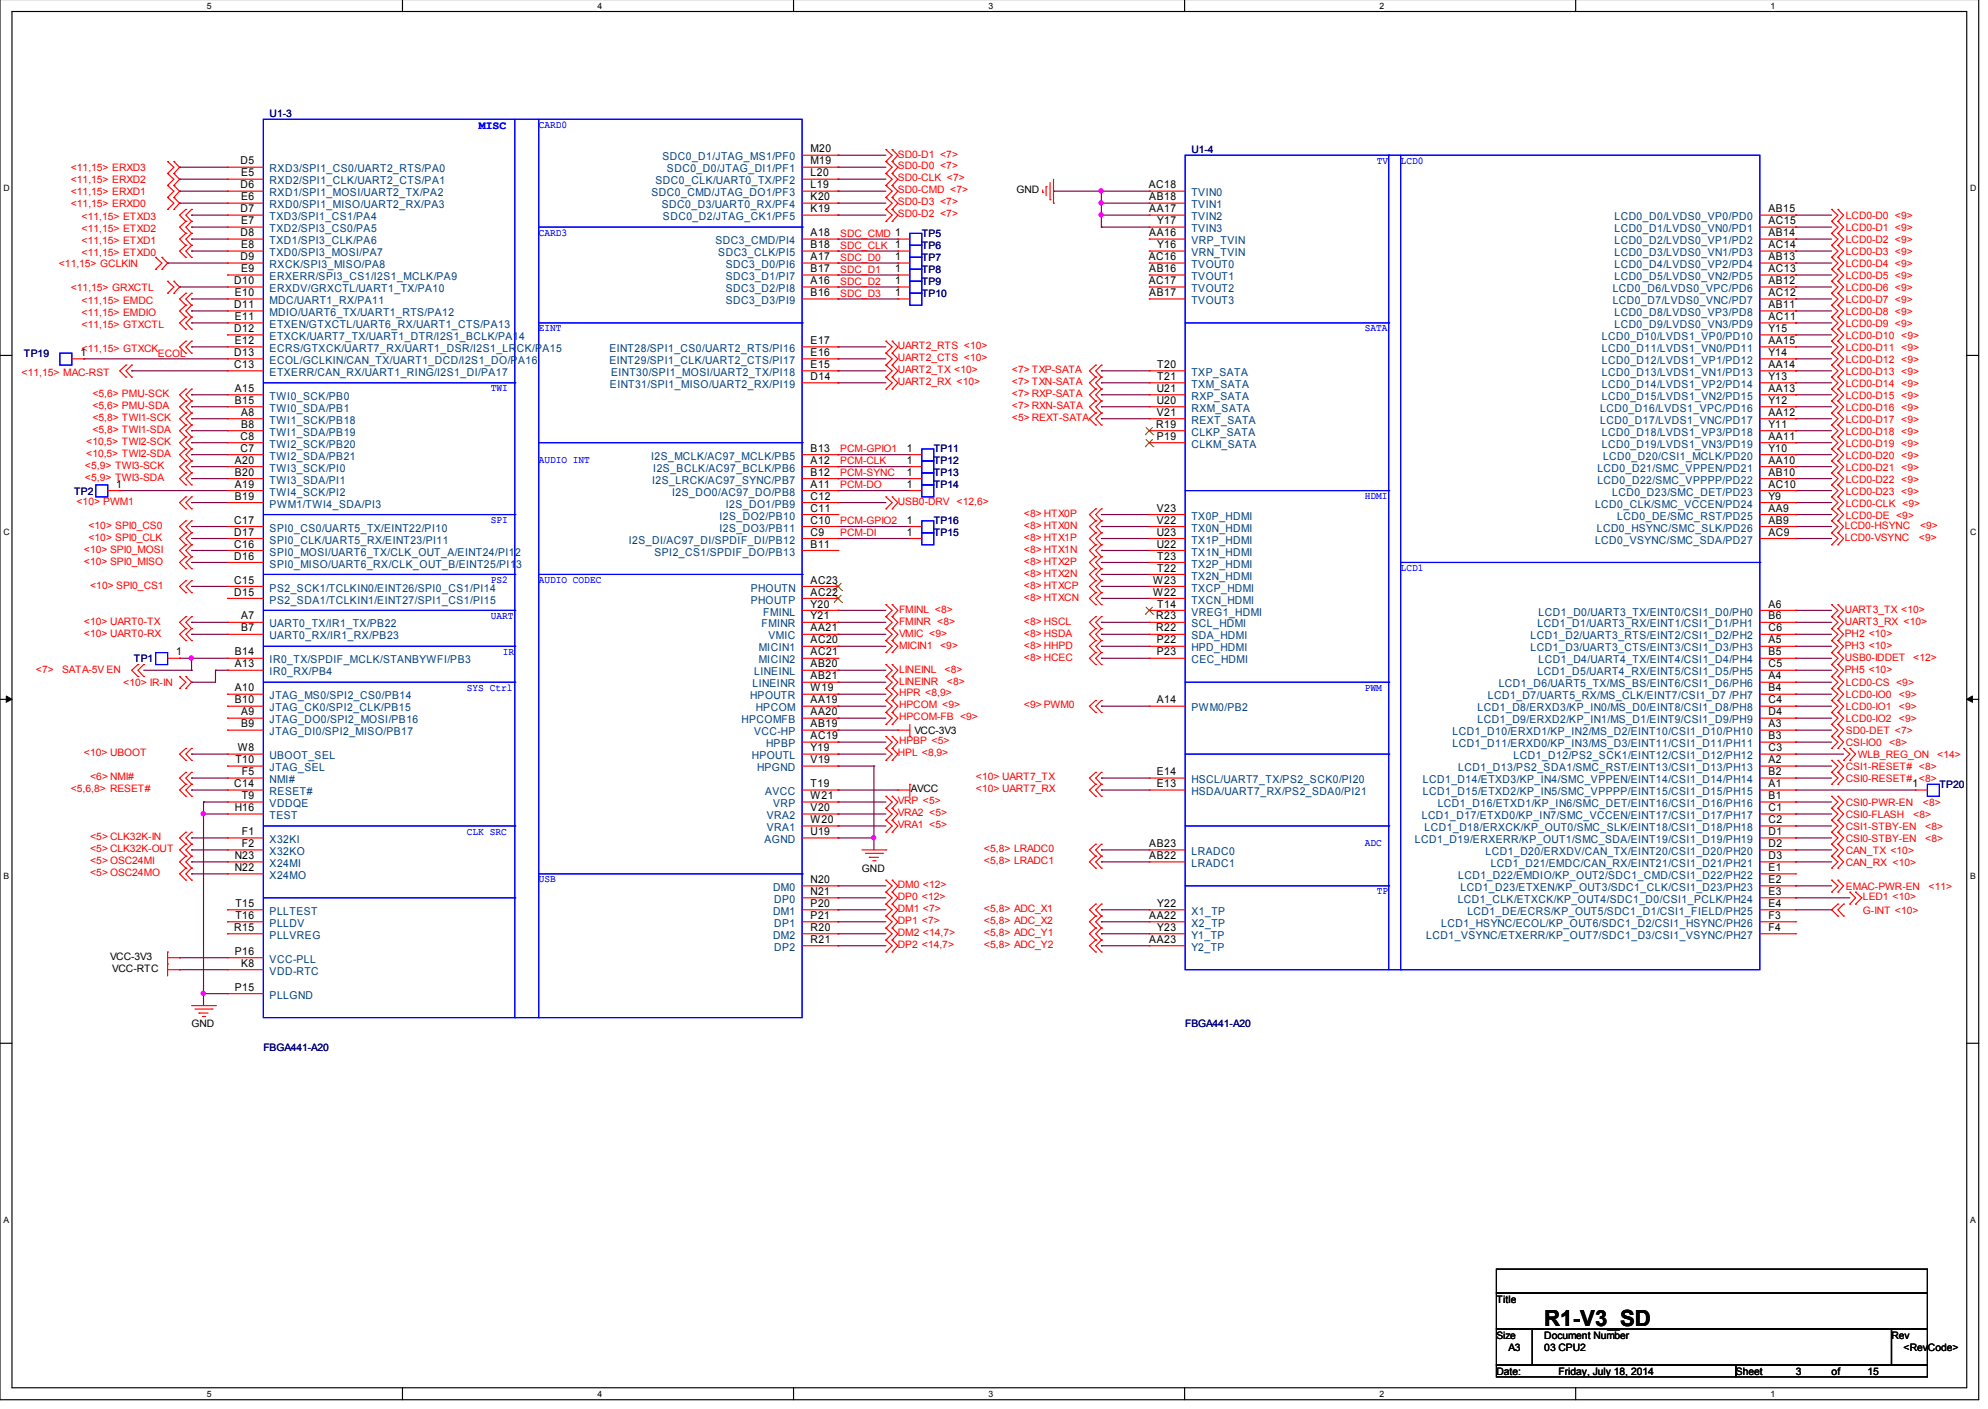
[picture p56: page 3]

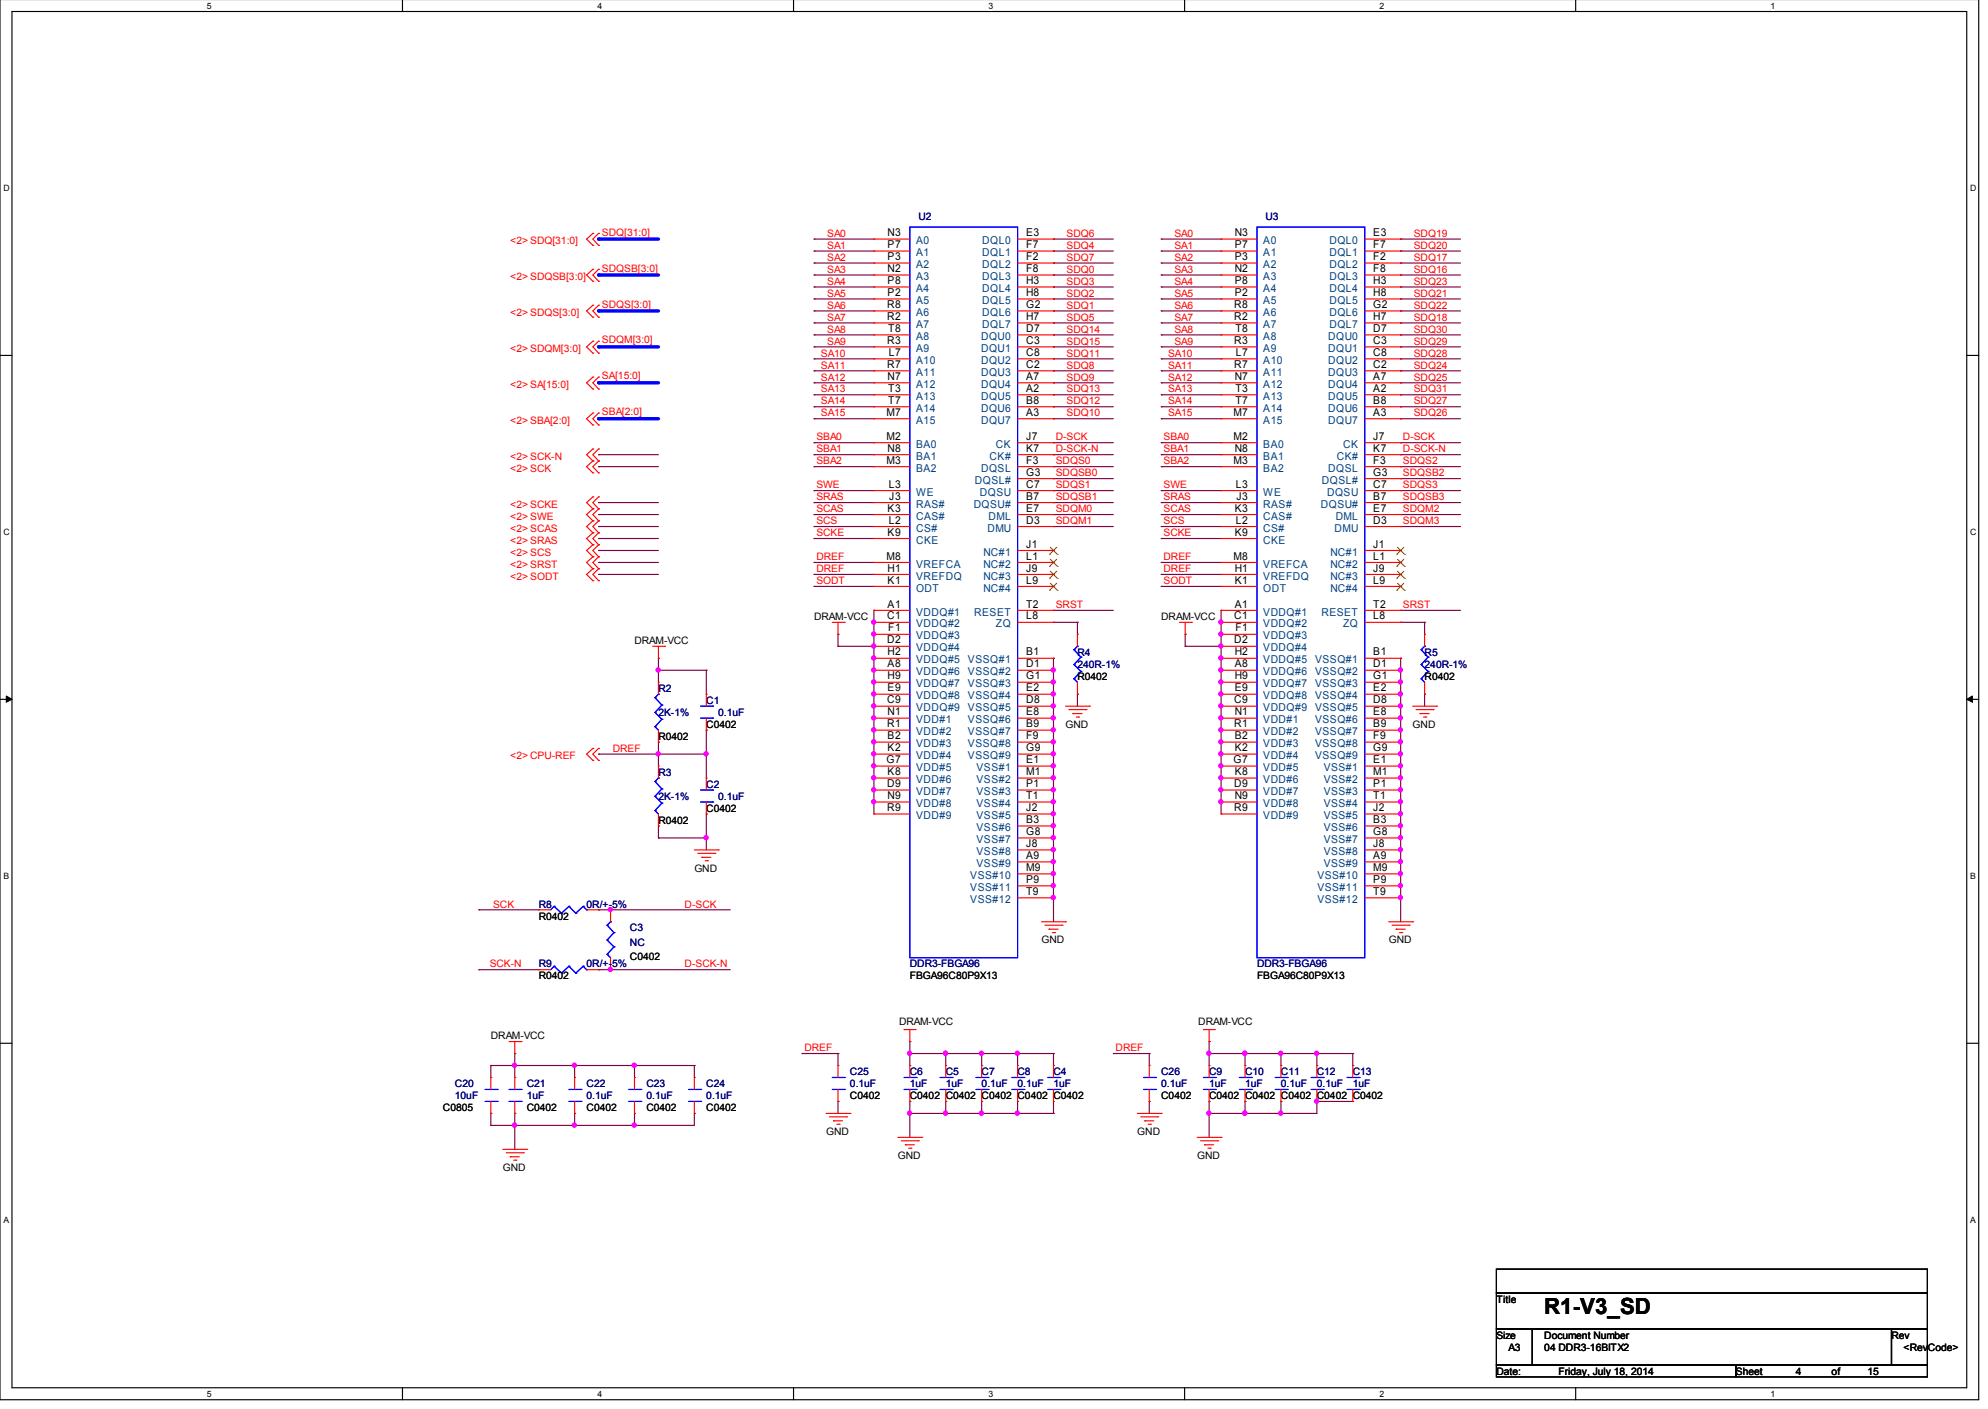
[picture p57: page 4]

## Near the DLLVDD

pin foot placement.

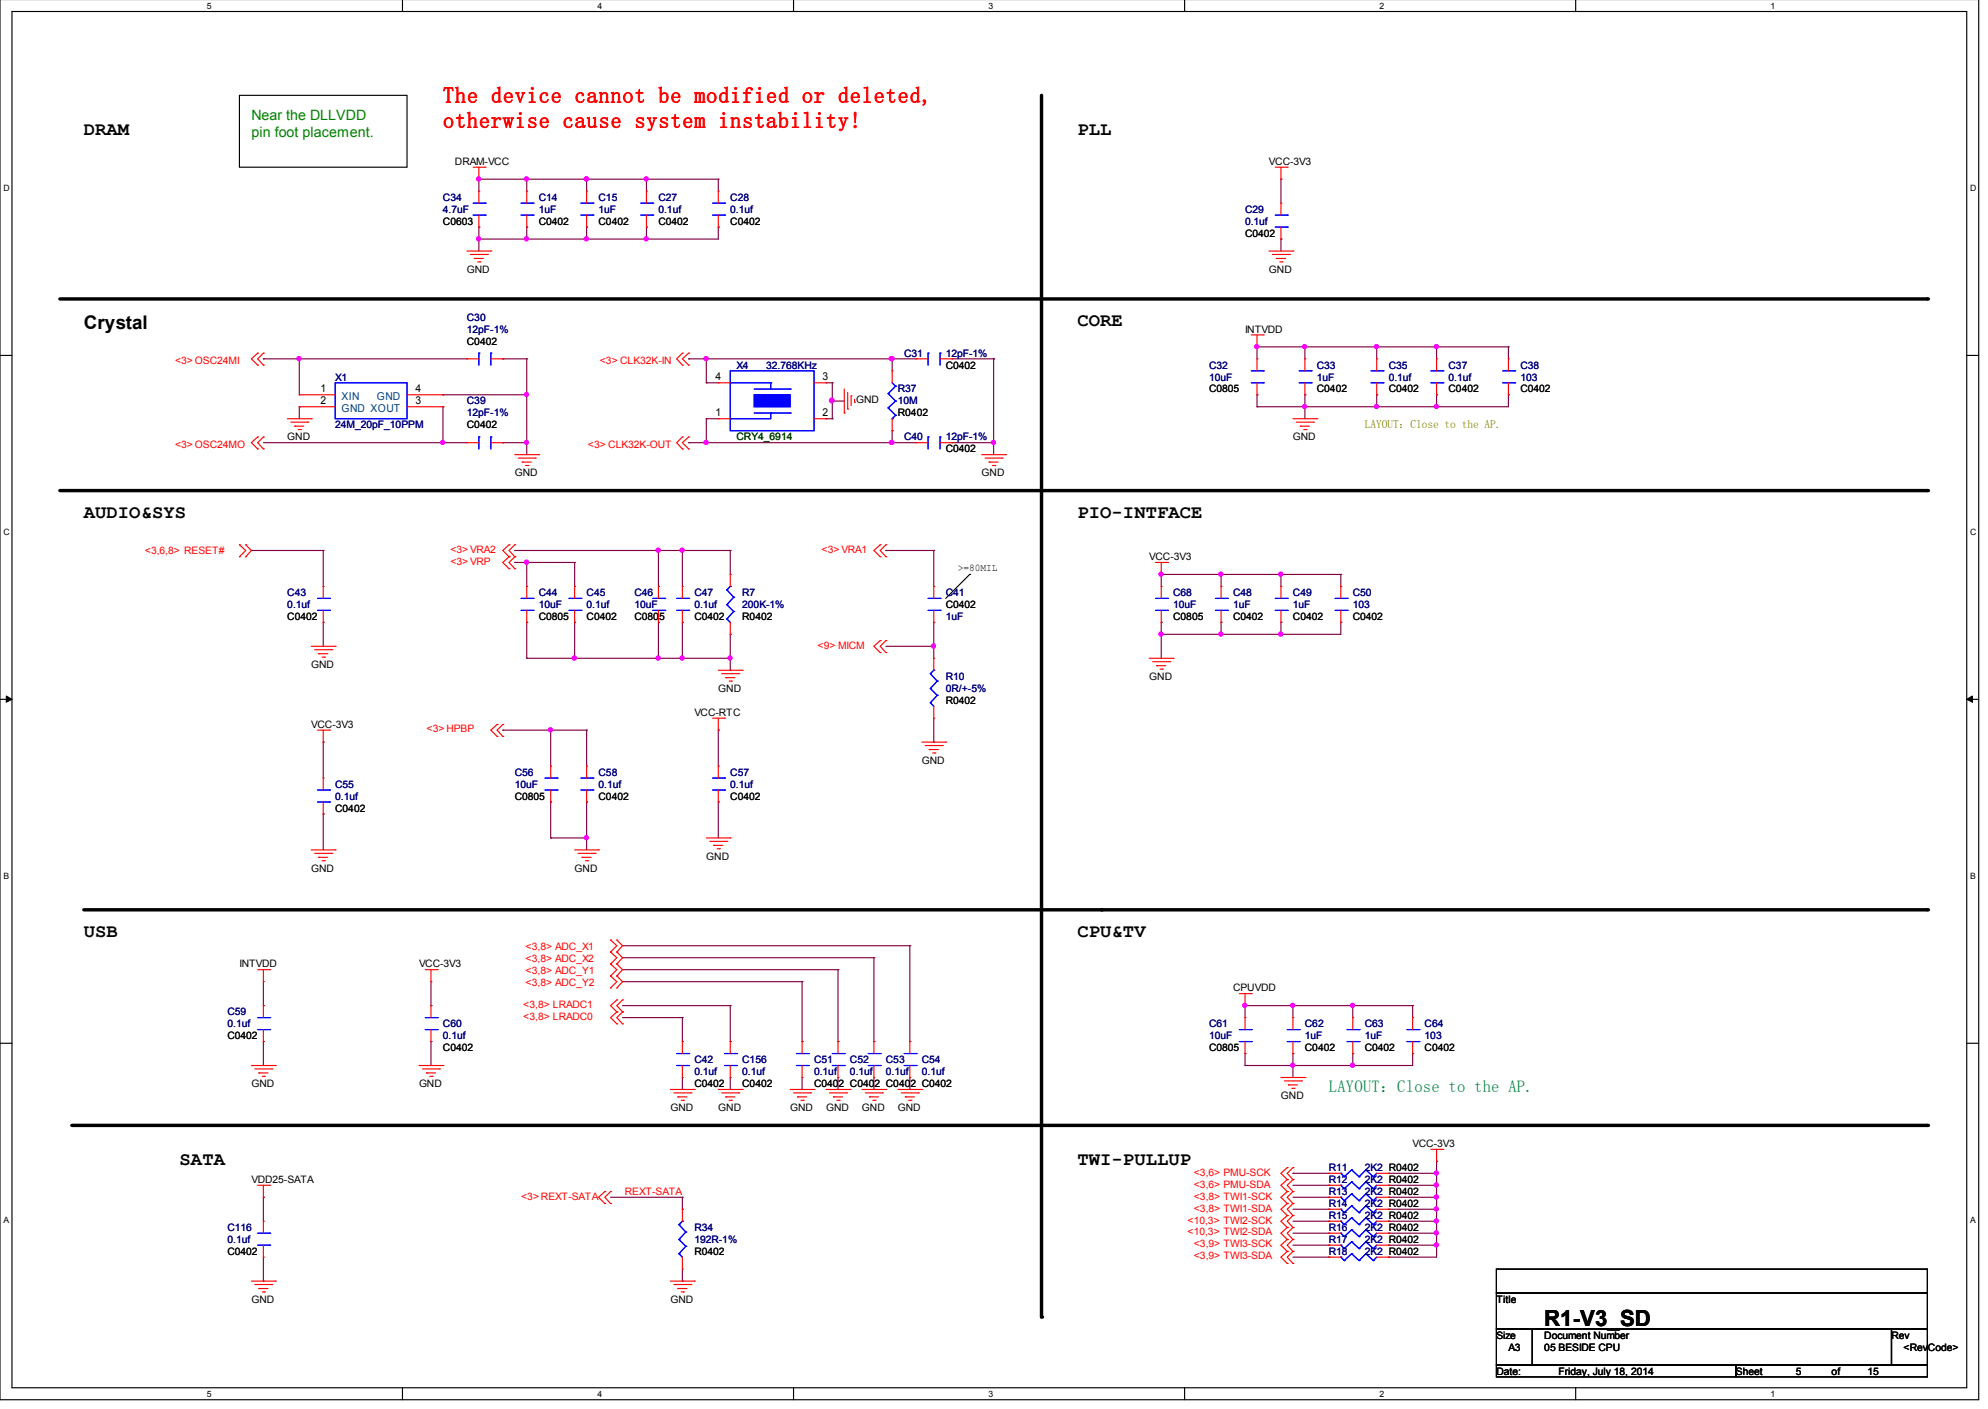
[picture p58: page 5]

The device cannot be modified or deleted,
otherwise cause system instability!

LAYOUT：Close to the AP.

### Power Trace

# PMU-AXP209

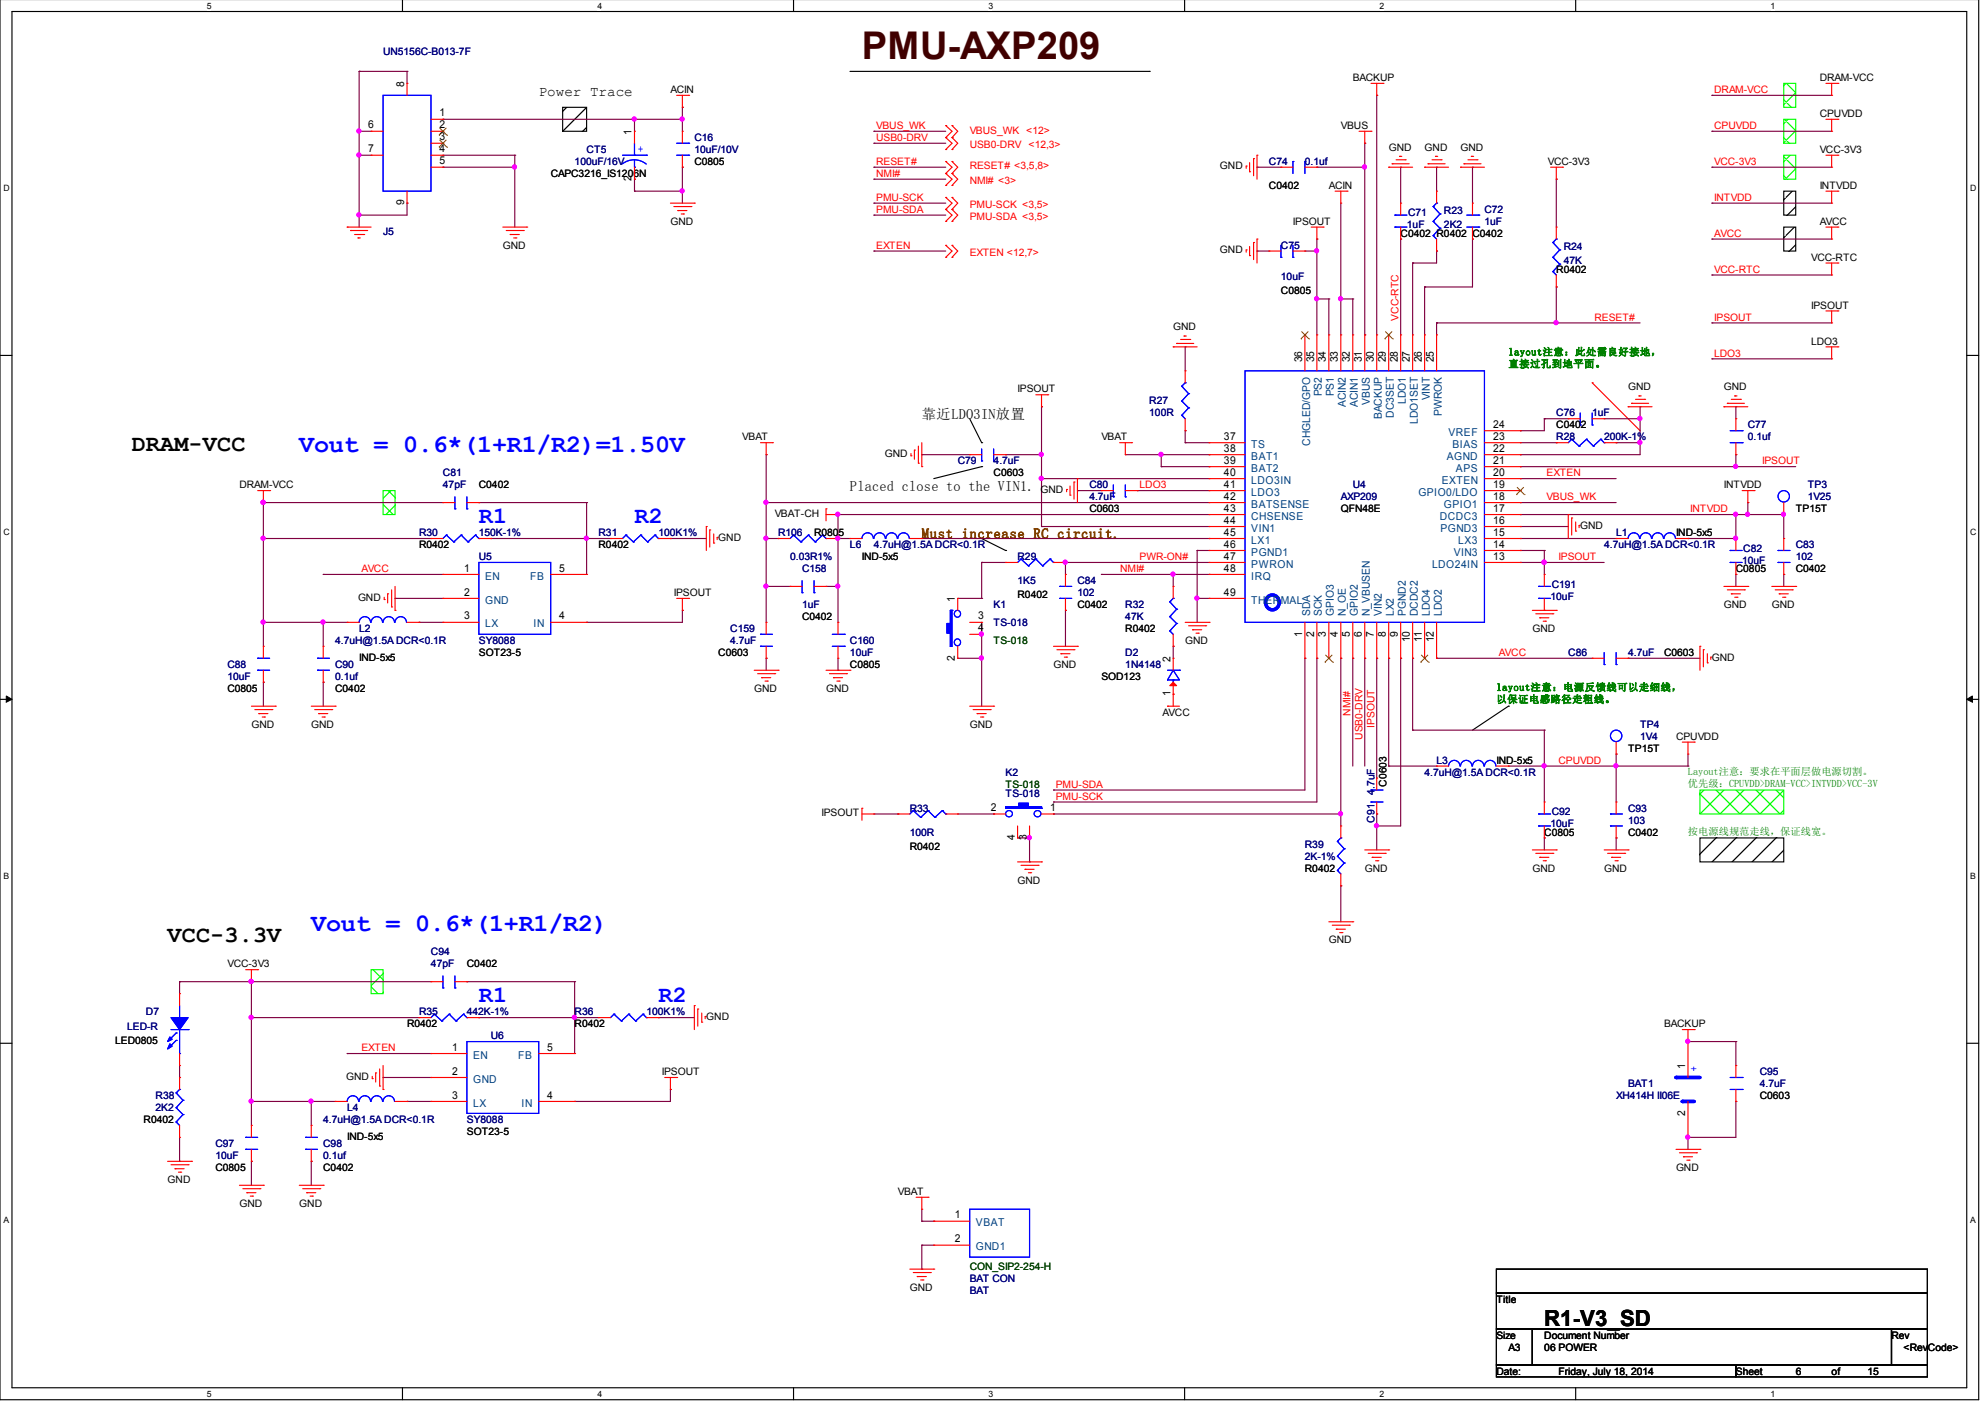
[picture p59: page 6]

PWROK 25 VINT 26 LDO1SET 27 LDO1 28 DC3SET 29 BACKUP 30 VBUS 31 ACIN1 32 ACIN2 33 PS1 34 PS2 35 CHGLED/GPO 36

Placed close to the VIN1.

Must increase RC circuit.

Layout注意：要求在平面层做电源切割。
优先级：CPUVDD>DRAM-VCC>INTVDD>VCC-3V

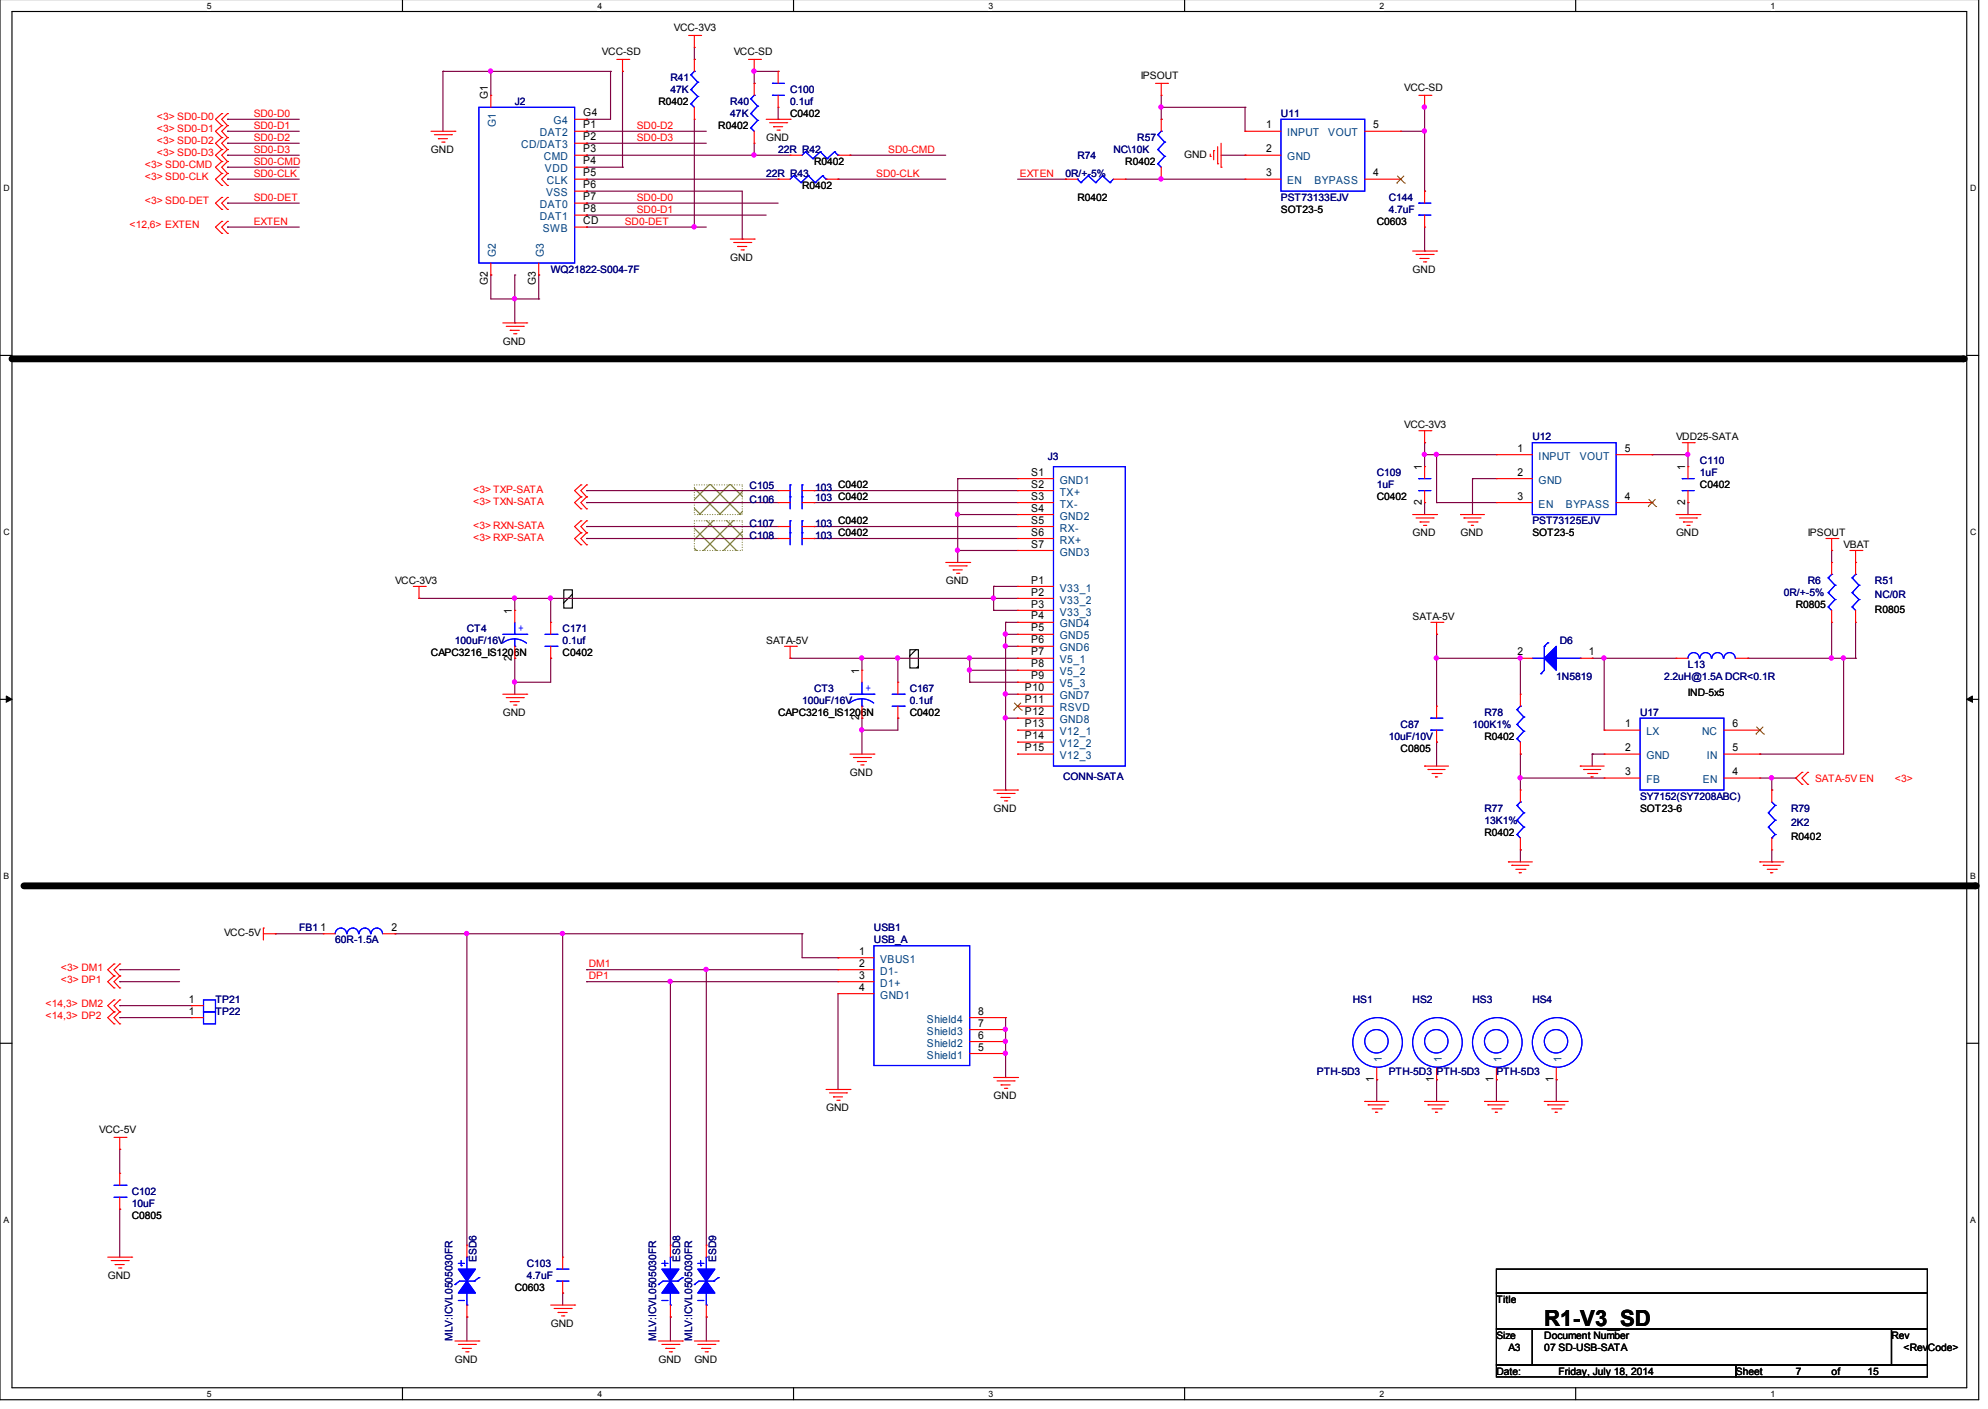
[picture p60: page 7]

HDMI | Differential pairs
| Z0= 100 ohm +/-5 ohm

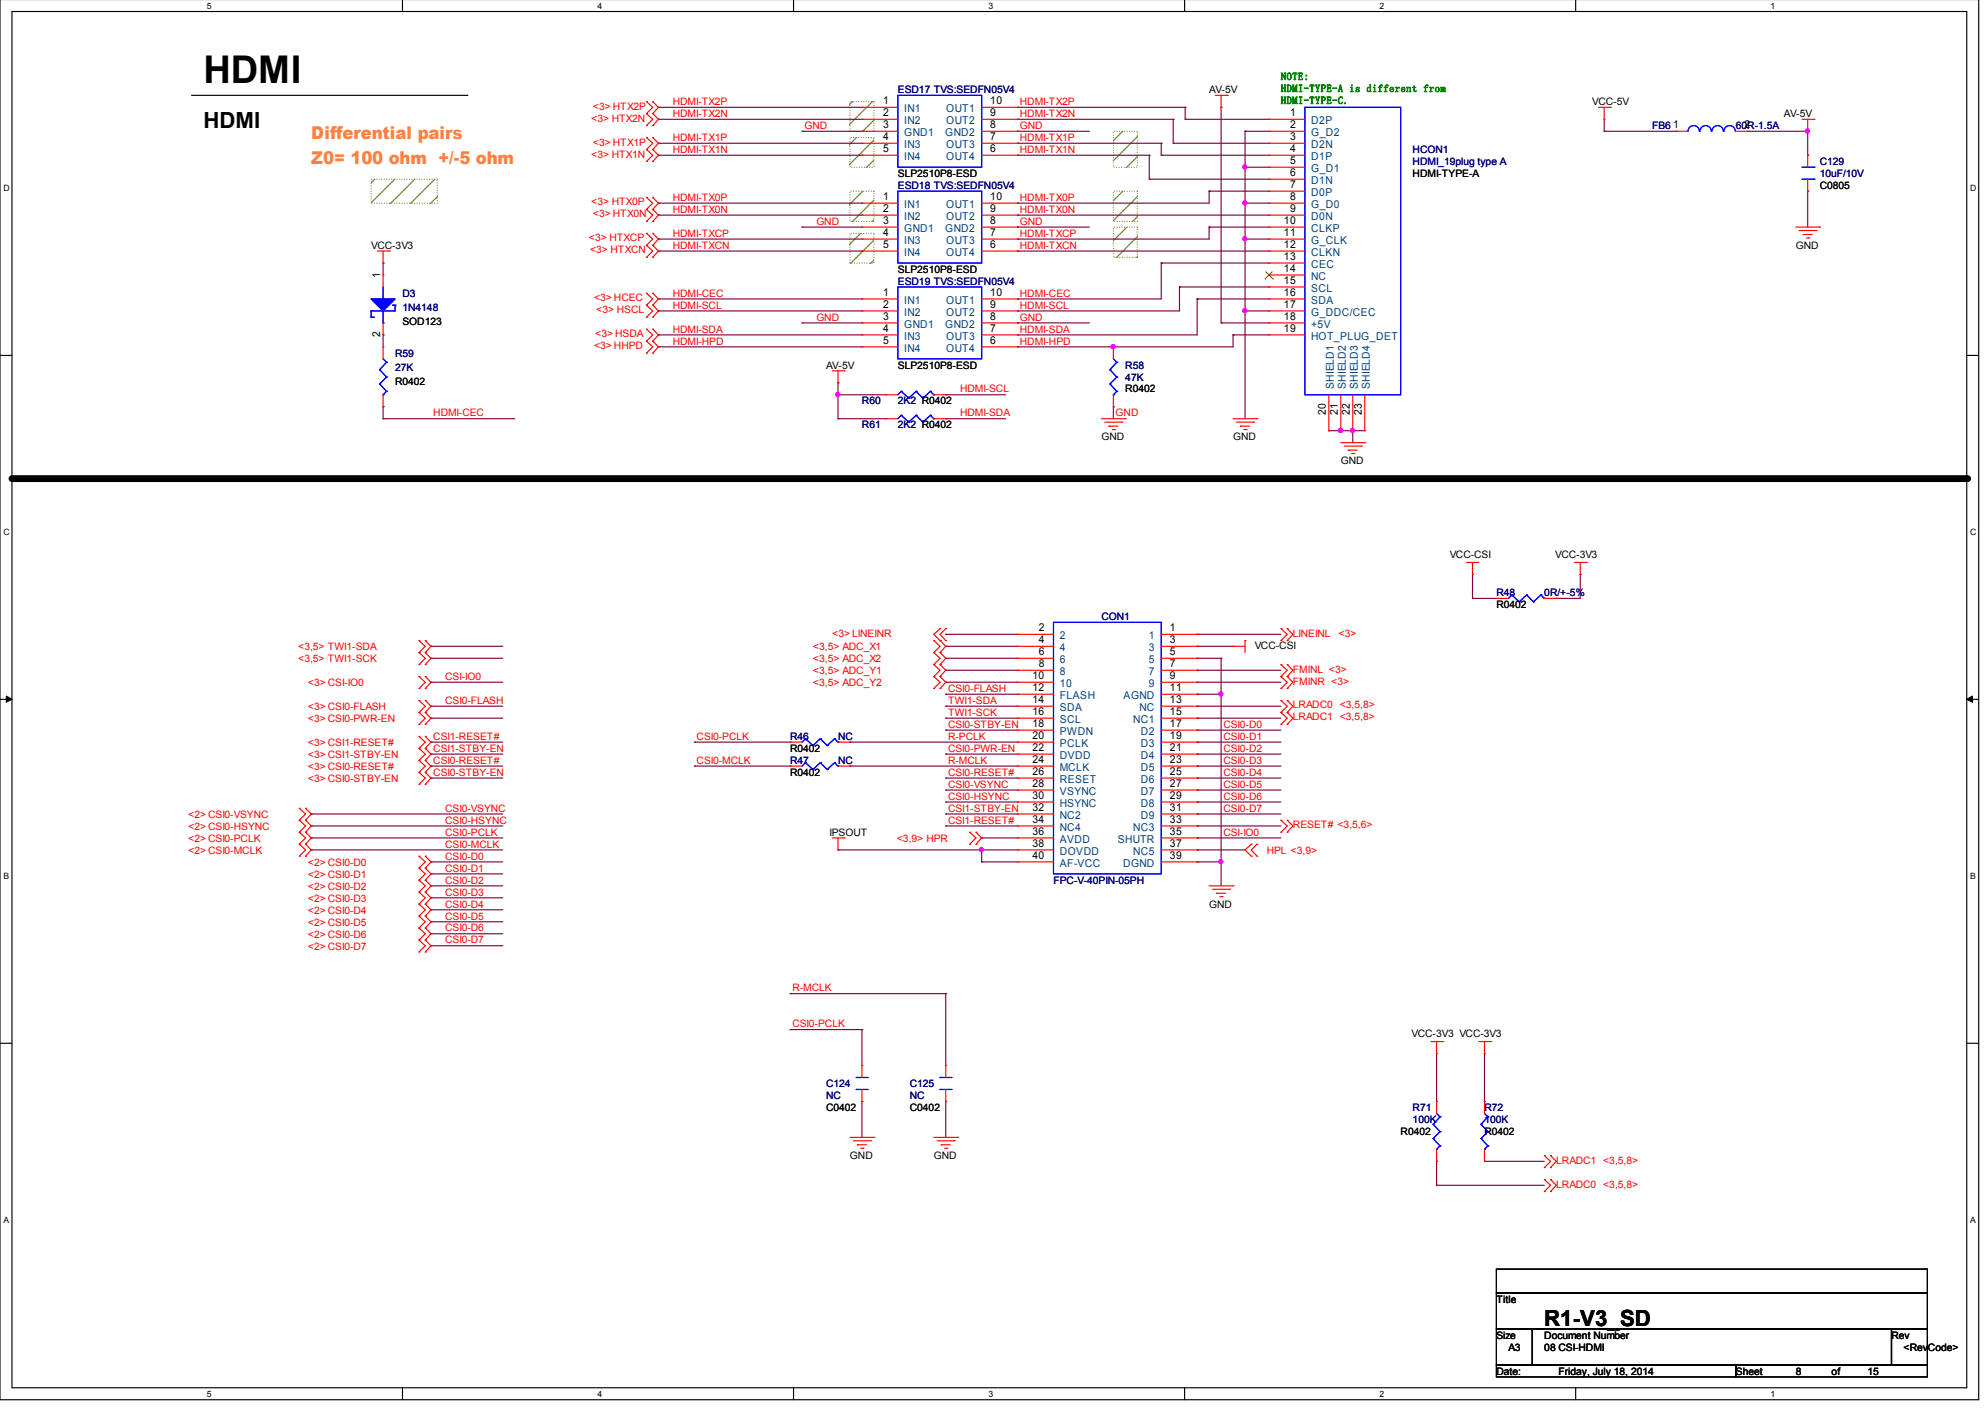
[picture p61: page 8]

HDMI-TYPE-A is different from
HDMI-TYPE-C.

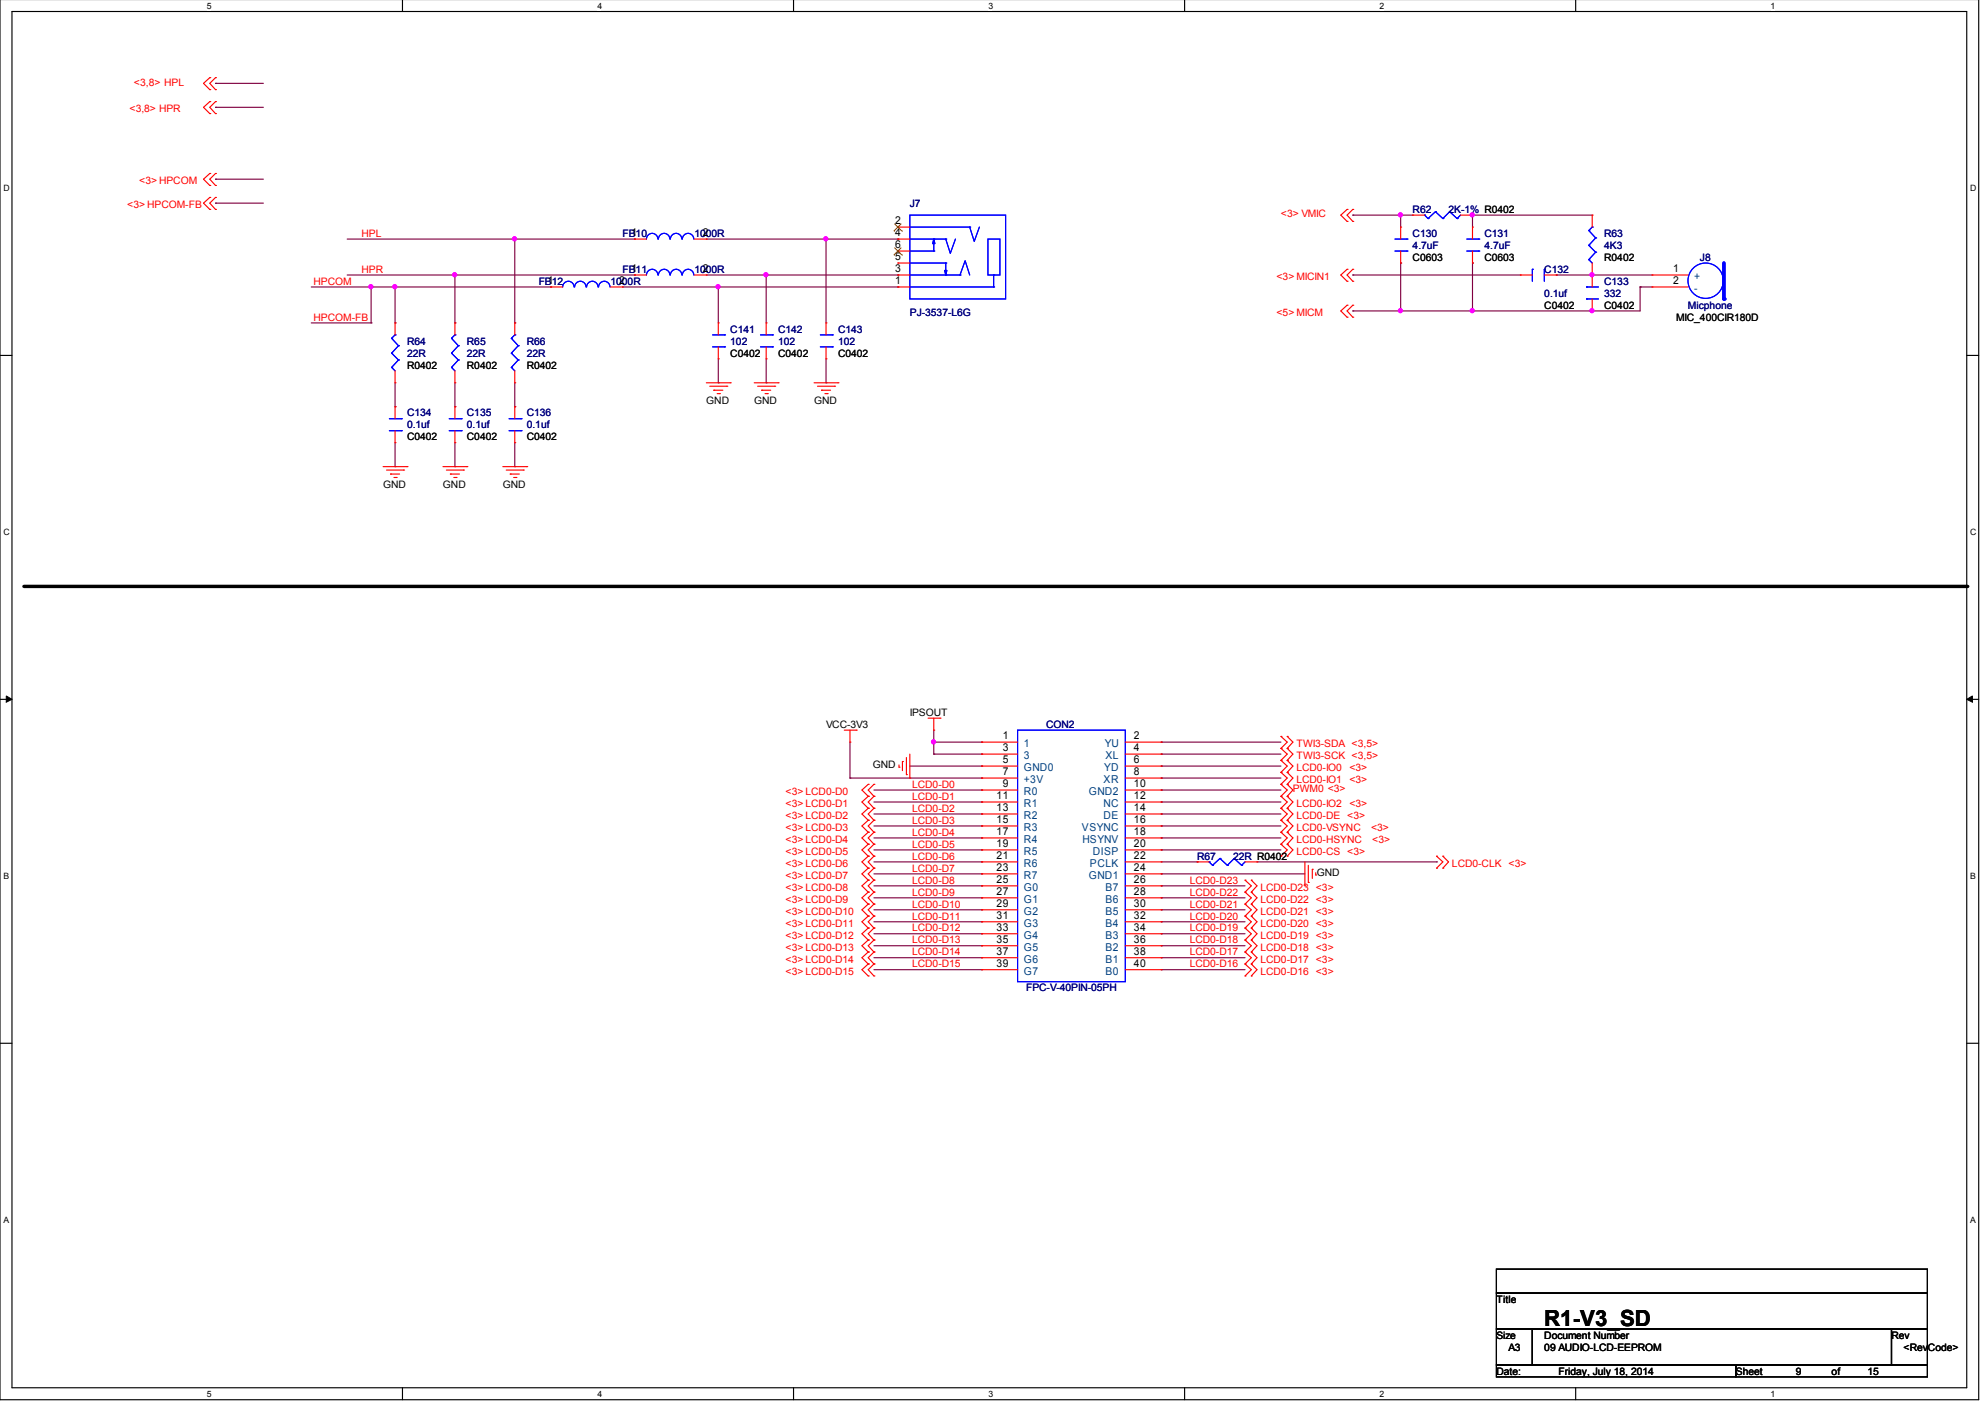
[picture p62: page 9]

# IR MODULE

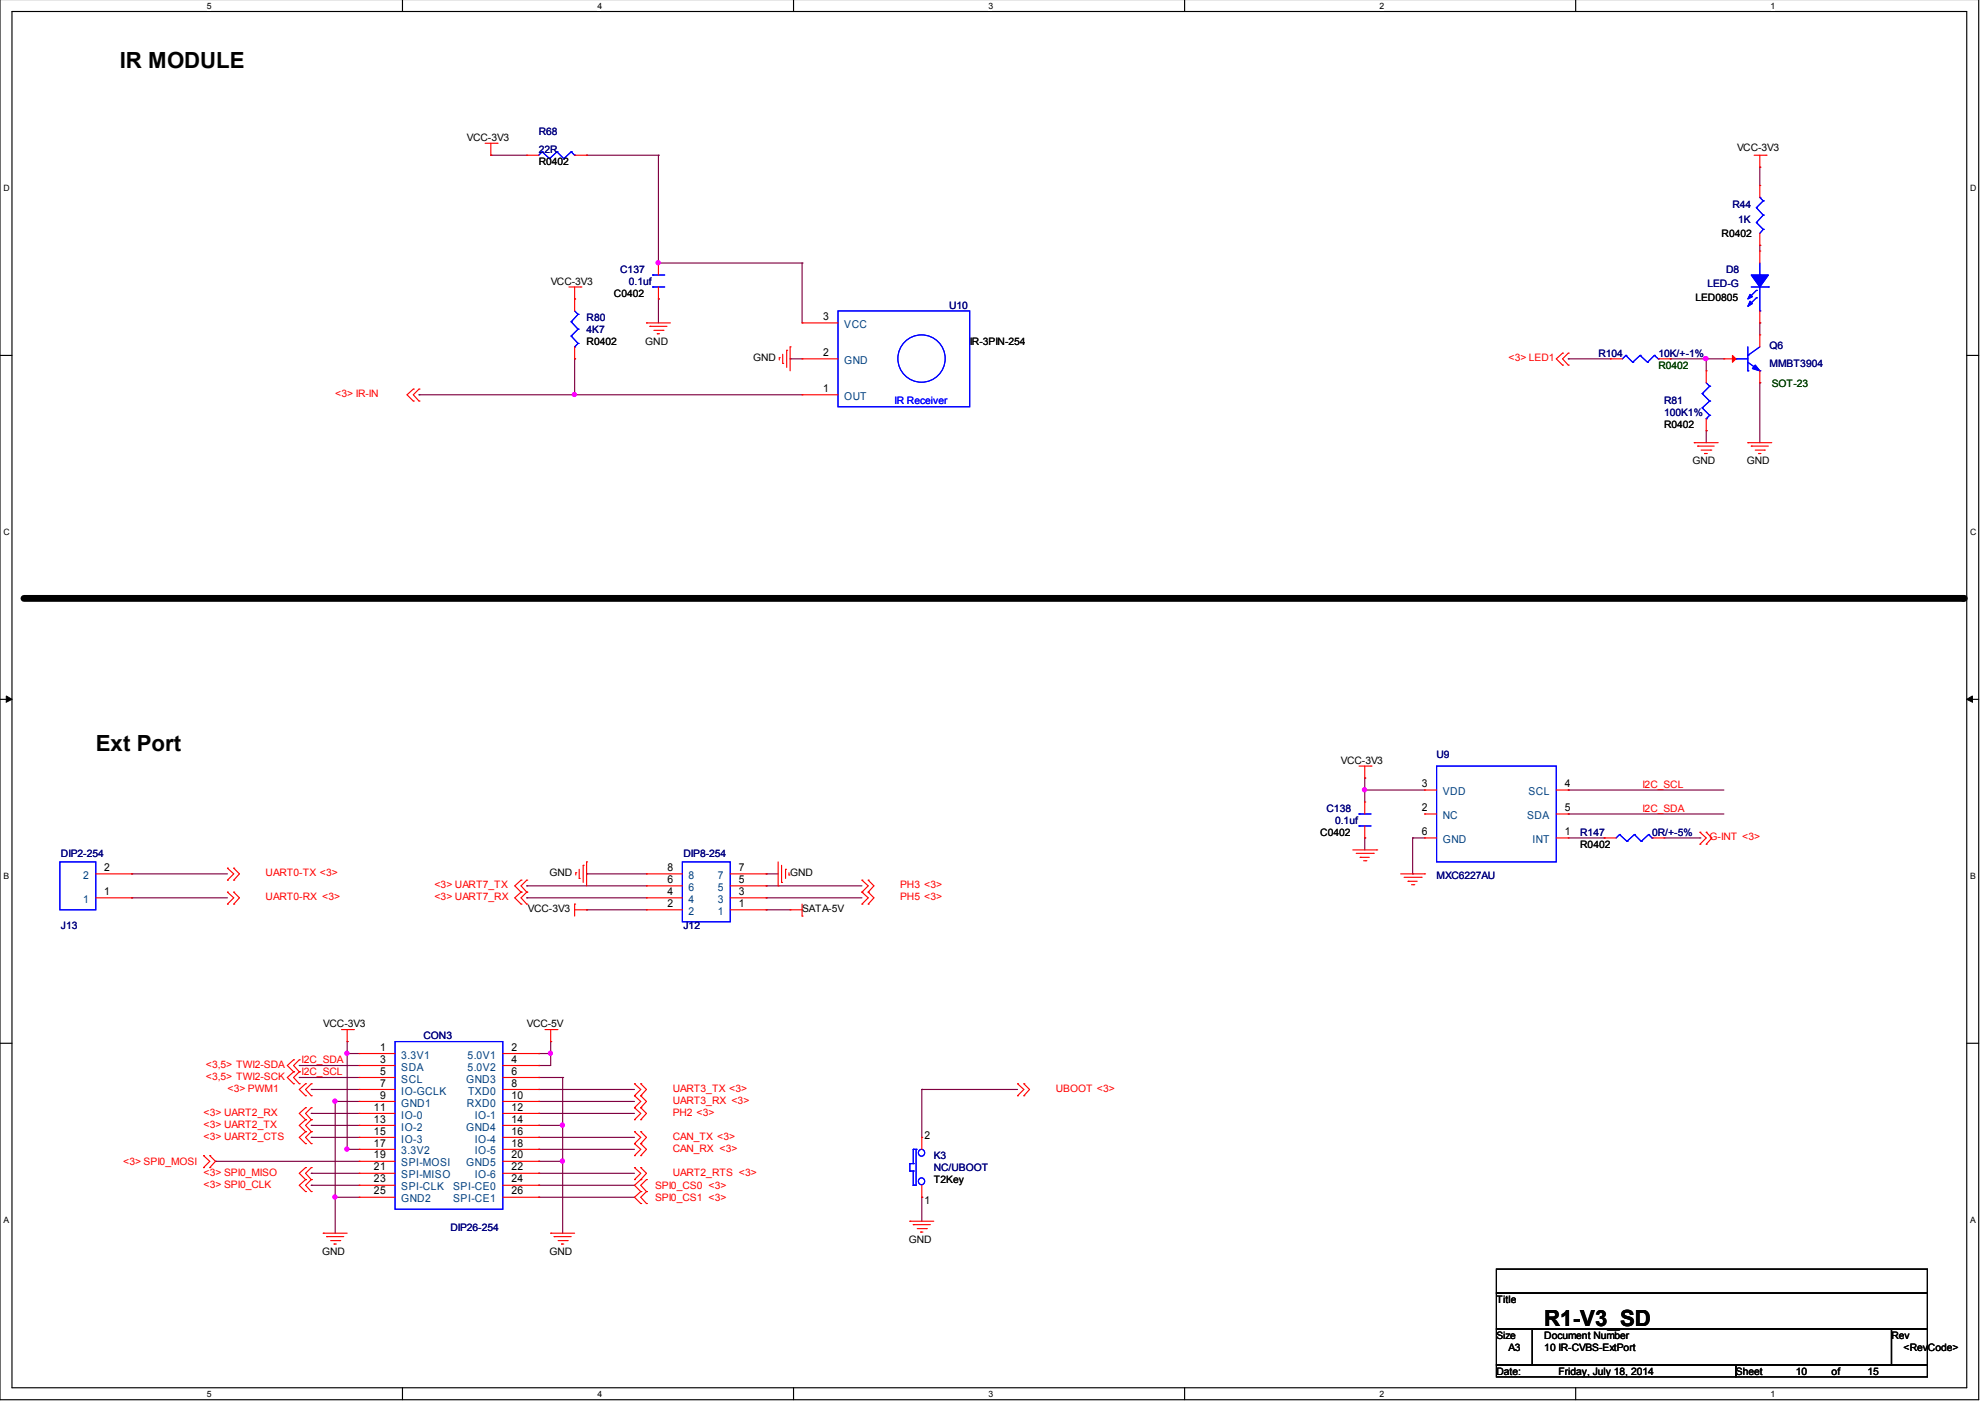
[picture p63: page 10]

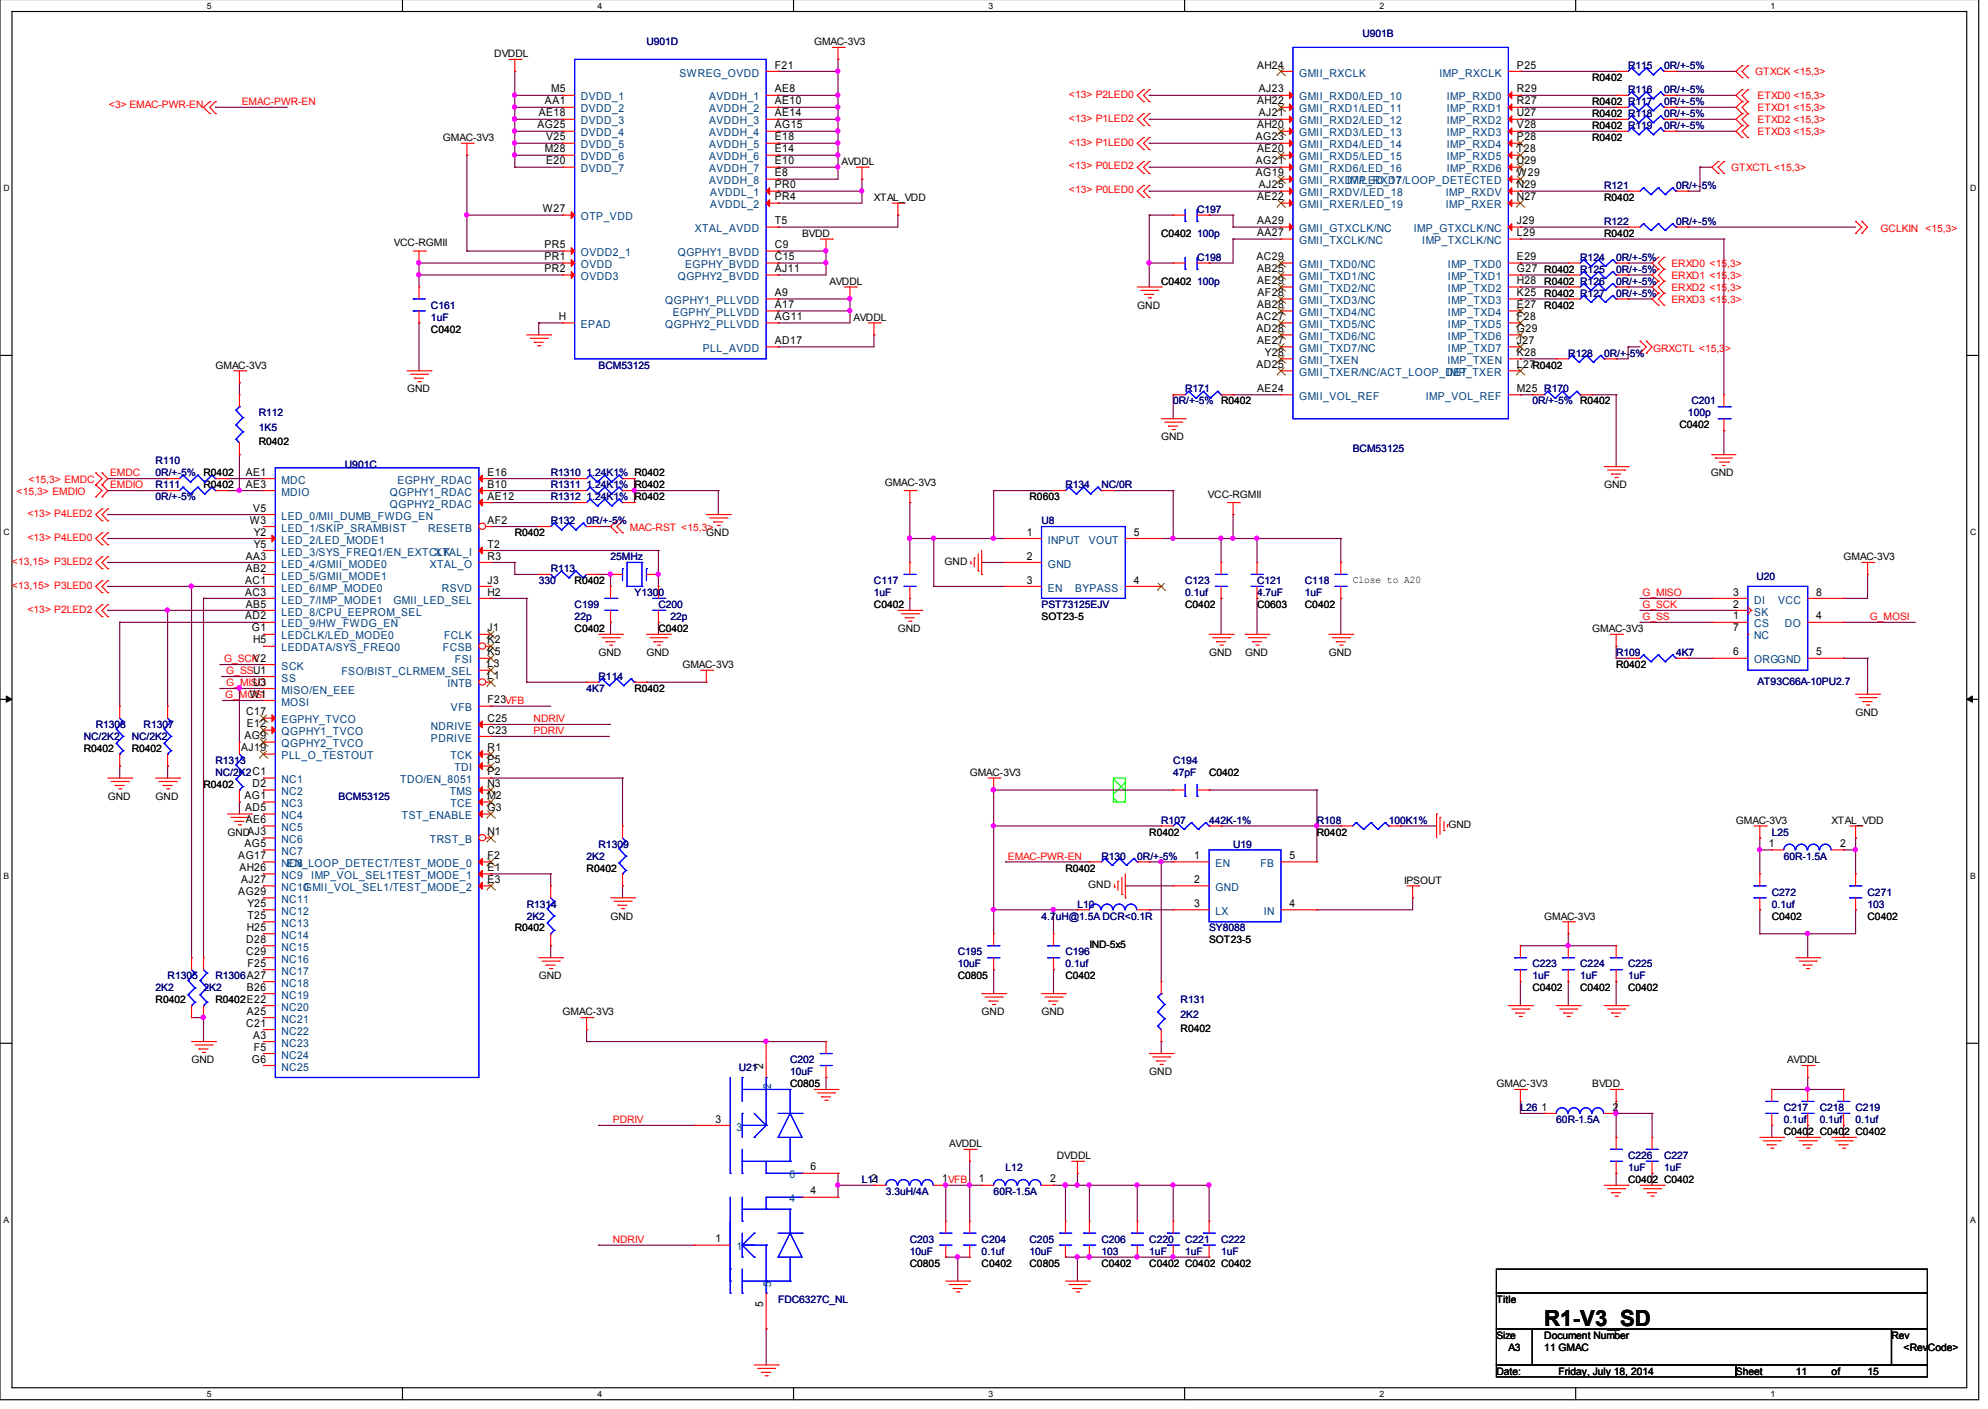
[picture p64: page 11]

D | D

# USB0-IDDET

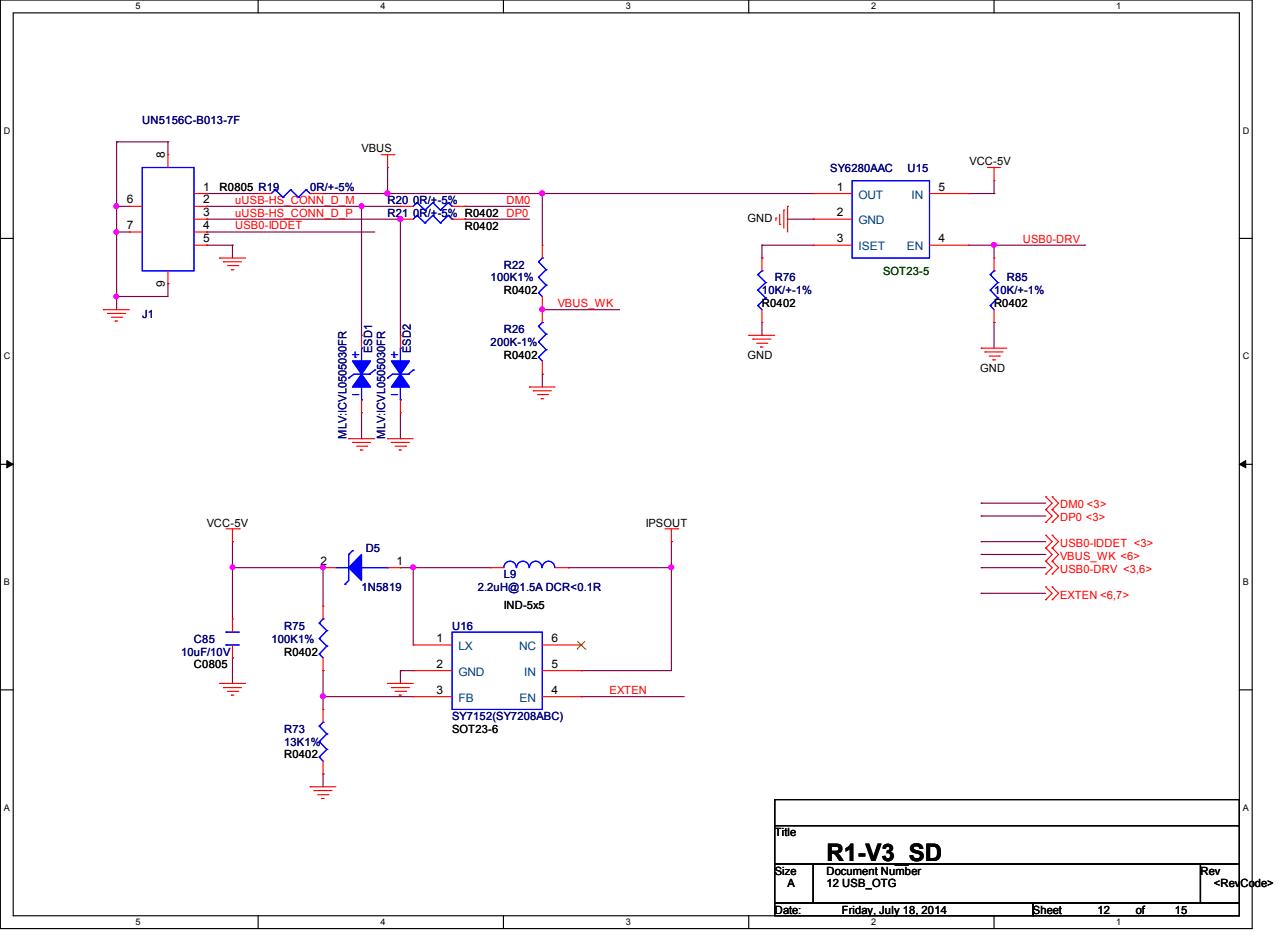
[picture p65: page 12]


D | D

DM2


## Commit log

2017-07-10 Add eeschema libraries to project
    eeschema use system wide libraries by default. The libraries may change
    from kicad version to another. This cause failures in displaying the
    schematic. Put used libraries under version control and make the project
    self contain.
2017-07-10 Add footprints and 3D shapes to project
    pcbnew use system wide footprints and 3D shapes by default. The footprints
    and 3D shapes may change from kicad version to another. This cause failures
    in displaying the PCB. Put used footprints and §D shapes under version
    control and make the project self contain.
2017-07-10 Rotate GPIO terminal header
    The GPIO terminal header had its terminals to the board side.
    Rotate the header by 180 degrees.
    [bpi-r1-can-ser.kicad_pcb, bpi-r1-can-ser.sch, can.sch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]
2017-07-11 Add license text CC by-sa 4.0
    The project is licensed under Creative Commons by-sa license version
    4.0.
    [bpi-r1-can-ser.sch, can.sch, gpio.sch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]
2017-07-11 Connect overseen GND pin
    Pin 14 on Banana Pi GPIO CON3 is connected to GND.
    Change pin from NC to GND.
    [bpi-r1-can-ser.sch]
2017-07-11 Switch MAX3232 sides
    The TTL side of the MAX3232 was connected to the RS232 side and vice versa.
    Connect the inputs and outputs to the correct side.
    [serial.sch]
2017-07-11 Switch TTL/RS232 MAX3232 connection
    The TTL and RS232 Part of the MAX3232 are switched.
    Change Layout to connect the TTL and RS232 to the correct pins.
    [bpi-r1-can-ser.kicad_pcb]
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2017-07-12 Align schematic with layout
    Align schematic with layout after consolidating parts and documentation.
    [bpi-r1-can-ser.kicad_pcb]
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2017-07-12 Change Fieldnames DigiPart# and DigiLink
    Use the more generic field names SupplPart# and SupplLink.
    [bpi-r1-can-ser.sch, can.sch, gpio.sch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]
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2017-07-19 Switch Optocoupler input pins
    Anode and Cathode are switched for one channel. Correct the connection.
    [bpi-r1-can-ser.kicad_pcb, gpio.sch]
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2017-07-20 enclosure rework
    [enclosure.FCStd]
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2017-08-02 Correct some TME part numbers
    Some part numbers are mixed up with the TME part name. Correct the
    entries.
    [bpi-r1-can-ser_TME.csv, can.sch, gpio.sch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]
2017-08-20 Rework enclosure
    - add DIN rail adapter holes
    - round corners
    - better accessability to connectors
    [enclosure.FCStd]
2017-08-20 Export manufacturing data.
    Add manufacturing data for geerscutting (bottom.stp) and formulor
    (*svg).
    [bottom.stp]
2018-02-09 Remove change date from project file
    KiCAD automaticaly changes the date in the project file on each save.
    Replace the date by the sting "Date" as preparatory change for applying
    a git filter by setting ".gitattributes".
2018-02-09 Remove autogenerated numbering from schematic files
    KiCAD handles PWR and FLG internal. While changing a annotation in a
    schematic all PWR and FLG are renumbered. Set all PWR and FLG
    annotations to fixed value "?" to have no autogenerated changes
    in git.
    This is a preparatory change for applying a git filter by setting
    ".gitattributes".
    [bpi-r1-can-ser.sch, can.sch, gpio.sch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]
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2018-03-05 Rework serial connectors
    The Banana Pi serial ports are labeled as DCE instead of more common
    DTE. Swab RX and TX.
    [bpi-r1-can-ser.kicad_pcb, bpi-r1-can-ser.sch, serial.sch]
2018-03-05 serial: Change pinout towards TIA-561
    Change RJ45 serial connector pinout to fit TIA-561.
    [bpi-r1-can-ser.kicad_pcb, serial.sch]
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2018-03-05 serial: undo RX/TX changes for UART7
    UART7 is labled, in oposite to UART0, as DTE. Revert the RX/TX swap.
    [bpi-r1-can-ser.kicad_pcb, bpi-r1-can-ser.sch]
2018-03-05 Mark default solderpads position
    Both serial ports can be configured by solderpads to act as DCE or DTE.
    Mark DCE solderpad position as default.
    [bpi-r1-can-ser.kicad_pcb, serial.sch]
2018-03-05 Fix 3D settings
    Some footprints need 3D corrections before module revision 4.0.7
    an are twisted since commit 4eec38adf6a2 ("Update modules to 4.0.7").
    Revert the corrections.
    [bpi-r1-can-ser.kicad_pcb]
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2018-03-13 rework power switch
    [bpi-r1-can-ser.kicad_pcb, gpio.sch, power.sch]
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2018-03-13 Fix 5V output
    [bpi-r1-can-ser.kicad_pcb]
2018-08-03 Convert to KiCAD 5
    In KiCAD 5 double row connectors are renamed to better describing names.
    Convert the connectors to fit the new names.
    [can.sch, gpio.sch, i2c_spi.sch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]
2018-08-03 Remove latbox functionality for now
    The latbox functionality as now did not work out as thought due to
    speed limitations of the connecting SPI bus and needs to be redesigned.
    Remove the functionality for now.
    [bpi-r1-can-ser.kicad_pcb, latbox.sch, power.sch]
2018-08-03 Add table with project specific libraries
    KiCAD libraries are ongoing development and subject to change. To be able
    to review schematics against a fix version of the libraries the libraries
    used in the schematic are added to the project as git submodules.
    To configure KiCAD to use these libraries a configuration file is needed.
    Add the configuration file "sym-lib-table".
    [enhance commit message]
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2018-08-06 Add documentation for solid-state-relay
    Documentation for the Anly Electronics ASR-05DA solid-state-relay is
    missing. Add appropriate datasheet.
    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
    [power.sch]
2018-08-06 Add missing datasheet for reed relays
    The HE721C0500 symbol reference to a datasheet, wich is missing.
    Add the datasheet.
    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
2018-08-06 Add reference to datasheet for IRLHS2242
    The datasheet for IRLHS2242 was added, but not referenced. Add the
    missing reference to symbol.
    [power.sch]
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2018-08-06 Update schematic to KiCAD 5 symbols
    Revisit the schematics and convert to new symbols from the central
    KiCAD symbol git repository.
    [can.sch, gpio.sch, i2c_spi.sch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]
2018-08-06 Update footprints to KiCAD 5
    Revisit the PCB layout and convert to new footprints from the central
    KiCAD footprint git repository.
    [bpi-r1-can-ser.kicad_pcb, can.sch, gpio.sch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]
2018-08-06 Update 3D shapes to KiCAD 5
    Revisit footprints and update to the new central KiCAD 3D shape git
    repository.
    [bpi-r1-can-ser.kicad_pcb]
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2018-08-06 Add crypto memory
    To be able to save private keys on a testbox a crypto memory is
    helpfull. Add a Microchip crypto memory to fit the needs.
    [bpi-r1-can-ser.kicad_pcb, i2c_spi.sch]
2018-08-06 Add relais jumper
    Add a jumper to be able to disconnect the solid state relais from
    switching power if not needed.
    [bpi-r1-can-ser.kicad_pcb, power.sch]
2018-08-06 Add missing documentation
    Revisit the schematics and add missing documentation.
    [can.sch, gpio.sch, i2c_spi.sch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]
2018-08-06 Add missing 3D models
    Some 3D models are missing in the 3D sight. Add the missing 3D shapes.
    [191-009-213.STEP, bpi-r1-can-ser.kicad_pcb, he700.fcstd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]
2018-08-14 Convert shape to VRML
    KiCAD is cabable to handle STEP shapes, if freeCAD is installed. VRML 2.0
    files are supported without any extra dependency.
    Convert Sub-D 9 connector shape from STEP to VRML 2.0 and add the result.
    [bpi-r1-can-ser.kicad_pcb]
2018-08-14 Change GPIO resistors value
    The A20 GPIOs are capable of a current of ~20 mA. The 100 Ohms resistor
    to the opto coupler limits the current to ~20 mA. Driving the GPIOs at
    current limit may cause thermal failures. To be on save side change the
    value to 200 Ohms since the opto works fine with 10 mA also.
    [gpio.sch]
2018-08-14 Add I2C pullups
    The I2C bus may need adapted to adapt pullups for a reliable comunication.
    Be prepared with two 0603 pullups in the layout.
    [bpi-r1-can-ser.kicad_pcb, i2c_spi.sch]
2018-08-14 Add footprint and 3D shapes for PhoenixContact MKKDSN-1,5-3-5,08 connector
    Designation:
    MKKDSN 1,5/ 3-5,08
    Short description:
    PCB terminal block
    Long description:
    PCB terminal block, nominal current: 13.5 A, nom.
    voltage: 400 V, pitch: 5.08 mm, number of
    positions: 3, connection method: Screw connection
    with tension sleeve, mounting: Wave soldering,
    conductor/PCB connection direction: 0 <B0>, color:
    green. The article can be aligned to create
    different nos. of positions!
    [pxc_1726066_06_MKKDSN-1-5-3-5-08_3D.stp]
2018-08-14 Merge 5V power and external switch on one connector
    5V power supply for external boards and the extrnal switch are not
    positioned very well. To achieve the connectors the cover of the testbox
    must be opened. Merge both connectors to a single one and place the
    connector at a place reachable directly from outside.
    [bpi-r1-can-ser.kicad_pcb, can.sch, gpio.sch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]
2018-08-14 Add IRM-20 3D model
    Add a 3D model for the MeanWell IRM-20 power supply.
    [IRM-20.FCStd]
2018-08-14 Rework IRM-20 footprint
    While adding a 3D model for IRM-20 a failure in the footprint was
    descovered. The layout in the datasheet is bottom view, while the
    footprint is top view. Rework IRM-20 footprint and update PCB layout.
    [bpi-r1-can-ser.kicad_pcb, power.sch]
2018-08-14 Switch PE plane from bottom to top
    The high voltage part on bottom PCB must be secured by some isolator
    anyway. On the top side the user need to handle with screw drivers.
    Put the high voltage routes on the bottom side and switch the PE plan
    to the top side. While at it, remove the now unneeded cuttings.
    [bpi-r1-can-ser.kicad_pcb]
2018-08-14 Move JP1
    The position of JP1 prevent an optional angled mounting of the solid
    state relais. Move JP1 to get the required space.
    [bpi-r1-can-ser.kicad_pcb]
2018-08-14 Add 3D shape for solid state relay
    Add a 3D model for the Anly ASR05-DA solid state relay.
    [ASR.FCStd, bpi-r1-can-ser.kicad_pcb]
2018-08-14 Add 3D shape for fuseholder
    Add a 3D model for the TR5 fuseholder.
    [FMS250V.STEP, bpi-r1-can-ser.kicad_pcb]
2018-08-14 Fix AC connectors
    The footprints of J601 and J610 differ although it is the same part.
    Furthermore some information is missing or does not belong to the part.
    Revisit the part and correct it.
    [bpi-r1-can-ser.kicad_pcb, power.sch]
2018-08-14 Add missing external parts
    Add missing parts:
    - BPi R1 router board
    - Mica electrical insulating film
    - Add AC in/out plugs
    [bpi-r1-can-ser.kicad_pcb, can.sch, gpio.sch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]
2018-08-14 CAN: Change connector from female to male
    The CANOpen standard defines a male connector.
    Change from a female to a male connector.
    [bpi-r1-can-ser.kicad_pcb, can.sch]
2018-08-14 Rename mkkdsn footprint library
    The MKKDSN is a Phoenix Contact terminal block. Rename the footprint
    library to Connector_Phoenix_misc as preperatory step before adding
    a new component.
    [bpi-r1-can-ser.kicad_pcb, power.sch]
2018-08-14 Add footprint for Phoenix Contact IC 2,5/ 3-G-5,08
    The Phoenix Contact IC 2,5/ 3-G-5,08 is a female connector and provide
    more protection against accidental contact then the male MSTBA connector.
    Add the footprint used later on in AC out rework.
    [pxc_1786417_03_IC-2-5-3-G-5-08_3D.stp]
2018-08-14 Rework AC out
    The Phoenix Contact male MSTBA connector used for AC out provides less
    protection against accidental contact. Replace the connector by the
    comparable female connector IC 2,5/ 3-G-5,08.
    [bpi-r1-can-ser.kicad_pcb, power.sch]
2018-08-14 Rework CAN GND connection
    The CAN GND connection may need to separate from common GND of the board.
    Seperate CAN GND from common GND and add Jummper to the make connection
    to common GND switchable.
    [bpi-r1-can-ser.kicad_pcb, can.sch, misc.sch]
2018-08-14 Fix MKKDSN part description
    The part description of MKKDSN is an leftover from a former part does
    not reflect the part. Add documentation and fix the part entries.
    [power.sch]
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2018-08-14 Generate schematic pdf and gerber files for review
    Create a PDF from the schematic and update the gerber files for review.
    [bpi-r1-can-ser-B.Cu.gbl, bpi-r1-can-ser-B.Mask.gbs, bpi-r1-can-ser-B.Paste.gbp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]
2018-08-14 Revisit 3D models
    Some 3D shapes got lost duing rework. Readd the 3D shapes.
    [bpi-r1-can-ser.kicad_pcb, pxc_1757255_08_MSTBA-2-5-3-G-5-08_3D.stp]
2018-08-14 Rename AC connectors
    The generation of the BOM gets confused by different parts with same
    value. Change value of AC connectors to a unique name.
    [misc.sch]
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
